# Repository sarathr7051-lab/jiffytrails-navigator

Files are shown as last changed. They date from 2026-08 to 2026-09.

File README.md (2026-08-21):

# JiffyTrails Navigator

A handlebar-mounted turn-by-turn navigation display for motorcycles. The phone
stays in your pocket and does the routing; an ESP32 device on the bars shows the
current maneuver, distance to it, and arrival time at a glance.

Built for a **Triumph Speed 400** in Bengaluru, where flyovers, service roads and
rapid successive junctions make "arrow pointing at the destination" navigation
useless.

**Status:** working prototype in progress. The navigation data pipeline is
proven; the display hardware is being brought up.

---

## Why

Nothing on the market does this for a non-Royal-Enfield bike. The RE Tripper
(~₹4,750) plugs into the RE wiring harness and pairs through the RE app, and
owner reports say it shows only direction and distance — no ETA. Beeline costs
several times more.

Target cost: under ₹4,000 including tools.

---

## How it works

```
   ANDROID PHONE  (pocket, screen off)
   Google Maps navigating normally
              │
              │  NotificationListenerService reads the ongoing
              │  navigation notification, parses it, and pushes
              │  typed packets at ~1 Hz
              ▼
          BLE GATT
              │
              ▼
        ESP32 (LOLIN32)
              │
              ▼
     2.8" ILI9341 TFT, 240×320
```

Running Maps with the screen off draws a fraction of what a mounted phone does —
on a four-hour ride that's the difference between arriving at 15% and 60%.

---

## ★ The interesting bit

Google Maps has no public API for live guidance. But on **Android 16** it uses
the **ProgressStyle / Live Updates** notification API, which exposes structured
typed extras — not the custom RemoteViews layout that older parsers had to
scrape.

This repo documents the full field mapping, a verified maneuver-icon hash table,
the distance quantisation bands, and the parser rules — all derived from real
rides, not guesswork.

See **[docs/NAV_DATA.md](docs/NAV_DATA.md)**. That's the part worth reading even
if you never build the hardware.

---

## Repo layout

| Path | Contents |
|---|---|
| `docs/NAV_DATA.md` | ★ Google Maps notification reverse-engineering — field mapping, icon hashes, parser rules |
| `docs/BLE_PROTOCOL.md` | Wire format between phone and ESP32 |
| `docs/HARDWARE.md` | Parts, pin mapping, wiring, costs |
| `docs/BUILD_PLAN.md` | Twelve-stage plan with gates and test criteria |
| `docs/PROJECT_STATE.md` | Full running state — decisions, findings, dead ends |
| `android/navdump/` | Diagnostic app that dumps and decodes nav notifications |
| `firmware/navigator/` | ESP32 firmware (in progress) |
| `hardware/mount-design.html` | Technical drawings — quarter-turn mount, sealed enclosure |
| `logs/` | Captured ride logs |

---

## Current status

**Done**
- Navigation data source proven across two real rides
- Six maneuver icon hashes confirmed with zero collisions
- Android diagnostic app working
- ESP32 toolchain verified — compiles, uploads, hash-verified

**In progress**
- Display bring-up (headers need soldering)

**Next gate**
- ★ Daylight readability test. A ~250 cd/m² TFT against 100,000 lux of Bangalore
  noon is the single biggest unknown in the project.

---

## Hardware

| Part | ~₹ |
|---|---|
| ESP32 LOLIN32 | 449 |
| SmartElex 2.8" ILI9341 TFT, non-touch | 815 |
| Breadboard + jumper wires | 204 |
| Soldering kit + multimeter | 1,000 |
| Enclosure, mount, fasteners, sealing | ~840 |
| **Total** | **~3,300** |

Deliberately excluded, with reasons in
[docs/PROJECT_STATE.md](docs/PROJECT_STATE.md): GPS module, magnetometer,
vibration motors, internal battery.

---

## Safety

This is a glanceable instrument, not something to read while riding. It is
designed so that losing the connection produces an obvious failure state rather
than a stale instruction — a navigator that confidently shows the wrong arrow is
worse than one showing nothing.

Voice guidance through a helmet headset remains the better primary channel. This
display is the confirmation layer: audio tells you *when*, the screen tells you
*what*.

---

## Licence

MIT. See [LICENSE](LICENSE).

Not affiliated with Google, Triumph, or BOBO. Notification parsing relies on
undocumented internals and may break with any Maps update.

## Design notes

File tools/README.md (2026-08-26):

# tools — testing the navigator without a phone

`navsim.py` pretends to be the Android app that does not exist yet. It connects
to the ESP32 over BLE from a Windows laptop and writes protocol packets exactly
as `docs/BLE_PROTOCOL.md` specifies, printing every packet as hex next to what
it means, so the laptop console and the ESP32 serial monitor can be read side by
side.

It never opens a COM port and never flashes anything. Keep the Arduino IDE's
serial monitor open at 115200 while it runs — that is half the test.

The acceptance tests it is built for are in `docs/STAGE5_TEST_PLAN.md`.

---

## Install

You need Python 3.9 or newer. **This machine does not have Python yet.**

1. Get it from [python.org/downloads](https://www.python.org/downloads/) —
   the "Windows installer (64-bit)".
2. During setup, tick **Add python.exe to PATH**. If you miss it, the `py`
   command below will not exist and you will have to re-run the installer.
3. Do *not* use the Microsoft Store stub. Typing `python` on a fresh Windows 11
   opens the Store instead of running anything; that is the stub, not Python.
4. Then, in PowerShell:

```powershell
py -m pip install bleak
```

`bleak` is the only dependency. It talks to the Windows BLE stack directly — no
dongle, no driver, no pairing.

Check it worked, with no hardware attached:

```powershell
py C:\dev\jiffytrails-navigator\tools\navsim.py --selftest
```

Every line should say `PASS`. This also prints the corrected version of the
worked example from `BUILD_PLAN.md` (see "The spec bug", below).

---

## Find the device first

```powershell
py navsim.py --scan
```

This lists everything advertising nearby. The ESP32 advertises as
**`JiffyTrails`** (`DEVICE_NAME` in `navigator.ino`), which is what every other
mode matches by default. If the firmware advertises something else, add
`--name <name>` or `--address <address>` to any command below.

**Do not pair the ESP32 in Windows Bluetooth settings.** This protocol needs no
pairing, and a stale Windows pairing is the most common reason a connect starts
failing after it previously worked. If it shows up under Settings → Bluetooth &
devices, remove it.

Only one central can be connected at a time. Close nRF Connect on the phone
before running the laptop tool, and vice versa.

---

## The modes

Run everything from this folder, or give the full path to the script.

### `--ride` — the one that matters

```powershell
py navsim.py --ride
```

Replays a scripted Bengaluru route at 1 Hz: eight legs, about 6 km, roughly ten
minutes. It uses the real Google Maps behaviours from `docs/NAV_DATA.md`, not a
tidy simulation:

- **Distances are quantised** — 100 m steps above 1 km, 50 m from 1 km down to
  300 m, 10 m below 300 m.
- **Values are rounded to the band, not stepped through it**, so at speed the
  digits *skip*: 290 → 270 → 250 → 230. This is deliberate. A smooth countdown
  would flatter the display and hide the flicker that actually matters.
- **The remaining distance drifts** by a few percent every packet, because
  `progressMax` does. It must be recomputed on every packet, never cached.
- **`next_maneuver` is always UNKNOWN/0**, because Google Maps does not expose
  a next maneuver. Anything the display does with that field must survive it
  being empty forever.
- A **rerouting** state fires on leg 4 and a **gps_weak** state on leg 6.
- The route ends with an explicit **`nav_active = 0`**. Silence is ambiguous;
  "not navigating" is not.

Useful flags:

| Flag | Effect |
|---|---|
| `--speed-mult 4` | Ride four times faster. Same 1 Hz packet rate, so the digits skip much harder — the worst case for the distance field |
| `--reconnect` | Rescan and reconnect if the link drops, and time the recovery. This is the laptop half of the walk-30-m-away test |
| `--seed 1234` | Change the jitter. The same seed always replays identically |
| `--dry-run` | Print the packets without touching Bluetooth |

**Correct behaviour:** every packet on the laptop console has a matching line on
the ESP32 serial. The distance on the panel matches the `dist=` field in the
decoded line. During the reroute the screen says REROUTING and **no arrow is
drawn**, even though the packet still carries `maneuver=ROUNDABOUT`. At the end
the panel drops to the idle screen and keeps no trace of the last maneuver.

### `--screen <name>` — hold one state for a photograph

```powershell
py navsim.py --screen now
```

Holds a single state at 1 Hz indefinitely, so the watchdog stays quiet and you
can photograph the panel at arm's length. Ctrl+C to stop.

| Name | State |
|---|---|
| `far` | 1.2 km — instruction, medium distance, ETA, remaining km |
| `approach` | 350 m — distance large, arrow large |
| `committed` | 80 m — full-screen arrow and distance, nothing else |
| `now` | 20 m — inverted colours |
| `idle` | `nav_active = 0` — clock and trip stats, never a maneuver |
| `rerouting` | REROUTING, arrow suppressed |
| `gps_weak` | Normal nav screen plus a small corner warning |
| `arrived` | Destination reached |
| `unknown` | Maneuver `0x00` — must render `?`, never a guessed arrow |
| `longtext` | The 59-character instruction observed in the wild |
| `roundabout` | Reserved code `0x23` (roundabout, exit 3) |
| `battery` | A STATUS packet — must not disturb the nav screen |
| `trip` | A TRIP packet |

**Correct behaviour:** anything you cannot read in half a second at arm's length
is too small. That is the actual test.

### `--stale` — prove the 10 s watchdog fires

```powershell
py navsim.py --stale
```

Sends normally for ten seconds, then stops dead **while staying connected**, and
counts the seconds out loud. After 25 s it starts sending again.

**Correct behaviour:** the panel dims and shows STALE about 10 s after the last
packet. It must **not** show PHONE DISCONNECTED — the link is still up, and
confusing a dead link with dead data is a failure. When packets resume, the nav
screen returns within one packet, with no reset and no button press.

This is the test that catches a change-based watchdog. `NAV_DATA.md` measured
64 seconds with no field changing at all while Maps kept posting at 1 Hz, so the
watchdog must count packet *arrivals*.

### `--flood` — tearing and heap growth

```powershell
py navsim.py --flood
```

Sends at 20 Hz for 30 seconds — roughly twenty times the real rate — with values
that change on every packet, then settles back to 1 Hz. Tune with
`--flood-rate` and `--flood-seconds`.

**Note the ESP32's free heap before and after.** A few hundred bytes of jitter is
normal; a steady downward slope is a leak in the packet handler.

**Correct behaviour:** no torn digits, no half-drawn arrow, no reset, no heap
trend. Dropping packets under flood is fine — the display cannot usefully redraw
at 20 Hz anyway — but it must never render a partial frame. Afterwards the panel
settles to a clean, steady screen.

### `--garbage` — malformed input

```powershell
py navsim.py --garbage
```

Sends every malformed packet in the tool's list, a second and a half apart:
empty writes, truncated payloads, a length byte that lies in both directions,
unknown packet types, a 200-byte instruction against a 64-byte buffer, invalid
UTF-8, an embedded NUL, an undefined maneuver code, and 256 bytes of noise. It
starts from a known-good screen and **ends with a valid packet**.

**Correct behaviour:** the ESP32 does not reboot, the BLE link stays up, free
heap is unchanged, and the final valid packet renders correctly. That last one
is the real test — a parser that rejects everything afterwards has failed just
as badly as one that crashes.

Each packet's `EXPECT:` line says whether it should be rejected or accepted, so
read those rather than assuming every case leaves the screen alone. Two of them
are *supposed* to be accepted: the current firmware treats the `len` byte as
advisory and bounds every read by the ATT write length instead, so a `len` that
undercounts is tolerated while a `len` that overcounts is dropped. The safety
property under test is that nothing is ever read past the end of the write.

The undefined maneuver code must render `?`. A confidently wrong arrow is worse
than no arrow.

### `--nrf` — hex strings for the phone

```powershell
py navsim.py --nrf
```

Prints the packets as hex, with decodes, ready to paste into nRF Connect's write
field. No Bluetooth is used, so this works on any machine. Same strings as
`docs/STAGE5_TEST_PLAN.md`.

### `--selftest` — check the tool, not the firmware

```powershell
py navsim.py --selftest
```

Encoding and decoding round trips, the quantisation bands, and every named
screen — all offline. Run this after changing the script, and before blaming the
firmware for anything.

---

## Reading the output

```
14:22:07.412 TX  26B  01 18 03 64 00 02 50 00 0C 00 20 00 01 4F 6C 64 20 4D 61 64 72 61 73 20 52 64
             NAV len=24 maneuver=TURN_RIGHT(0x03) dist=100 m next=UNKNOWN(0x00)/0 m eta=12 min remaining=3.2 km flags=0x01[nav_active] instr="Old Madras Rd"
             EXPECT: UI_NAV_COMMITTED - full-screen arrow + distance, nothing else
```

- `TX` is laptop → ESP32, `RX` is a notification coming back.
- The decode line is what the bytes *say*. Compare it with the ESP32 serial
  line for the same instant — they must agree field for field.
- The `EXPECT` line is what the panel should be showing, derived from
  `screenFor()` in `firmware/navigator/nav_types.h`. If the decode is right and
  the panel disagrees with EXPECT, the bug is in the display, not the parser.

---

## The spec bug

`docs/BUILD_PLAN.md` Stage 5 gives this worked example:

```
01 0F 03 64 00 02 50 00 0C 00 20 00 01 + "Old Madras Rd"
```

**The field order and every value in it are correct. The length byte is not.**

The NAV payload is 11 fixed bytes (`u8 + u16 + u8 + u16 + u16 + u16 + u8`) plus
the 13-byte instruction — 24 bytes, `0x18`. The example says `0x0F`, which is
15, and matches neither the 11 bytes printed after it nor the 24 the packet
actually carries. Corrected:

```
01 18 03 64 00 02 50 00 0C 00 20 00 01 4F 6C 64 20 4D 61 64 72 61 73 20 52 64
```

Everything in this folder and in `docs/STAGE5_TEST_PLAN.md` uses the corrected
form. Details in the test plan.

---

## When it does not work

| Symptom | Cause |
|---|---|
| `'py' is not recognized` | Python is not installed, or PATH was not ticked during install. Re-run the installer |
| `python` opens the Microsoft Store | That is the Store stub. Install real Python from python.org |
| `bleak is not installed` | `py -m pip install bleak` |
| `no BLE device matching 'JiffyTrails'` | Wrong name — run `--scan` and pass `--name`. Or the ESP32 is not advertising: check its serial output. Or something else is already connected to it |
| Scan finds nothing at all | Bluetooth is off. Toggle it off and on once; the Windows BLE stack gets stuck |
| Connects, then "navigator service was not found" | The ESP32 is running different firmware, or the UUIDs in `ble.cpp` do not match `docs/BLE_PROTOCOL.md` |
| Connect worked yesterday, fails today | Windows cached a pairing. Settings → Bluetooth & devices → find it → Remove device |
| Everything stalls after a few minutes | Something else grabbed the adapter. Close nRF Connect for Desktop |

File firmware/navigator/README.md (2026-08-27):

# ESP32 firmware

**Status: display bring-up COMPLETE (22 Aug 2026).** Panel renders graphics and
text correctly through all rotations. Firmware itself not yet written.

## Setup

`User_Setup.h` here is a reference copy. The live file the compiler actually
reads is `<sketchbook>/libraries/TFT_eSPI/User_Setup.h`, and on this machine
the sketchbook is **`C:\dev\Arduino`** — see the sketchbook section in
`docs/HARDWARE.md` before editing anything, including the OneDrive decoy that
wasted a session.

Working configuration:

| Setting | Value |
|---|---|
| Driver | **`ILI9341_2_DRIVER`** (not `ILI9341_DRIVER`) |
| SPI_FREQUENCY | **27000000** on breadboard |
| CS / DC / RST | 15 / 2 / 16 |
| MOSI / SCLK / MISO | 23 / 18 / 19 |

Verify with **Examples → TFT_eSPI → Test and diagnostics → Read_User_Setup**
before anything else. It prints back what the compiler actually used, which
catches a mistyped pin or a wrong-file edit in seconds. Then
**Examples → TFT_eSPI → 320 x 240 → TFT_graphicstest_one_lib**.

Note Read_User_Setup prints inside `loop()`, so the output repeats forever —
that is normal, not a boot loop. One cycle ends at `[/code]`.

## White screen checklist

In order of likelihood, learned the hard way:

1. **You edited a `User_Setup.h` that isn't the one being compiled.** Check
   `directories.user` in `~/.arduinoIDE/arduino-cli.yaml`, then confirm with
   Read_User_Setup that a value you changed actually changed. Everything below
   is a waste of time until this is ruled out.
2. Wrong init sequence — try **`ILI9341_2_DRIVER`**. Flat white or vertical
   stripes with correct pins is the signature. Note the printed driver ID stays
   `9341` either way, so verify via the SPI frequency line instead.
3. RESET wired to GPIO 4 instead of **16**
4. SPI too fast for breadboard — drop to **27 MHz**
5. A jumper not fully seated — swap the suspect wire before touching config
6. Unsoldered or cold headers. SPI will not tolerate a marginal contact even
   though DC power gets through fine

## Planned structure

```
navigator.ino     entry, setup, main loop
ble.cpp           NimBLE peripheral, packet parse, reconnect
display.cpp       screen states, distance bands, failure states
maneuvers.cpp     vector arrow drawing
watchdog.cpp      stale detection — counts arrivals, not changes
ota.cpp           WiFi OTA — must work before the case is sealed
```

Use TFT_eSPI **sprites for the distance field only**. A full-screen sprite
won't fit in plain ESP32 RAM.

Draw maneuver arrows as **vector paths**, not bitmaps — scalable, and a fraction
of the flash.

## Related sketches

`../sunlight_test/sunlight_test.ino` — Stage 4 Test B. Cycles the six real UI
states so daylight readability can be judged against the actual design rather
than the library graphics test, which draws thin coloured lines on black and is
close to a worst case.

`../ui_mock/ui_mock.ino` — the nav interface driven by a scripted ride, no BLE.
Distances count down at 1 Hz with the real Google Maps quantisation, maneuvers
change, and every failure state fires on a timer. Serial keys jump straight to
any state. This is where the interface gets finalised before BLE work starts;
its drawing code becomes `display.cpp`.

---

## Stage 5 — known limitations and landmines

Written down 26 Aug 2026 while the BLE link was built. None of this is blocking;
all of it will cost an evening if rediscovered.

**Packet parsing runs on a different task from rendering.** NimBLE delivers
writes on its host task; `displayRender()` reads `NavState` on the loop task.
There is no lock, so a render can in principle catch a half-updated
`instruction[]`. At 1 Hz the window is tiny and the next frame corrects it, so
the visible worst case is one frame of garbled road name. **If it ever matters,
the fix is to stage the raw frame bytes in `onWrite` and parse them in
`bleTick()`**, moving all mutation onto the loop task. Left as-is for now
because untested restructuring is a worse risk than a one-frame cosmetic fault.

**xtensa gcc 14 (esp32 core 3.3.11) ICEs on a specific construct.** A
namespace-scope function-pointer type that names a class from an *anonymous*
namespace crashes the compiler with a segfault — it appeared as a failure on
`struct PacketHandler` with no useful diagnostic. `PacketReader` is therefore at
file scope rather than in an anonymous namespace. Do not "tidy" it back.

**`NavState.linkUp` has exactly one writer: `watchdogTick()`.** It derives the
value from `bleConnected()` once per loop because it needs the
disconnected→connected *edge* to restart the freshness clock. `ble.cpp`
deliberately does not set it — an earlier version did, which consumed the edge
and silently made the reconnect branch dead code.

### Regressions against `ui_mock`, both from missing protocol rows

- **No traffic bar.** Needs `0x07 TRAFFIC` specified and a `NavState` field.
- **Idle screen shows "READY", not a clock and trip stats.** Needs a time source
  and `0x05 TRIP`. A fabricated clock on a handlebar is worse than none.

### Maneuver glyphs that are approximations

SHARP_LEFT/RIGHT draw as ordinary turns; KEEP, FORK and EXIT all draw as slight
turns — correct side, less specific meaning. FLYOVER, UNDERPASS and FERRY render
`?` on purpose: Maps emits no icon for them (NAV_DATA.md), so they can only
arrive from an unvalidated source, and a CONTINUE arrow would be a confident
claim that the road runs straight through. Roundabout exits `0x20`–`0x2F` draw
the ring plus the exit **number**, because exit angles are not evenly spaced and
a generic exit stub would point the wrong way.

## Two sketches

**`firmware/navigator/`** is the real thing: the phone drives it over BLE.

**`firmware/ui_mock/`** is the same display with no phone and no radio. It boots
straight into a scripted ride from Panampilly Nagar to Fort Kochi Beach and
loops it — distances count down at a real speed, the screen crosses every band,
every maneuver glyph appears, and the route ends on the arrival screen before
starting again. Useful for judging the interface at mount distance without
pairing anything, and it is half the flash because there is no BLE stack.

Both accept the same serial keys at 115200:

| key | |
|---|---|
| `r` | the scripted ride |
| `g` | glyph parade — every maneuver, named as it draws |
| `a` | alerts — call and message, riding and parked |
| `b` | replay the boot sequence |
| `x` | stop (in `navigator`, hands the display back to the phone) |

### Keeping them in sync

`firmware/ui_mock/src/` holds **generated copies** of the shared sources. Do not
edit them. After changing anything in `firmware/navigator/`:

```
perl tools/sync_ui_mock.pl
```

and `perl tools/sync_ui_mock.pl --check` fails if they have diverged.

Copies rather than includes because arduino-cli *and* the IDE both copy a sketch
into a build directory before compiling, so a relative `#include` pointing
outside the sketch resolves against the copy and finds nothing.

This matters more than it looks. The previous `ui_mock` was a hand-maintained
second implementation of every screen, and it drifted until it had nine
maneuvers, an enum where left was `MV_LEFT`, and a traffic bar the firmware had
removed — a mock showing a UI the device no longer had. The copies are
mechanical and the check makes drift an error instead of something you discover
on the panel.

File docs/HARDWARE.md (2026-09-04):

# Hardware

## Bill of materials

| Part | Detail | ₹ |
|---|---|---|
| ESP32 **LOLIN32** | USB-C, CH340 USB-serial | 449 |
| **SmartElex 2.8" TFT** | ILI9341, SPI, 240×320, **non-touch** | 815 |
| MB102 breadboard | 830 points | 65 |
| Jumper wires | M2M / M2F / F2F, 20 each | 139 |
| Soldering kit + multimeter | 60 W adjustable, pump, wick, flux, stand | 1,000 |

### Still to buy — ★ REWRITTEN 1 Sep 2026, THE OLD LIST BOUGHT THE WRONG PARTS

The line here used to read "polycarbonate window, clear RTV, M8 cable gland,
M3/M4 fasteners, anti-glare film, PETG filament". **Three of those parts are not
in the design and three that are were missing.** Against `hardware/case.scad`:

| Part | Detail | Why |
|---|---|---|
| **ASA filament, light coloured** | **not PETG, never PLA** | PETG's HDT is 65–80 °C against a sealed interior estimated at 53–70 °C in Bengaluru sun. See the Enclosure section. |
| **Closed-cell EPDM foam tape, 3 mm** | 4 mm wide, closes to 2 mm = 33% compression | The seal. `foam_w = 4.0`, `foam_d = 2.0`. ★ **Closed-cell, NOT open-cell polyurethane** — most cheap foam tape is open cell and wicks like a sponge. Test it: hold a piece under water and squeeze. Open cell streams bubbles and stays wet. |
| **M3 self-tapping screws** | **8 × M3 × 14** (cap → lid → body), **2 × M3 × 5** (hood) | ★ **REWRITTEN 3 Sep 2026 for the bayonet mount** — the line above used to say 8 × 12, 4 × 8 and 2 × 6, and all three were for the dovetail. The eight now run through **three** parts as one fastener set: 2.4 mm of mount cap under its counterbore, 5.0 mm of lid, then a 2.5 mm pilot 9.0 mm blind into the body. ×14 gives 6.6 mm of thread and never bottoms; ×12 gives 4.6 and ×16 is 0.4 mm from the floor. ★ **PAN head** (DIN 7981, 5.6 × 2.4), not socket cap: the cap's counterbore is 2.6 mm deep and a DIN 912 cap head is 3.0 mm tall, so it stands proud into the collar. ★ **The hood's two are ×5, NOT ×6** — `hood_pilot_len` is 4.0 mm blind over a 2.0 mm floor and a ×6 bottoms out before the hood is tight. ★ **There is no mount plate any more**; its 4 × M3 × 8 are deleted. Measured off the printed geometry, not the drawing: cap, lid and body carry the same eight positions, verified by solid intersection. |
| **M3 brass heat-set insert** | 1, for the mount adapter | The BM4's screw runs socket → plate into a brass insert, so our part carries the female thread. `MOUNT_INTERFACE.md` §3. ★ **Not for the case** — `case.scad` rejects inserts there: they need a 4.0 mm bore and 1.6 mm of wall either side, costing 2.4 mm of envelope in both directions, and eight iron-driven insertions into a part that cannot be reprinted. |
| **ePTFE membrane, Ø6 vent** | can be cut from an old rain jacket | Free |
| **Potting compound** | clear RTV or epoxy, for the cable entry | ★ **No cable gland.** See below. |
| **USB-C cable, ≤ Ø4.5 mm** | thin, right-angle at the bike end; the far plug is cut off and soldered inside | ★ `cable_bore_d = 4.5` and the case is printed. A braided cable is 5–6 mm and will not go through. Measure with a paper strip: circumference ÷ 3.1416. |
| **Power protection** | SMBJ6.0A TVS, 220 µF hybrid/polymer 16 V, 100 nF ceramics, ferrite bead, 1 A polyfuse | `FEATURES.md` "Decision: cable power, no battery". ★ 6.0A not 5.0A. ★ Polymer, not 85 °C electrolytic. |
| **USB power meter** | inline, cheap | Answers whether the Speed 400's socket is ignition-switched or always live, and its real current. Nobody has measured either. |
| Anti-glare film | cut from a phone screen protector | Sunlight section |

**Deleted, and do not buy:**

- **M8 cable gland** — ★ the entry is **potted**. An M8 gland's Ø14 locknut needs
  16 mm of clear flat wall on the inside, in a position this case does not have.
- **Polycarbonate window** — ★ **there is no separate window.** The front is
  closed and the panel is bonded behind it; `bezel()` does the precise work. A
  window with an air gap in front of the panel is also the wrong answer
  optically — see the Enclosure section.
- **M4 fasteners** — nothing in `case.scad` or `mount_v4.scad` uses M4. The only
  bolt in the whole mount is the BM4's own ISO 10642 M3 × 10 countersunk, which
  you already have. (`mount.scad`, which carried an M4 rule, is the abandoned
  dovetail design and is not what is printing.)

**Deliberately excluded:** GPS module, magnetometer, vibration motors, internal
battery. Reasons in PROJECT_STATE.md.

## Pin mapping

**Status: VERIFIED WORKING 22 Aug 2026.** `TFT_graphicstest_one_lib` renders
correctly through all rotations on this wiring.

| Display | LOLIN32 |
|---|---|
| VCC | 3V |
| GND | G |
| CS | GPIO 15 |
| RESET | **GPIO 16** |
| DC | GPIO 2 |
| SDI (MOSI) | GPIO 23 |
| SCK | GPIO 18 |
| SDO (MISO) | GPIO 19 |
| LED | **GPIO 17** |

### Gotchas

**★ LED goes to GPIO 17, NOT to 3V3.** This table said `3V` until 29 Aug 2026
and it was wrong - `backlight.cpp` has owned GPIO 17 through the LEDC PWM
peripheral since the day/night dimming went in. Wiring LED to 3V3 leaves the
backlight stuck at full brightness with no dimming. Wiring it to BOTH - which
is what someone following the old table *and* the firmware would do - shorts
3V3 to ground through GPIO 17 every time the firmware dims, and that damages
the pin. One wire, to GPIO 17.

**RESET is GPIO 16, not 4.** GPIO 4 is not broken out on the LOLIN32. Most
ILI9341 tutorials say 4, and following them gives you a white screen.

**No series resistors.** The vendor manual specifies 10 K on every signal line
and 5 V on VCC — that is for a 5 V Arduino. The ESP32 is natively 3.3 V; wire
straight through.

**3.3 V is sufficient** despite the module carrying an AMS1117 regulator.
Verified on the bench: **3.18 V measured at the `3V` pin with the backlight
lit** (22 Aug 2026, DT-830D on DCV 20). A 4 % droop off nominal — fine, but
that is the LDO working rather than coasting. Re-measure if anything else is
ever added to the 3.3 V rail.

### ★ Backlight control — GPIO 17, PWM, and NO EXTERNAL TRANSISTOR

★ This section used to open "`LED` is tied straight to `3V`, the backlight is
therefore always on at full brightness". **Both halves are stale.**
`backlight.cpp` has driven GPIO 17 through the LEDC PWM peripheral (20 kHz,
10-bit) since day/night dimming went in, and the pin table above is the wiring.

★ It also said `User_Setup.h` "reserves `TFT_BL 17` and `TFT_BACKLIGHT_ON HIGH`,
commented out, for when this changes". **Those two defines must STAY commented
out, and not by oversight.** Defining `TFT_BL` makes TFT_eSPI drive the same pin
during init, and two owners on one GPIO fight: the library's plain
`digitalWrite` tears down the LEDC channel `backlight.cpp` attached. The
backlight is not TFT_eSPI's job in this build.

**★ CORRECTED 29 Aug 2026 — no external switch is needed. The module already
has one.**

This section used to say the LED pin was the backlight supply, that it drew
60–100 mA, and that it therefore needed an added MOSFET or an NPN. The
[LCDWIKI MSP2807 schematic][msp2807sch] says otherwise, traced net by net:

```
3.3V ──> LEDA ─[4 white LEDs in parallel]─ LEDK ──[R5 10R]──┐
                                                  collector ┴
  header "LED" ──[R6 1k]── base ────────────────►  Q1  S8050 (NPN)
                                                    emitter ┬
                                                           GND
```

The LED pin is **a logic-level control input to an on-board low-side NPN**, not
a supply rail. That is why the wiki describes it as "high level lighting". The
current an ESP32 pin actually sources into it is base current:

```
(3.3 - 0.7) / 1000 = 2.6 mA
```

against a 40 mA absolute maximum. **Wire GPIO 17 straight to the LED pin and
PWM it.** No transistor, no gate resistor, no pulldown. `backlight.cpp` needs
no change — it was already only ever driving a pin.

The 60–100 mA figure was right about the *panel* (QD-TFT2803: Vf 3.2 V, If
60 mA nominal, 80 mA max) and wrong about this *module*, which runs those LEDs
off 3.3 V through a 10 Ω series resistor — so somewhere near 15–40 mA. Worth
knowing for the sunlight problem: **this backlight is already running well
under its rated current.**

★ **Confirm it in ten seconds before soldering, because this family of boards
is not consistent** — some genuinely do bring the LED supply straight out, and
Adafruit's own 2.8" breakout has a transistor while other sellers' do not. Put
a **1 kΩ resistor in series** between 3.3 V and the LED pin:

- backlight stays at **full brightness** → there is a transistor, drive it from
  the GPIO as above
- backlight goes **almost dark** → the pin is the LED supply after all, and the
  old advice applies: fit a 2N7000 low-side switch

[msp2807sch]: https://www.lcdwiki.com/res/MSP2807/MSP2807-2.8-SPI.pdf

**The `+` beside the white connector is the LiPo JST terminal**, not a 5 V
header pin. `VP` and `VN` are GPIO 36 and 39, analog inputs — not power.

**The USB chip is CH340, not CP2102**, despite what some listings say. Windows
has a built-in driver; no install needed.

If the module exposes touch pins, leave them unconnected except **T_CS → 3.3 V**
so the touch controller stays off the shared SPI bus.

**This panel needs `ILI9341_2_DRIVER`, not `ILI9341_DRIVER`.** Same chip ID,
different init sequence ([TFT_eSPI issue 1172][1172]). Under the stock
`ILI9341_DRIVER` this display gave flat white, then vertical stripes once the
pins were corrected — the controller was receiving SPI but never initialising.
The alternative sequence brought it up first try. A second panel from a
different batch may want the other one; try both before assuming a fault.

[1172]: https://github.com/Bodmer/TFT_eSPI/issues/1172

**Run the bus at 27 MHz on breadboard**, not the 40 MHz default. Dupont jumpers
and an MB102 do not hold 40 MHz cleanly. Worth raising again once the build is
soldered — but retest, do not assume.

Worth knowing why 27 is a sensible fallback rather than an arbitrary one:
**27 MHz is TFT_eSPI's documented ceiling for *reading back* from the display**,
not for writing. For write-only rendering the library's own guidance is that
"40MHz seems to be OK with ILI9341 displays", with 80 MHz the point where the
controller starts failing. So 40 MHz should be reachable once the wiring is
soldered — **48% more bandwidth**, which matters directly for moving graphics.

★ **CORRECTED — THE FIRMWARE DOES READ THE PANEL, AND READS HAVE THEIR OWN
CLOCK.** The reasoning above used to close with "since this project never calls
`readPixel`". That is no longer true. `display.cpp` runs a boot probe
(`panelReadable`) and re-reads `MADCTL` twice every two seconds; **that watchdog
is the one mechanism that can recover the mirrored-screen fault**, and it
disarms itself if the reads come back as garbage.

Reads and writes are separately clocked, which is what makes raising the write
clock safe:

```
User_Setup.h    SPI_FREQUENCY       27000000   writes  <- raise this to 40 MHz
                SPI_READ_FREQUENCY   6000000   reads   <- LEAVE THIS ALONE
```

**6 MHz, not 20.** MISO is wired, yet at 20 MHz the boot probe kept returning
garbage and disarming the watchdog — so the recovery mechanism was switched off
by a number, not by a missing wire. Reads happen twice every two seconds and
their speed is worth nothing.

**Check the boot line before and after any SPI change.** If it says "watchdog
armed", the watchdog is real and a corrupted MADCTL heals itself within six
seconds instead of persisting until a power cycle. If it says "DISABLED", the
read clock is too fast or MISO is not connected.

For reference, a 320×240 RGB565 frame is 153,600 bytes = 1,228,800 bits:

| SPI clock | Wire time per full frame | Theoretical max FPS |
|---|---|---|
| 27 MHz | 45.5 ms | 22.0 |
| 40 MHz | 30.7 ms | 32.6 |

Measured TFT_eSPI `fillScreen` on ESP32 + ILI9341 at 40 MHz comes in at 31.2 ms
— about 98% of theoretical, which confirms the SPI wire is the wall and the
ESP32 can saturate it.

## Toolchain

Arduino IDE 2.x **from arduino.cc** — not the Microsoft Store build, which is
1.6.11 from 2016 and sandboxed.

Boards Manager URL:
```
https://raw.githubusercontent.com/espressif/arduino-esp32/gh-pages/package_esp32_index.json
```

Board: **WEMOS LOLIN32**.

### Upload from the Arduino IDE, not the command line

Sketches flashed with `arduino-cli` reported a clean write and verified hash,
the sketch ran and printed to serial — and the panel stayed white. The same
sketch uploaded through the IDE worked immediately, with nothing physical
changed in between. The board options are identical between the two
(`CPUFreq=240`, `FlashFreq=80`, same partition scheme), so the cause is not
board configuration and has not been pinned down.

Probable culprit: opening the serial port from a script toggles DTR/RTS, which
on this board drives the auto-reset circuit (EN and GPIO 0). That can leave the
ESP32 held in reset or sitting in download mode — the sketch is in flash and
appears fine, but nothing drives the display.

**Practical rule: upload through the IDE, and don't open COM11 from a script
while debugging the display.** An hour was lost to this, chasing a wiring fault
that did not exist.

### Sketchbook location — read this before editing any config

**The sketchbook on this machine is `C:\dev\Arduino`.** The live TFT_eSPI
config is therefore:

```
C:\dev\Arduino\libraries\TFT_eSPI\User_Setup.h
```

That is authoritative, not a guess — it is `directories.user` in
`C:\Users\sarat\.arduinoIDE\arduino-cli.yaml`. **Check that file rather than
trusting an assumed Documents path.**

**The trap that cost a full session:** OneDrive's Documents folder here is
localized to Japanese and is literally named `ドキュメント`. A second, stale
TFT_eSPI lives at

```
C:\Users\sarat\OneDrive\ドキュメント\Arduino\libraries\TFT_eSPI\
```

`%USERPROFILE%\Documents` contains no Arduino folder at all, so anything
reasoning about "Documents\Arduino\libraries" lands on the OneDrive copy — which
is never compiled. Every edit went there and changed nothing, which made two
correct fixes look like failures. **That copy is dead. Do not edit it.** Delete
it if you want the trap gone for good.

`firmware/navigator/User_Setup.h` in this repo is a reference copy; keep it in
sync with the live file by hand.

**Always confirm an edit landed before drawing conclusions from it.** Run
Read_User_Setup and check a value you know you changed. Note that swapping
`ILI9341_DRIVER` for `ILI9341_2_DRIVER` does *not* change the printed driver ID
— both report `9341`. Verify against `Display SPI frequency` or a pin instead.

## ★★ Sunlight readability — do the arithmetic before the test

Researched 22 Aug 2026, ahead of running Stage 4 Test B. **The numbers say a
bare ILI9341 fails in direct Bengaluru noon sun.** Worth knowing before the
test rather than being surprised by it.

### The governing equation

Glare is not subtractive, it is *additive light* laid over the whole panel:

```
L_reflected = E × R / π          E = ambient lux, R = front-surface reflectance
ACR = (L_white + L_reflected) / (L_black + L_reflected)
```

Readable text needs **ACR ≥ 5:1**. Maps and detail want 10:1.

### This panel, this city

Bengaluru clear-sky noon is **~100,000 lux**. A generic ILI9341 module has a
glossy overlay with an air gap, so R ≈ 4.5%.

```
L_reflected = 100000 × 0.045 / π ≈ 1430 nits of grey haze
ACR = (250 + 1430) / 1430 ≈ 1.17 : 1
```

Against a requirement of 5:1. **That is not marginal, it is a grey rectangle.**
Practitioner reports of ILI9341 outdoors agree — washed out, unreadable.

Note what the equation says about mitigation: **cutting ambient light beats
raising backlight.** A 5× reduction in E from a hood does more than a 4×
brighter backlight, and costs a 3D print. Even a 1000-nit panel behind the same
cheap air-gapped front only reaches 1.7:1 — commercial units optically bond and
AR-coat down to ~1% reflectance to get anywhere.

Measured brightness for these modules, where published at all: Winstar
500 cd/m², POLCD ~300, TST28011T 275. Most listings publish nothing.

### Mitigations, cheapest first

1. **Free — rotate the panel 90° and test with the sunglasses you ride in.**
   See the polariser note below. Do this before the enclosure is designed.
2. **₹150–400 — a deep matte-black hood**, 25–35 mm, ribbed or flocked inside.
   Biggest single win available. Attacks E directly.
3. **₹150–300 — matte anti-glare film** cut from a phone screen protector,
   applied *directly to the panel*. AG diffuses rather than eliminating, and
   softens the image — irrelevant when the content is a giant arrow.
4. **Free — the single-glyph layout.** Everything converges to grey in glare, so
   contrast has to come from area and shape, not colour. Never encode anything
   load-bearing in colour alone. This is already the design.
5. **Mount angle** — a screen tilted face-up mirrors the sky. Tilt it toward the
   rider, away from the zenith.

### ★ Polarised sunglasses will black this out, and the fix is free

Every LCD emits **linearly polarised** light. Polarised sunglasses are a linear
polariser. Cross the two at 90° and the screen goes **completely black** — and
it is head-angle dependent, so it comes and goes while riding.

Consumer panels put the polariser axis vertical or horizontal, so **rotating the
module 90° in the enclosure rotates its axis 90°** and can flip it from
invisible to fully visible through polarised lenses.

**This is the highest-value free experiment in the project. Test both
orientations with your own riding sunglasses before the housing is finalised.**

Two things not to do:
- **Do not add a linear polariser sheet** as a DIY anti-glare measure. It either
  halves the brightness or creates the exact blackout it is meant to prevent.
- **A circular polariser (quarter-wave retarder) is the proper fix** but absorbs
  a large fraction of emitted light. At 250 nits that is unaffordable. Only
  viable on a bright panel.

### Plan B, budgeted from the start rather than treated as failure

If hood + film + layout still is not enough at 13:00 on a clear day, the answer
is a part swap, not more mitigation:

| Option | Cost | Trade |
|---|---|---|
| **Sharp Memory LCD 2.7" 400×240** (Adafruit 4694) | ~$45 | **Reflective — gets brighter as the sun does.** ~20% reflectivity in 100k lux ≈ 6400 nits equivalent white. Near-zero power, LCD-speed refresh, 13.5 KB framebuffer fits ESP32 easily. Monochrome, and needs a front light at night. **This is what Garmin Edge and Wahoo use, and why they never publish a nits figure.** |
| 1000-nit sunlight-readable 2.8" IPS 240×320 (Orient Display / Newhaven / Chenghao) | ₹1,500–4,000 + import | Drop-in for the SPI code and keeps colour. Heavy backlight current. Still needs the hood — 1000 nits alone does not solve it. |

A turn arrow and a distance number do not need colour. The Memory LCD is
arguably the technically correct part for this job and always was.

### Calibration point in our favour

**Beeline Moto II publishes no nits figure at all and is widely reported as
readable in bright sun.** Reviewers credit the tiny 1.45" screen, extremely high
contrast, anti-glare coating and auto-backlight — not raw brightness. The design
lever matters as much as the panel.

## Mount

Reuses a **BOBO BM4** phone mount: handlebar clamp → **Ø17 mm ball** (VERIFIED)
→ collet + collar → socket → phone plate.

★ **THE JAW BROKE. THE PLATE DID NOT.** This section used to say "the copper jaw
plate (the part that broke) is discarded". Only the **jaw** — the sprung grip
that holds a phone — failed, and the jaw is not used here. **The plate is
undamaged and is kept**: it is the measurement reference for the interface, and
the fallback if a printed part disappoints.

★ **THE MOUNT IS NOT METAL.** The socket and the plate are both polymer. **The
only metal in the whole mount is one ISO 10642 M3 × 10 countersunk screw.**

The printed adapter takes the plate's place in the stack, which means it has to
reproduce the plate's own interface to the socket:

- a **square cavity** — ★ CORRECTED 2 Sep 2026: the socket's square
  **protrudes** 2.0 mm and the plate's is the recess, not the other way round.
  Ours is 14.5 mm across flats, 2.42 mm corner radius, **2.20 mm deep** — deeper
  than the boss is tall, so our flat face seats on the socket's flat face and the
  square only keys rotation. It also puts the seating face flat on the print bed
  as the first layer, which is why it needs no support;
- an **M3 brass heat-set insert** on the centre line. The screw runs socket →
  plate, so **our part carries the female thread.** This withdraws the earlier
  project rule "no thread in printed plastic" — a brass insert is what BOBO
  themselves did, for the same reason;
- **no 90° countersink** — the screw head lands on the socket, not on us.

Full measurements and the reasoning: **`docs/MOUNT_INTERFACE.md`**, which
supersedes `COMPONENT_DIMENSIONS.md` §3 and the narrative in
`hardware/mount.scad`.

★ **The dovetail is gone too. The joint is a quarter-turn bayonet** —
`hardware/mount_v4.scad`, superseding `mount.scad`, `mount_v2.scad`,
`mount_v3.scad` and `dovetail.scad`, which remain only as history. Three lugs
on a central boss drop through three slots in the adapter's collar, a **55°**
twist takes them under a flat shoulder, a printed spring blade drops a tooth
into a notch, and hard stops arrest it 3° past the lock. One lug is 48° wide
against 44° slots so it goes on exactly one way. Release is a firm twist,
around 0.4 N·m — the retaining flanks are ramped at 60° because the release
tab sits under the cap where no finger can reach it. Verified in two geometry
kernels (CGAL and OCCT): 0.000 mm³ interference locked, 244 mm³ against a 3 mm
lift, and the spring at 1.26 % root strain over its real 18.5 mm free length.
The full record is in the git history of 3 Sep 2026 and the review pages it
links.

The rider's case pockets when parked and the adapter stays on the bike; the
same eight screws that seal the lid also fix the cap, so mount load never
passes through the foam seal.

## Enclosure

★ **REWRITTEN 1 Sep 2026. EVERYTHING THIS SECTION USED TO SAY DESCRIBED THE
ABANDONED FRONT-OPENING CASE** — "94 × 58 × 20 mm", an RTV gasket groove, a
Ø3 vent, a bonded polycarbonate window, 4 perimeters, a cable gland, and a print
orientation that is **the opposite of the one now required**. `hardware/case.scad`
is the authority.

**The case opens at the BACK.** The previous version was a tub facing the rider
with the lid carrying the window and the hood, and the sealing line ran right
around the display glass — the most crowded, least forgiving line on the part.
Turning it round dissolved five separate failures rather than solving them: the
screw bosses that stood inside the display's footprint, a gasket groove with no
inner wall, an unsealed window, a lid that could not clamp a gasket across an
82 mm span on four corner screws, and **the USB hole in a sealed wall**.

    THE FRONT IS CLOSED FOR GOOD, with the panel bonded behind it.
    THE BACK IS THE LID — a plain plate. No window, no hood, nothing to align.

**USB is reached by taking the back off.** There is no port opening.

### Size and print settings

**64.4 × 96.4 × 39.34 mm.** (`body_w` × `body_l` × overall.)

- **ASA, light coloured. Not PETG and never PLA.** PLA softens near 55 °C, and
  **PETG's HDT is only 65–80 °C, its Tg 75–85 °C** — inside the estimated sealed
  interior of 53–70 °C in Bengaluru sun. ASA gives ~105 °C service, better UV
  stability, and does not yellow. An 18 °C interior difference has been measured
  between otherwise identical dark-grey and light-grey enclosures.
- **0.2 mm layers, 5 perimeters** — four is the usual watertight threshold and a
  sealed case earns the fifth. ★ This said **4** and cited "the lugs carry all
  the load"; there are no lugs.
- **30–40% infill.**
- **ENCLOSURE OR DRAFT SHIELD MANDATORY.** ASA delaminating mid-print on a
  100 mm part in a draught is the likeliest way to lose the one print available.

### ★ ORIENTATION — THE OLD LINE HERE WAS BACKWARDS AND WOULD HAVE COST THE PRINT

The deleted instruction read **"body mount-face down; lid sealing-face down,
hood up"**. There is no mount face on the body any more and no hood on the lid.

| Part | Orientation |
|---|---|
| **body** | **FRONT FACE DOWN.** Puts the sealing rim on top, where it prints accurately with no elephant's foot, and the flange flares outward going up at 45° so it is self-supporting. **5 mm brim** — the first layer is a picture frame and adhesion is not optional. |
| **lid** | **OUTER FACE DOWN.** ★ The warning that stood here about a 4 mm picture frame and a 56 × 88 bridge described the mount plate's keying recess, deleted with the dovetail. Measured on the current part: 6085.8 mm² of solid first layer, no bridge, nothing over 45°. The easiest print of the set. |
| bezel | flat, trivial |
| hood | **MOUTH DOWN.** Two first-layer islands — the vent window cuts the skirt ring through its full height and they only join at z 15. Brim both. Its window ceiling is the only real bridge in the set, 27 mm. |
| mount adapter | **SEATING FACE DOWN.** The square cavity is the first layer, 1248 mm² flat on the bed, no support and no witness marks on the one datum that must be true. |
| mount cap | **OUTER FACE DOWN**, support in the pocket only. |

### Sealing, venting and cable entry

- **★ CLOSED-CELL EPDM FOAM TAPE, NOT AN RTV GROOVE AND NOT AN O-CORD.** 3 mm
  tape closing to 2 mm is 33% compression with a ±0.5 mm usable band. An O-cord
  at 25% squeeze has a ±0.15 mm band — and an ASA part this size **bows
  0.3–0.8 mm as it cools**, so the gasket would be defeated by warp alone before
  it ever met water. Foam also drops the closing force to ~5 N per screw, which
  is what makes self-tapping screws viable. **Buy closed-cell: most cheap foam
  tape is open-cell and wicks like a sponge.**
- **★ ePTFE pressure vent, Ø6 MINIMUM — not Ø3.** The part most DIY builds omit.
  A sealed box in the sun reaches 60 °C+; cold rain contracts the air and pulls
  water past the seal. Ø3 does not equalise fast enough on a 60-second quench.
  Membrane can be cut from an old rain jacket, bonded to a Ø12 recessed land.
- **★ POTTED CABLE ENTRY, NOT A GLAND.** An M8 gland's Ø14 locknut needs 16 mm
  of clear flat wall inside, in a position this case does not have — which is
  why the old design's gland never worked out. Drip loop below, as before.
- **Blind screw bosses**, bottoming in solid ASA, so no fastener ever breaches
  the sealed volume. That is what makes it safe to run the eight lid screws
  straight through the foam band.
- **★ NO SEPARATE WINDOW.** The front is closed and the panel is bonded behind
  it; `bezel()` cuts the aperture. This is also the optically correct answer: a
  window with an air gap in front of the panel adds two more air/plastic
  interfaces at ~4% reflection each, and air-gap stacks lose **8–20%** of light
  against **under 5%** for optically bonded ones. On a 250-nit panel already
  losing to glare, that gap was unaffordable.

### The display is the real thermal limit, not the case and not the battery

2.8" ILI9341 modules are rated **operating −20 to +70 °C**, and solar radiation
raises display surface temperature **40–50 °C above ambient**. A documented case
had a 50 °C-rated panel reach **90 °C in sun and black out completely**, with
repeated exposure leaving permanent "solar clearing" spots. **A quick-release
mount so the unit comes off when parked is a legitimate engineering answer** —
it is effectively what Beeline ships, and the quarter-turn bayonet provides it —
one twist and the case is in a pocket.

### Hood and mounting angle

- **Sunshade hood, 30 mm deep, matte black, 5 ribs inside.** Not cosmetic. Per
  the sunlight arithmetic above this is the largest single readability gain
  available, worth more than any backlight change. Bolt-on, two **M3 × 5** into
  blind pilots in pads on the body's sides — ★ ×5, not ×6: the pilot is 4.0 mm
  over a 2.0 mm floor and a ×6 bottoms out before the hood is tight.
- **MOUNTING ANGLE IS THE SECOND-LARGEST GAIN, AND IT IS FREE.** Rider test,
  29 Aug 2026, in real daylight: *"keep it straight up, I'm not able to see
  clearly, but if I adjust the angle I'm able to see it properly."*

  That is the reflection term of the ACR equation, not a preference. A screen
  lying face-up reflects a 100,000 lux sky straight back at the rider, which is
  exactly where the 1430 nits of grey haze above comes from. Tilt it toward the
  rider and it reflects the tank, the road and his own jacket instead — all of
  them orders of magnitude darker. The emitted 250 nits never changes; the
  denominator collapses.

  Two consequences for the build:
    - The ball joint is not a convenience. It is the adjustment that makes this
      panel usable in sun, and any mount that gives it up is the wrong mount.
      The bayonet sets only which way is up — never the angle.
    - **`hood_rake = 12` is provisional.** Once the rider settles on an angle it
      wants setting to match, or the hood shades the wrong part of the sky.

Drawings in `hardware/mount-design.html`.

### ★ Partition scheme: Minimal SPIFFS, not Default

Adding WiFi and ArduinoOTA took the sketch from 51% to **97%** of the default
partition. OTA needs **two** app partitions — the incoming image is written to
the inactive one while the current one runs — so 97% does not mean "nearly
full", it means OTA would succeed once and then have nowhere to go.

In the Arduino IDE: **Tools → Partition Scheme → "Minimal SPIFFS (Large APPS
with OTA)"**. On the command line, `--fqbn esp32:esp32:lolin32:PartitionScheme=min_spiffs`.

That moves it to **65% of 1.97 MB**, which leaves room to keep building.

**The setting must match when you flash over USB.** Upload with the default
scheme and the image lands in a layout the OTA partitions do not agree with;
the device runs, and the first OTA attempt fails in a way that looks like a
network fault. Set it once in the IDE and it sticks per board.

This is exactly the kind of thing BUILD_PLAN Stage 10 exists to find before the
case is sealed. Discovered on the bench, it is a menu item; discovered after
gluing, it is a cracked enclosure.

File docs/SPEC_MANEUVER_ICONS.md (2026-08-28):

# Maneuver icon system

Status: SPEC, 28 Aug 2026. Replaces the hand-estimated coordinates currently in
`firmware/navigator/glyph_data.h`.

## Why this exists

The glyphs on the panel were judged by eye at mount distance and written as
percentages one at a time. Two of them — `G_CONTINUE` and `G_TURN` — happen to
be right. The rest are not wrong so much as *unrelated to each other*: **nine**
different stroke widths appear across fourteen glyphs (6, 8, 9, 10, 11, 12, 14,
15, 16), arrowhead base widths range from **24 to 52** units, `G_SLIGHT`'s head
is very nearly equilateral where `G_CONTINUE`'s is a 75° wedge, and every
diagonal stroke in the set is **29% thinner than the number in the table says**
because of an interpreter detail nobody accounted for (see "The OP_LINE trap"
below).

That reads exactly as reported: drawn by hand, not drawn to a system.

This document derives one construction grid from three published maneuver icon
sets and the panel arithmetic already in `HARDWARE.md`, then emits every glyph
from it. The point is not that the numbers are prettier. The point is that they
are **shared**, so a rider who has learned one arrow has learned all of them,
and so the next maneuver added is a lookup rather than a judgement call.

## Sources

Everything below marked **verified** was read as source: SVG path data, Android
vector `pathData`, or the drawing code itself. Nothing is measured off a
screenshot.

| Source | What was read | State |
|---|---|---|
| **Google Material Symbols** (`maps` set) | `straight`, `turn_right`, `turn_slight_right`, `turn_sharp_right`, `u_turn_right`, `fork_right`, `merge`, `ramp_right`, `roundabout_right` — outlined, 24 px, `viewBox="0 -960 960 960"` | verified |
| **Google Material Icons** (legacy `maps`) | same nine, 24×24 grid | verified |
| **Mapbox Navigation SDK for Android** | `tripdata/.../mapbox_ic_turn_{right,sharp_right,slight_right,straight,uturn}.xml`, 32×32 viewport, PaintCode-generated | verified |
| **OsmAnd** | `TurnPathHelper.java` — the arrow is *constructed in code* on a 72×72 grid, so the constants are literal | verified |
| **OsmAnd** | `RouteResultPreparation.java` — the angle thresholds that classify a turn | verified |
| `HARDWARE.md` | ACR arithmetic, 1.17:1 in Bengaluru noon sun | this repo |
| `FEATURES.md` | 1 px ≈ 0.87 arc-min at 700 mm; ISO 15008 feature-size table | this repo |

URLs:

- <https://raw.githubusercontent.com/google/material-design-icons/master/symbols/web/turn_right/materialsymbolsoutlined/turn_right_24px.svg> (and siblings)
- <https://raw.githubusercontent.com/google/material-design-icons/master/src/maps/turn_right/materialicons/24px.svg> (and siblings)
- <https://raw.githubusercontent.com/mapbox/mapbox-navigation-android/main/tripdata/src/main/res/drawable/mapbox_ic_turn_right.xml> (and siblings)
- <https://raw.githubusercontent.com/osmandapp/OsmAnd/master/OsmAnd/src/net/osmand/plus/views/TurnPathHelper.java>
- <https://raw.githubusercontent.com/osmandapp/OsmAnd/master/OsmAnd-java/src/main/java/net/osmand/router/RouteResultPreparation.java>

Three things were looked for and **not found**, recorded so they are not
re-searched:

- **Mapbox `maki`** carries no maneuver arrows at all. It is a POI set.
- **Mapbox Navigation for iOS** keeps its arrows in
  `Sources/MapboxNavigationUIKit/PaintCode/ManeuversStyleKit.swift` — file
  confirmed present, contents not read. The Android drawables are PaintCode
  output from what is very likely the same source document, so this is
  **inferred**, not verified, and nothing in this spec rests on it.
- **A citable numeric arrowhead ratio in MUTCD / Standard Highway Signs.** The
  arrow details exist as dimensioned drawings, not as a published ratio, and
  they are lane-control arrows on signs read at 60 km/h — a different problem
  from a 22 mm glyph at 700 mm. Not used.

## What the three reference systems actually do

Measured from the source above, normalised to percent of the icon box.

| | shaft width | head width | head : shaft | head length ÷ head width | apex angle |
|---|---|---|---|---|---|
| Material Symbols | 8.3% | 33.3% | **4.00** | 0.50 | 90° (open chevron) |
| OsmAnd, large arrow | 11.1% | 45.8% | **4.13** | 0.51 | ~89° |
| Mapbox Navigation | 12.5% | 55.4% | **4.43** | 0.69 | **72°** |
| Mapbox, slight-turn head | 12.5% | 49.1% | 3.93 | 0.65 | **75.2°** |
| **this spec** | **16%** | **52%** | **3.25** | **0.65** | **74.8°** |
| existing `G_CONTINUE` (panel-validated) | 16% | 52% | 3.25 | 0.65 | 74.8° |

Working, so the numbers can be checked:

- **Material Symbols** `straight` is `M440-120v-567l-64 63-56-56 160-160 160
  160-56 56-64-63v567h-80`. Shaft x 440→520 = **80** of 960. Chevron tip
  (480,-840), arms to (320,-680) and (640,-680): width **320**, length **160**.
  The chevron's own stroke measures 80 — the same as the shaft — confirming one
  stroke weight throughout.
- **OsmAnd** `TurnPathHelper.TurnVariables`, verbatim: `radInnerCircle = 10`,
  `radOuterCircle = radInnerCircle + 8` → shaft **8** of 72. `widthArrow = 22`
  multiplied by `scaleTriangle` = 1.5 for the large arrow → **33** of 72.
  `radArrowTriangle1 = radOuterCircle + 7` = 25, `radEndOfArrow = 44` → head
  length **~17** measured from the widest point.
- **Mapbox** `mapbox_ic_turn_straight`: shaft x −2→+2 = **4** of 32. Head tip
  (0,−15.02), barbs (±8.86,−2.82): width **17.72**, length **12.2**.
  17.72 / 4 = 4.43; apex = 2·atan(8.86/12.2) = **72°**.
- **Mapbox** `mapbox_ic_turn_slight_right` head: apex (9.88,−12.76), base
  (−2.97,−12.04)→(7.31,−0.15). Base **15.7**, apex-to-base-midpoint **10.19**,
  apex angle = 2·atan(7.85/10.19) = **75.2°**.

Two conclusions worth stating plainly:

1. **Head width is ~4× shaft width in every system that publishes one.** The
   2:1–2.5:1 figure from drafting practice (ISO 129 dimension arrows) is a
   different animal: those are read at arm's length on paper, where a fine point
   is an asset. At glance distance a 2:1 head does not register as a head.
2. **Apex angle is 72–90°.** Material's 90° works because the head is an *open
   chevron* whose two arms are strokes; a filled 90° triangle reads as a blunt
   wedge. Mapbox, which fills its heads, uses 72–75°. This spec fills its heads,
   so it takes Mapbox's number.

## ★ The system — every number, in one table

All values are percent of the glyph box, 0–100, x right, y down. Every glyph
below obeys these; where one cannot, the glyph's own section says so and why.

| Symbol | Name | Value | At 84 px | At 96 px | At 104 px |
|---|---|---|---|---|---|
| `W` | **shaft width** — your path | **16** | 13.4 px | 15.4 px | 16.6 px |
| `Wt` | **thin width** — a road that is not your path | **10** | 8.4 px | 9.6 px | 10.4 px |
| `Hw` | **head width** (base of the triangle) | **52** | 43.7 px | 49.9 px | 54.1 px |
| `Hl` | **head length** (base to tip) | **34** | 28.6 px | 32.6 px | 35.4 px |
| `V` | **head/shaft overlap**, measured along the axis | **6** | 5.0 px | 5.8 px | 6.2 px |
| `M` | **margin** — no ink outside `[M, 100−M]` | **4** | 3.4 px | 3.8 px | 4.2 px |
| `D` | **OP_LINE width for a 45° stroke** = `W·√2` | **23** | — | — | — |
| `Dt` | **OP_LINE width for a 45° thin stroke** = `Wt·√2` | **14** | — | — | — |
| — | turn angles: slight / normal / sharp / U | **45 / 90 / 135 / 180** | | | |
| `Xe` | entry centreline, by turn angle 0/45/90/135/180 | **50 / 40 / 34 / 24 / 22** | | | |
| — | optical centre — **ink centroid**, not bounding box | **(50, 50) ± 8 in x, ± 6 in y** | | | |

Derived ratios, for the record: `Hw / W` = **3.25**, `Hl / Hw` = **0.654**,
apex angle **74.8°**, `W / Wt` = **1.6**.

`Xe` is graduated: the sharper the turn, the further left the entry leg starts,
because the exit needs the room. The progression is copied from Material
Symbols, whose stems sit at 50% (straight), 41.7% (slight), 33.3% (right),
29.2% (sharp) and 29.2% (U-turn) of its 960 grid. Ours runs further left at the
sharp end — 24 and 22 rather than 29 — because our reversal arcs are larger:
Material's glyph sits inside a 20-of-24 live area, ours fills the box, and the
entry leg of a hairpin is `arc centre − arc radius` by construction, not a free
choice.

## Stroke weight: why 16 and not 8

This is the one constant that cannot be copied from anywhere, because no
reference system is drawn for a 1.17:1 panel.

**The contrast.** `HARDWARE.md` computes ACR ≈ (250 + 1430) / 1430 = **1.17:1**
in 100 klx Bengaluru noon sun on a 4.5%-reflectance ILI9341. As Michelson
contrast that is (1680 − 1430) / (1680 + 1430) = **8.0%**.

**The angular scale.** `FEATURES.md` establishes 1 px ≈ **0.87 arc-min** at
700 mm on this panel (0.1778 mm pitch ÷ 700 mm). So 1 px = 0.0145°.

**The frequency argument.** A stroke of width *s* pixels against background of
its own width is a square-wave grating of period 2*s* px, i.e.

```
f = 1 / (2 · s · 0.0145)  cycles/degree  =  34.5 / s
```

Human contrast sensitivity peaks near 3–5 c/deg photopic and falls off steeply
on both sides; at 8% Michelson (sensitivity 12.5) the usable band collapses
toward the peak and toward *lower* frequencies, because veiling glare raises the
adaptation luminance and adds spatial noise. Taking 3 c/deg as the target:

| f (c/deg) | s (px) | as % of an 84 px box |
|---|---|---|
| 5 | 6.9 | 8.2% |
| **3** | **11.5** | **13.7%** |
| 2 | 17.3 | 20.5% |

**The ISO cross-check.** ISO 15008 gives a stroke-width-to-character-height
ratio of 1:6 to 1:12. Applied to the glyph's ink height (≈88% of the box = 74 px
at 84): 1:6 → 12.3 px = **14.7%**; 1:12 → 6.2 px = 7.3%. Contrast is short of
the 5:1 ISO 15008 wants by a factor of four, so take the **heavy end**: ~15%.

**The arc-minute cross-check.** `FEATURES.md` already tabulates ISO 15008's
feature sizes: 20 arc-min recommended, 16 acceptable, 12 minimum → 23 / 18 /
14 px. At `W` = 16 the shaft is 13.4 px = **11.7 arc-min at the 84 px box** —
sitting on the ISO minimum. At `W` = 12 it would be 10.1 px = 8.8 arc-min,
below it. At Material's 8.3% it would be 7.0 px = 6.1 arc-min, half the minimum.

**Conclusion: `W` = 16.** Three independent routes — the CSF band, the ISO
stroke ratio, the ISO feature size — land between 13.7% and 16%, and the box is
smallest and the light worst at 84 px, so the number is taken at the top of that
range. It is also, not coincidentally, exactly what `G_CONTINUE` already uses;
that glyph was judged on hardware and it was judged right.

**`Wt` = 10** is the only other weight in the system. At 8.4 px / 7.3 arc-min it
is deliberately below the ISO minimum, and is therefore used **only** where the
element is context the rider does not have to resolve — the branch not taken,
the highway being left, the lane joining, the water under the ferry. Nothing
that carries an instruction is ever drawn at `Wt`. The 1.6:1 ratio against `W`
is a 5 px difference at the 84 px box, comfortably above the ~1.2:1 needed for
reliable size discrimination, and it is always reinforced by a second cue —
the heavy stroke is the one with the arrowhead.

Two weights, not three. `FEATURES.md` already records why: *"solid fill vs thin
outline is the strongest channel; size is a good second; never dashed-vs-solid
or dithered grey."*

## Arrowhead geometry

Every head in this set is the same triangle: **base `Hw` = 52, height `Hl` = 34,
apex 74.8°**, tip first, and the shaft always ends `V` = 6 *inside* it.

Why 52 and 34 specifically:

- **52 sits in the reference range measured in absolute terms** — OsmAnd 45.8%,
  Mapbox 49.1–55.4%, Material 33.3%. Material is the outlier because a Material
  icon occupies a 20-of-24 live area; scaled to a full box its head is ~40%.
- **The ratio `Hw/W` = 3.25 is below every reference's ~4:1 solely because our
  shaft is heavier.** The head is not smaller; the shaft is fatter, for the
  measured contrast reason above. Holding 4:1 would demand a 64-wide head, which
  at the 90° turn would leave 36 of vertical box for the entire entry leg.
- **34 gives a 74.8° apex, which is Mapbox's 72–75.2° to within half a degree.**
  A filled triangle needs to be sharper than Material's 90° chevron to read as
  an arrow rather than a wedge, and blunter than a drafting arrowhead, whose
  ~19° point is the first thing glare erases.

The canonical head for each direction used in this set, as `OP_TRI` operands.
`(cx, ty)` is the tip.

| Direction | `OP_TRI` |
|---|---|
| up | `cx, ty, cx−26, ty+34, cx+26, ty+34` |
| right | `tx, cy, tx−34, cy−26, tx−34, cy+26` |
| down | `cx, ty, cx−26, ty−34, cx+26, ty−34` |
| up-right 45° | `tx, ty, tx−42, ty+6, tx−6, ty+42` |
| down-right 45° | `tx, ty, tx−42, ty−6, tx−6, ty−42` |

The 45° forms come out of `B = T − 34·û`, `B ± 26·n̂` with û = (1,∓1)/√2 and
n̂ = (1,±1)/√2, then rounded: 34/√2 = 24.04 → 24 and 26/√2 = 18.38 → 18, giving
offsets 24+18 = 42 and 24−18 = 6. Every 45° head therefore has a 42×42 bounding
box, which is what makes the diagonal glyphs place cleanly on integers.

**The two panel-validated heads already in the firmware are this triangle.**
`G_CONTINUE`'s head is `24,40 76,40 50,6` — base 52, length 34, exactly. `G_TURN`'s
is `96,53 62,28 62,79` — base 51, length 34, off by one unit. That is the
strongest evidence available that these constants are right: they were arrived
at here from three published systems, and they reproduce what was independently
judged correct on the panel.

## Turn angles

**Verified from OsmAnd's `TurnPathHelper.calcTurnPath`**, which passes the
drawing angle to `TurnVariables` literally:

| Maneuver | Line | Angle drawn |
|---|---|---|
| `TR` / `TL` | `new TurnVariables(..., b == 1 ? 90 : -90, ...)` | **90°** |
| `TSLR` / `TSLL` | `float angle = shortArrow ? 65 : 45;` | **45°** |
| `TSHR` / `TSHL` | `new TurnVariables(..., b == 1 ? 135 : -135, ...)` | **135°** |
| `TU` / `TRU` | `new TurnVariables(..., 180, ...)` | **180°** |

So 45 / 90 / 135 / 180 is not a convention someone assumes — it is a literal in
the source of a shipping navigation app. Mapbox agrees geometrically:
`mapbox_ic_turn_slight_right`'s diagonal runs (−8.34,3) → (0.99,−5.09), i.e.
atan(8.09/9.33) = **40.9°**, and its slight head axis is 40.8° — 45° with a
rounded transition eating a few degrees. Material Symbols'
`turn_slight_right` diagonal is (440,−496) → (640,−296): Δx = Δy = 200, exactly
**45°**.

For completeness, the *classification* thresholds OsmAnd uses to pick which
glyph to draw (`RouteResultPreparation.getTurnByAngle`) are 5° / `TURN_DEGREE_MIN`
/ 120° / 150°. Those are the phone's problem, not this display's — the firmware
is told which maneuver it is — but they confirm that "sharp" means ≥120° of
actual deviation, which is why it must be drawn as a genuine reversal.

**Material Symbols' `turn_sharp_right` is wrong and must not be copied.** Its
path is stem-up, jog-right, head-up: `M240-120v-240q0-33 23.5-56.5T320-440h320
v-248l-64 64-56-56 160-160 160 160-56 56-64-64v248q0 33-23.5 56.5T640-360H320
v240h-80`. The arrow ends pointing north — the same heading it started with.
That is a lane shift, not a 135° turn. Mapbox and OsmAnd both draw the reversal.
This spec follows Mapbox and OsmAnd.

## Optical centre

**Rule: the ink centroid — not the bounding box — lands at (50, 50), within ±8
in x and ±6 in y.**

Centroid rather than bbox because that is what "optically centred" means for a
shape with a heavy end: a right-pointing triangle centred by its bounding box
looks like it has slid left, which is the whole reason the play-button glyph is
nudged right in every UI kit ever shipped. OsmAnd does the same thing
mechanically — its `TurnVariables` constructor starts at `cx = wa/2; cy = ha/2`
and then translates by the minimum amount that keeps `radEndOfArrow` inside the
box.

The x tolerance is looser than y on purpose. A right-turn glyph *should* feel
right-of-centre; the direction is the message. Material's own `turn_right`
bounding box spans 29.2%–87.5% (centre 58.3%) and its `turn_slight_right` spans
37.5%–75% (centre 56.25%) of a 960 grid. Every glyph's computed centroid is
given in its section below.

Two anchors are fixed for the whole family, and they matter more than the
centroid:

- **The entry leg's foot is at y = 96**, the bottom margin, in every glyph that
  has one. That stub is "you, now". It is in the same place, at the same width,
  in every arrow, which is what lets a rider read the difference between two
  glyphs rather than each glyph from scratch.
- **The head's tip touches the margin in the direction of travel.**

## ★ The OP_LINE trap — and the reason the diagonals look thin

`OP_LINE` is documented as "stroke width e", and it is not. From
`maneuvers.cpp`:

```cpp
const int w = b.p(o->e);
for (int i = -w / 2; i <= w / 2; i++) tft.drawLine(x0 + i, y0, x1 + i, y1, fg);
```

The copies are offset **along x**. For a stroke at angle θ to the horizontal the
*perpendicular* width is therefore

```
w_perp = e · |sin θ|
```

At 45° that is `e / √2` = **0.707 e**. Every diagonal in the current glyph set
is written with `e = 15` to match the 15-wide rectangles beside it, and every
one of them actually draws **10.6** — a 30% thin stroke sitting next to a full
one. `G_SLIGHT`, `G_FORK`, `G_EXIT`, `G_SHARP` and `G_MERGE` all have it. It is
the single largest contributor to "inconsistent stroke weights", and it is
invisible in review because the number in the table says 15.

`tools/ascii_glyphs.pl` reproduces the same arithmetic (`line($x0+$_, ...) for
(-int($w/2) .. int($w/2))`), so the renderer will not catch it either — it is
faithful, not wrong.

**The fix in this spec:** every 45° stroke is written with `e = D = 23`, because
23 / √2 = 16.26, which is `W`. Thin 45° strokes use `e = Dt = 14` → 9.9 ≈ `Wt`.
**Every diagonal in this document is at exactly 45°**, so the compensation is
exact rather than approximate. Any future glyph at a different angle must
compute `e = W / sin θ` or use the new op below.

## One new op — proposed, and deliberately not required

`OP_STROKE  a,b -> c,d, width e` — a true perpendicular-width stroke.

```
û  = ((c−a), (d−b)) / L          L = hypot(c−a, d−b)
n̂  = (−û.y, û.x)
P0 = (a,b) + (e/2)·n̂    P1 = (a,b) − (e/2)·n̂
P2 = (c,d) + (e/2)·n̂    P3 = (c,d) − (e/2)·n̂
fillTriangle(P0,P1,P2);  fillTriangle(P1,P2,P3);
```

Five operands, so it fits `GlyphOp` unchanged, and it costs two `fillTriangle`
calls instead of a `drawLine` loop — cheaper at every box size in this project.

**It is not needed to ship this spec.** Every diagonal here is 45°, where
`e = W·√2` is exact. The op is specified so that the day someone wants a 30°
merge taper or a five-way roundabout stub, the answer is one op rather than a
trigonometry comment in a table. Adding it also lets the `√2` disappear from the
tables, which is the kind of thing that stays correct.

## The glyphs

Every table below has been rendered through `tools/ascii_glyphs.pl` at the 96 px
box. All fourteen report **"all glyphs stay inside the box"**; no glyph spills a
single pixel. Left variants are the same tables with `mirror = true` and were
rendered mirrored as well — `G_TURN`, `G_SLIGHT`, `G_SHARP`, `G_UTURN`, `G_FORK`
and `G_EXIT` all reflect exactly, because every rectangle's `x + w` and every
triangle's vertices are integers and the interpreter's `rectX` correction
handles the `fillRect` direction.

Centroids quoted per glyph are ink area centroids computed by hand, including
subtraction of the overlaps.

### CONTINUE — `MV_CONTINUE`

Shaft on the box axis, `W` wide, from the bottom margin to `V` inside the head.
Head tip on the top margin. There is no turn, so `Xe` = 50 and the glyph is
symmetric about x = 50.

```c
static const GlyphOp G_CONTINUE[] = {
  { OP_RECT, 42, 32, 16, 64,  0,  0 },   // shaft, foot on the bottom margin
  { OP_TRI,  50,  4, 24, 38, 76, 38 },   // head, tip on the top margin
  { OP_END,   0,  0,  0,  0,  0,  0 },
};
```

Shaft x 42–58 (`W` = 16, centred). Shaft top y = 32 = head base 38 − `V` 6.
Head 52 × 34. Centroid **(50.0, 47.3)**.

This is the existing glyph with the shaft two units taller and the tip two units
higher; the head is byte-identical. It was already right, and the system was
derived partly to explain *why* it was right rather than to replace it.

### TURN — `MV_TURN_RIGHT`, `MV_TURN_LEFT` (mirrored)

Pivot at (`Xe`, `Xe`) = (34, 34), which makes the entry leg and the exit arm the
same length, 96 − 34 = 62. Square corner: at 90° a rectangle pair is exact, and
Material Symbols' own corner radius here is one stroke width, which at 84 px is
13 px of rounding the panel's own pixel grid supplies for free.

```c
static const GlyphOp G_TURN[] = {
  { OP_RECT, 26, 34, 16, 62,  0,  0 },   // entry leg, foot on the bottom margin
  { OP_RECT, 26, 26, 42, 16,  0,  0 },   // exit arm, pivot to inside the head
  { OP_TRI,  96, 34, 62,  8, 62, 60 },   // head, tip on the right margin
  { OP_END,   0,  0,  0,  0,  0,  0 },
};
```

Entry leg x 26–42, y 34–96. Exit arm x 26–68, y 26–42; it ends at 68, `V` = 6
past the head base at 62. Head 52 × 34 centred on y = 34.
Ink bbox x 26–96, y 8–96. Centroid **(50.5, 46.5)**.

Bounding-box centre is x = 61, against Material's `turn_right` at 58.3% — the
glyph leans right, which is the instruction.

### SLIGHT — `MV_SLIGHT_RIGHT`, `MV_SLIGHT_LEFT` (mirrored)

45°, verified as OsmAnd's literal (`float angle = shortArrow ? 65 : 45`),
Material's exact Δx = Δy, and Mapbox's 40.9° with a rounded transition.

```c
static const GlyphOp G_SLIGHT[] = {
  { OP_RECT, 32, 55, 16, 41,  0,  0 },   // entry leg
  { OP_LINE, 43, 55, 70, 28, 23,  0 },   // 45 deg diagonal - e=23, NOT 16
  { OP_TRI,  88, 10, 46, 16, 82, 52 },   // head, 45 deg
  { OP_END,   0,  0,  0,  0,  0,  0 },
};
```

`Xe` = 40, leg x 32–48. Exit axis is x + y = 98; the head tip (88,10) and the
diagonal's two endpoints all satisfy it, which is the arithmetic check on this
glyph. Head base midpoint (64,34); the diagonal ends at (70,28), `V` = 6 further
along the axis, i.e. inside the head.

**The `OP_LINE` butt is at x = 43, not 40.** A 45° stroke of perpendicular width
16 has an x-extent of 22.6, so butting it on the leg's centreline would hang
3.3 units past the leg on both sides. Starting it at `Xe` + 3 puts the stroke's
left edge at 31.5 against the leg's 32 — flush to within half a unit, which is
0.4 px at the 84 px box. Every diagonal in this set uses the same `Xe` + 3
offset (`Xe` + 1 for a thin branch, where the half-extent is 7).

Centroid **(57.2, 46.5)**. Bbox centre x = 60 against Material's
`turn_slight_right` at 56.25%; a slight right that does not lean right is not
telling the rider anything.

### SHARP — `MV_SHARP_RIGHT`, `MV_SHARP_LEFT` (mirrored)

135°, drawn as a genuine reversal: up, round a hairpin, back down at 45°.

```c
static const GlyphOp G_SHARP[] = {
  { OP_RECT, 16, 40, 16, 56,  0,  0 },   // entry leg
  { OP_ARC,  42, 40, 18,  8,  0, 135 },  // the reversal - 135 deg of arc
  { OP_LINE, 55, 28, 72, 45, 23,  0 },   // exit, down-right at 45
  { OP_TRI,  92, 65, 50, 59, 86, 23 },   // head, down-right at 45
  { OP_END,   0,  0,  0,  0,  0,  0 },
};
```

**Why an arc and not two rectangles.** `OP_ARC` plots
(cx − r·cos t, cy − r·sin t); the tangent at t = 0 is straight up and at t = 135°
is down-right at 45°, so a single `0 → 135` sweep *is* the turn. The first draft
of this glyph used a square knee and it rendered as a solid triangular wedge
20 units tall — the inner corner filled in completely and the hairpin stopped
reading as a hairpin. With r = 18 and a dot radius of 8, the inner radius is
10, i.e. 8.4 px of open background at the 84 px box, and the reversal reads.
OsmAnd draws the same reversal with a much smaller radius (`widthStepIn / 2`
= 5.6% of its box) because its arrow does not fill the box; Mapbox uses a large
rounded hook. 18 is between them and is set by the "inner corner must stay
open" constraint above.

Arc start dot centre (24,40), radius 8 → x 16–32, exactly the entry leg. Arc end
(54.7, 27.3); the exit `OP_LINE` butts at (55,28), inside it. Exit axis is
x − y = 27: (55,28), (72,45) and the tip (92,65) all satisfy it.

Head base midpoint (68,41), diagonal ends at (72,45) — `V` = 6 inside.
Ink bbox x 16–96, y 14–96. Centroid **(48.5, 49.4)**.

**Material Symbols' `turn_sharp_right` was rejected**, for the reason given
under "Turn angles": it ends pointing north. Mapbox's is the model — its head
tip sits at (91%, 73%) of its box and points down-right at 47°; ours is at
(92%, 65%) pointing down-right at 45°.

### U-TURN — `MV_UTURN_RIGHT`, `MV_UTURN_LEFT` (mirrored)

180°. A semicircular arc joins two parallel legs; the exit leg carries a
down-pointing head.

```c
static const GlyphOp G_UTURN[] = {
  { OP_RECT, 14, 36, 16, 60,  0,  0 },   // entry leg, foot on the bottom margin
  { OP_ARC,  46, 36, 24,  8,  0, 180 },  // the turn itself
  { OP_RECT, 62, 36, 16, 28,  0,  0 },   // exit leg, stops inside the head
  { OP_TRI,  70, 92, 44, 58, 96, 58 },   // head, pointing down
  { OP_END,   0,  0,  0,  0,  0,  0 },
};
```

Arc centre (46,36), r = 24, dot radius 8 → stroke width 16 = `W`. The arc's
endpoints at t = 0 and t = 180 are (22,36) and (70,36), which are the two leg
centrelines, so the joints are exact by construction rather than by matching two
sets of hand-derived numbers.

**Leg separation is 2r = 48.** Mapbox's `mapbox_ic_uturn` puts its legs 13 apart
on a 32 grid = **40.6%**, arc radius 6.5 = **20.3%**. An earlier draft here used
r = 20 to match that exactly and it failed a different constraint: the head is
52 wide and centred on the exit leg, so its left corner lands at
`2r + Xe − 26`, and at r = 20 that left only **6 units** of background between
the head and the entry leg — 5 px at the 84 px box, which closes up under blur.
At r = 24 the clearance is 14 units / 12 px. The head is wider relative to the
box here than Mapbox's is relative to theirs, so the U has to open wider.

Head tip (70,92), base y = 58, x 44–96. Exit leg y 36–64, ending 6 past the base.
Ink bbox x 14–96, y 4–96. Centroid **(48.1, 49.6)**.

### FORK / KEEP — `MV_FORK_*`, `MV_KEEP_*` (left variants mirrored)

Both branches drawn, so the glyph says "the road divides" rather than "bear
right". The branch not taken is `Wt` and headless. The existing rationale in
`glyph_data.h` stands and is unchanged: weight and the presence of a head carry
the meaning, because at 1.17:1 a grey stroke is not distinguishable from a black
one.

```c
static const GlyphOp G_FORK[] = {
  { OP_RECT, 34, 62, 16, 34,  0,  0 },   // shared stem
  { OP_LINE, 43, 62, 14, 33, 14,  0 },   // branch not taken - thin, headless
  { OP_LINE, 45, 62, 72, 35, 23,  0 },   // branch taken
  { OP_TRI,  92, 15, 50, 21, 86, 57 },   // head, 45 deg - same head as SLIGHT
  { OP_END,   0,  0,  0,  0,  0,  0 },
};
```

Stem centreline 42, x 34–50, y 62–96. Both branches leave the split at 45°, in
opposite directions, so the fork is symmetric in angle and asymmetric only in
weight — which is exactly the information.

Butt offsets again: the taken branch starts at 45 (= 42 + 3) so its left edge
lands on the stem's left edge; the thin branch starts at 43 (= 42 + 1, since
`Dt` = 14 gives a 7-unit half-extent) so its right edge lands on the stem's
right edge at 50.

Taken axis x + y = 107; head tip (92,15) and diagonal end (72,35) satisfy it.
Head base midpoint (68,39), diagonal ends 6 past it.
Not-taken axis y − x = 19, from (43,62) to (14,33).
Ink bbox x 7–92, y 15–96. Centroid **(55.6, 49.3)**.

`FORK` and `KEEP` still share this artwork deliberately. That decision is
unchanged and the reasoning in `glyph_data.h` is still the right reasoning.

### EXIT / RAMP — `MV_EXIT_RIGHT`, `MV_EXIT_LEFT` (mirrored)

The road being left runs the full height at `Wt` and carries no head — it is
scenery. The ramp peels off it at 45° and carries the head.

```c
static const GlyphOp G_EXIT[] = {
  { OP_RECT, 30,  4, 10, 92,  0,  0 },   // the road you are leaving - thin
  { OP_LINE, 41, 73, 70, 44, 23,  0 },   // the ramp - full weight
  { OP_TRI,  90, 24, 48, 30, 84, 66 },   // head, 45 deg
  { OP_END,   0,  0,  0,  0,  0,  0 },
};
```

Road x 30–40, y 4–96, margin to margin. Ramp butt at x = 41 = 30 + 11.3 rounded,
so the ramp's left edge lands on the road's left edge and the ramp appears to
grow out of the road rather than to cross it.

Ramp axis is x + y = 114, and butt (41,73), end (70,44) and tip (90,24) all sum
to it. Head base midpoint (66,48); the ramp ends at (70,44), `V` = 6 past it.

The split is at y = 73, so 23 units of road continue below it. That is the whole
message of the glyph — the road goes on without you — and it is why the ramp
does not start at the top.

Ink bbox x 30–90, y 4–96. Centroid **(55.3, 47.5)**.

### MERGE — `MV_MERGE`

Your road runs straight through with the standard head; a lane joins it from the
lower left at 45°, drawn at `Wt` because you do not ride it.

```c
static const GlyphOp G_MERGE[] = {
  { OP_RECT, 50, 32, 16, 64,  0,  0 },   // your road
  { OP_TRI,  58,  4, 32, 38, 84, 38 },   // head
  { OP_LINE, 12, 96, 56, 52, 14,  0 },   // the lane joining from the left
  { OP_END,   0,  0,  0,  0,  0,  0 },
};
```

Your road is at centreline 58, not 50. That is deliberate: the joining lane is
~620 units of ink entirely on the left, and centring the shaft would put the
glyph's centroid at x = 36. Offsetting the shaft by 8 brings it to **51.7**.

Lane axis x + y = 108, from the bottom margin (12,96) to (56,52), which is
6 units inside your road's left edge at 50. The two diverge below y ≈ 64, which
is the junction; that is a real divergence and not a rasterisation crack — the
lane is genuinely a separate road below the merge point.

Ink bbox x 5–84, y 4–96. Centroid **(51.7, 54.1)**.

Material Symbols draws `merge` symmetrically, as a Y with two equal legs. That
is correct for a road atlas and wrong here: this display is telling one rider
what to do, and "the road you are on continues, something joins it" is a
different instruction from "two roads become one". The asymmetry is the message.

### ROUNDABOUT — `MV_ROUNDABOUT`, and the exit-numbered variants

Two tables, identical but for the exit stub, so that the ring does not jump
between frames when an exit number appears or disappears.

```c
// Ring plus entry. Drawn when an exit NUMBER is known; the digit replaces the
// exit stub, because "take the 3rd exit" with an arrow pointing right is a lie.
static const GlyphOp G_ROUNDABOUT[] = {
  { OP_RING, 32, 40, 26, 12,  0,  0 },
  { OP_RECT, 24, 56, 16, 40,  0,  0 },   // entry, from the bottom margin
  { OP_END,   0,  0,  0,  0,  0,  0 },
};

// Ring plus entry plus the generic exit stub. Used when no number is known.
static const GlyphOp G_ROUNDABOUT_EXIT[] = {
  { OP_RING, 32, 40, 26, 12,  0,  0 },
  { OP_RECT, 24, 56, 16, 40,  0,  0 },
  { OP_RECT, 52, 32, 16, 16,  0,  0 },   // exit stub, ring edge into the head
  { OP_TRI,  96, 40, 62, 14, 62, 66 },
  { OP_END,   0,  0,  0,  0,  0,  0 },
};
```

**Ring thickness is 12, not `W` = 16, and the reason is the hole.** `OP_RING`
draws radii `[r − t, r]`, so at r = 26 a 16-thick ring leaves an inner radius of
10 — a 20% white disc, 17 px at the 84 px box, and shrinking further as the
stroke bleeds. At t = 12 the inner radius is 14, a 28% disc = 23.5 px. The
enclosed white is what makes a ring read as a roundabout rather than as a blob;
it is the one place in this set where the shape, not the stroke, is the feature,
and it gets the thickness that keeps the shape.

**Ring diameter is 52 — the same as `Hw`.** An earlier draft used r = 24 with the
centre at (36,40), giving a 48-diameter ring beside a 52-wide head, and the
arrow visibly dominated the roundabout. Material's `roundabout_right` keeps its
ring larger than its head. Matching ring diameter to head width is the smallest
correction that stops the arrow winning.

Ring centre (32,40), outer 26 → x 6–58, y 14–66. Entry leg x 24–40, y 56–96,
overlapping the ring's lower edge by 10. Exit stub x 52–68 spans from inside the
ring to `V` = 6 inside the head base at 62.

Centroids: `G_ROUNDABOUT_EXIT` **(45.0, 46.8)**. `G_ROUNDABOUT` on its own is
**(32.0, 50.0)** — 18 left, and deliberately so: the digit is drawn where the
exit stub would have been and restores the balance.

**One change is needed in `maneuvers.cpp`.** The digit is currently placed at
`b.px(82), b.py(44)`, which was on the old ring's exit axis. It should be

```cpp
tft.drawString(n, b.px(78), b.py(40), (s >= 88) ? 4 : 2);
```

x = 78 puts the digit on the new exit axis; y = 40 is the new ring centre. At the
84 px box that is pixel 65.5, and a font-4 digit is ~18 px wide, so it spans
57–74 of 84 — clear of the ring's right edge at 48.7 px and clear of the box.

### FLYOVER and UNDERPASS — `MV_FLYOVER`, `MV_UNDERPASS`

The same drawing with the gap moved. Whichever road is broken is the one passing
underneath.

```c
static const GlyphOp G_FLYOVER[] = {
  { OP_RECT,     4, 48, 92, 16,  0,  0 },  // the crossing road
  { OP_RECT_BG, 34, 46, 32, 20,  0,  0 },  // ...broken where we pass over it
  { OP_RECT,    42, 32, 16, 64,  0,  0 },  // our road, continuous
  { OP_TRI,     50,  4, 24, 38, 76, 38 },
  { OP_END,      0,  0,  0,  0,  0,  0 },
};

static const GlyphOp G_UNDERPASS[] = {
  // Both segments run right up to the crossing bar rather than stopping short:
  // the road must vanish AT the bar, not a few percent before it, or the gap
  // reads as two unrelated stubs instead of one road passing beneath.
  { OP_RECT, 42, 32, 16, 16,  0,  0 },   // our road, above the crossing
  { OP_RECT, 42, 64, 16, 32,  0,  0 },   // ...and below it. Broken between
  { OP_TRI,  50,  4, 24, 38, 76, 38 },
  { OP_RECT,  4, 48, 92, 16,  0,  0 },   // the crossing road, continuous
  { OP_END,   0,  0,  0,  0,  0,  0 },
};
```

Our road is `G_CONTINUE` unchanged, which is the point: a flyover is a
continue-straight with depth information attached, and the rider should read the
arrow first and the depth second.

**The crossing bar is `W` = 16, not `Wt`.** This is the one exception to
"a road that is not your path is thin", and it is a legibility calculation, not
a taste one. In `G_UNDERPASS` the break in *our* road is exactly the bar's
thickness — that break is the entire message. At 16 the gap is 13.4 px at the
84 px box = 11.7 arc-min, on ISO 15008's 12 arc-min minimum. At `Wt` = 10 it
would be 8.4 px = 7.3 arc-min, below it, and the underpass would silently become
a continue-straight in sunlight. The crossing road here is a landmark, not an
alternative route, so the thin-stroke rule does not apply to it.

`OP_RECT_BG` in `G_FLYOVER` punches x 34–66, y 46–66 — 8 units of clear
background on each side of our 16-wide road, 6.7 px at 84 px, and 2 units of
vertical overshoot past the bar at each end so the punch cannot leave a hairline
of bar behind at any box size.

Centroids: `G_FLYOVER` **(50.0, 49.3)**. `G_UNDERPASS` **(50.0, 50.8)**.

`NAV_DATA.md`'s note still holds: Maps emits no flyover-specific icon, so these
codes can only arrive from a source with clearer semantics. They are drawn
because the protocol defines them.

### FERRY — `MV_FERRY`

Not an arrow, and that is the point. "Drive straight ahead" is not what a ferry
leg asks of the rider.

```c
static const GlyphOp G_FERRY[] = {
  { OP_TRI,  10, 44, 90, 44, 76, 66 },   // hull, upper half
  { OP_TRI,  10, 44, 76, 66, 24, 66 },   // hull, lower half
  { OP_RECT, 45, 10, 10, 34,  0,  0 },   // mast
  { OP_TRI,  55, 12, 84, 29, 55, 44 },   // sail
  { OP_RECT,  8, 76, 84, 10,  0,  0 },   // water
  { OP_END,   0,  0,  0,  0,  0,  0 },
};
```

The hull is one convex quadrilateral (10,44) (90,44) (76,66) (24,66) split on the
diagonal (10,44)–(76,66); splitting a convex quad on a diagonal tiles it exactly,
with no seam and no double-fill.

Deck 80 wide, keel 52, depth 22. Mast and water are both `Wt` — neither is a
path, and the hull's solid mass is what carries the glyph. Water sits 10 units
below the keel: the earlier draft had a 20-unit gap and the boat looked airborne.

A sailboat rather than a ro-ro silhouette on purpose. A modern ferry outline is a
box with a superstructure, and at 84 px through a visor a box with a
superstructure is a truck. The mast-and-sail triangle is the most
distinguishable "boat" primitive available at this size, and this glyph is never
confusable with anything else in the set because nothing else in the set is a
triangle over a trapezoid.

Ink bbox x 8–90, y 10–86. Centroid **(52.2, 54.6)**. Bottom-heavy, and exempt
from the ±6 rule for the obvious reason: a boat on water is bottom-heavy.

### DESTINATION — `MV_DESTINATION`

```c
static const GlyphOp G_DESTINATION[] = {
  { OP_RECT, 30, 12, 10, 84,  0,  0 },   // pole
  { OP_TRI,  88, 38, 40, 16, 40, 60 },   // pennant
  { OP_END,   0,  0,  0,  0,  0,  0 },
};
```

Pole at `Wt`; it is a flagpole, not a road. Pennant base 44 on the pole's right
edge, length 48 — deliberately *not* the standard head. A pennant is longer than
it is deep (ratio 1.09 here) whereas the maneuver head is deeper than it is long
(0.65); making them the same shape would have the destination flag read as a
right-turn arrow at a glance, which is the single worst confusion available in
this set.

Pole x 30–40, y 12–96. Pennant tip (88,38), base x = 40 from y 16 to 60.
Ink bbox x 30–88, y 12–96. Centroid **(46.7, 45.1)**.

## Compliance table

Every stroke in the set, and whether it is a system constant or a documented
exception. There are exactly two exceptions and both have arithmetic behind them.

| Glyph | strokes used | head | centroid | notes |
|---|---|---|---|---|
| `G_CONTINUE` | 16 | 52 × 34 up | (50.0, 47.3) | |
| `G_TURN` | 16, 16 | 52 × 34 right | (50.5, 46.5) | |
| `G_SLIGHT` | 16, 23→16 | 52 × 34 at 45° | (57.2, 46.5) | |
| `G_SHARP` | 16, arc 2×8=16, 23→16 | 52 × 34 at 45° | (48.5, 49.4) | |
| `G_UTURN` | 16, arc 2×8=16, 16 | 52 × 34 down | (48.1, 49.6) | |
| `G_FORK` | 16, 23→16, 14→10 | 52 × 34 at 45° | (55.6, 49.3) | |
| `G_EXIT` | 10, 23→16 | 52 × 34 at 45° | (55.3, 47.5) | |
| `G_MERGE` | 16, 14→10 | 52 × 34 up | (51.7, 54.1) | shaft offset +8 to balance the lane |
| `G_ROUNDABOUT_EXIT` | ring 12, 16, 16 | 52 × 34 right | (45.0, 46.8) | **ring 12** — see below |
| `G_ROUNDABOUT` | ring 12, 16 | — | (32.0, 50.0) | digit supplies the right-hand mass |
| `G_FLYOVER` | 16, 16 | 52 × 34 up | (50.0, 49.3) | **bar 16** — see below |
| `G_UNDERPASS` | 16, 16 | 52 × 34 up | (50.0, 50.8) | **bar 16** — see below |
| `G_FERRY` | 10, 10 | — | (52.2, 54.6) | pictogram, exempt from the y tolerance |
| `G_DESTINATION` | 10 | pennant 44 × 48 | (46.7, 45.1) | pennant is deliberately not the head |

`23→16` and `14→10` mean an `OP_LINE` operand of 23 or 14, which draws a
perpendicular width of 16 or 10 at 45°. See "The OP_LINE trap".

**Exception 1 — the roundabout ring is 12, not 16.** At r = 26 a 16-thick ring
leaves a 20% white disc; the enclosed white is the feature, so the stroke yields.

**Exception 2 — the flyover/underpass crossing bar is 16, not 10.** The break in
our road equals the bar's thickness, and that break is the instruction. At 10 it
would be 7.3 arc-min at the 84 px box, below the ISO 15008 minimum.

## Verification performed

```
$ perl tools/ascii_glyphs.pl
... 20 glyph renders, including all six mirrored variants ...
all glyphs stay inside the box
```

What was checked, and how:

1. **Nothing leaves the box.** `ascii_glyphs.pl` counts ink outside 0–100 and
   exits non-zero if any exists. It reports zero for all fourteen tables and all
   six mirrored variants. Minimum ink coordinate across the set is 4
   (`G_UTURN` arc top, `G_EXIT` road top, `G_FLYOVER` bar); maximum is 96.
2. **Every arrowhead is attached to its shaft.** Each diagonal glyph has an
   axis equation (x + y = k or x − y = k) that the butt, the shaft end, the head
   base midpoint and the tip all satisfy; those are listed per glyph above.
   The orthogonal glyphs were checked by the shaft end exceeding the head base
   by exactly `V` = 6.
3. **Mirrors are exact.** Rendered mirrored and compared. Every rectangle here
   has integer `x` and `x + w`, so `rectX`'s `100 − x − w` is exact; every
   triangle vertex and arc centre reflects about 50 exactly. No mirrored glyph
   shifts by its own width, which is the failure mode `rectX` exists to prevent.
4. **The two panel-validated heads survive.** `G_CONTINUE`'s head is unchanged
   from the version judged correct on hardware; `G_TURN`'s moves by one unit in
   one vertex.

What was **not** checked, and must be before this is called done:

- **It has not been looked at on the panel.** Everything above is arithmetic and
  a 96 px ASCII raster. `maneuvers.cpp`'s own header says every layout bug this
  project has shipped was arithmetic found by squinting at hardware. Render the
  SVG contact sheet with `tools/render_glyphs.pl`, then put it on the display at
  84, 96 and 104 and look at it from 700 mm.
- **It has not been looked at in sunlight**, which is the whole reason `W` = 16
  rather than 8. The sunlight gate is unresolved for the project generally; this
  spec is drawn to survive it, not to prove it.

## What changes in the firmware

1. Replace the fourteen `GlyphOp` tables in `firmware/navigator/glyph_data.h`
   with the tables above. `GLYPHS[]` is unchanged — same codes, same `mirror`
   flags, same sharing of `G_FORK` between `FORK` and `KEEP`.
2. One line in `maneuvers.cpp`: the roundabout digit moves from
   `b.px(82), b.py(44)` to `b.px(78), b.py(40)`.
3. Nothing else. No new op is required, no interpreter change, no display
   change. `OP_STROKE` above is offered for later and is not part of this spec.

The header comment in `glyph_data.h` should gain one paragraph recording the
`OP_LINE` perpendicular-width rule, because it is the single trap most likely to
be re-introduced by the next person who adds a diagonal:

```
  DIAGONALS. OP_LINE offsets its copies along x, so a stroke at angle t to the
  horizontal has a PERPENDICULAR width of e*|sin t|, not e. Every diagonal in
  this file is at exactly 45 degrees and is therefore written with e = 23 for a
  16-wide stroke and e = 14 for a 10-wide one. Writing e = 16 draws an 11-wide
  stroke, which is what the previous set did, on every diagonal, silently.
```

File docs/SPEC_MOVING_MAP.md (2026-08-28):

# SPEC: the moving map

**Status:** implementation specification, first draft 28 Aug 2026.
**Scope:** how to put a rider arrow and the roads around it on the 320x240
handlebar panel, from open-source map data, updating as he rides.

**Prerequisites, not repeated here.** `ARCH_OWN_NAV_APP.md` §7 settled *whether*
(yes) and *how it should feel* (step, don't animate). `ARCH_ANDROID_AUTO.md`
§2.2 settled *where the geometry comes from* (offline vector tiles on the phone,
clipped to a window, sent as line segments in the rider frame).
`firmware/navigator/geom.h` / `geom.cpp` already implement the device-side
renderer. This document is the byte-level, pixel-level, millisecond-level
build sheet that sits under all three.

**Convention.** Every claim is marked **[verified]** (read the source or the
code), **[computed]** (arithmetic from a verified figure), **[inferred]**
(reasoned, not measured) or **[unknown]** (must be settled before that line of
code is written).

---

## 0. The decisions, in one table

| # | Question | Decision | Where |
|---|---|---|---|
| 1 | Where does the map live on screen? | **Stay in the glyph box.** 96x96 at (6,80) on the approach screen. No full-screen map. | §1 |
| 2 | Tile format on the phone | **MBTiles.** There is no maintained Java/Kotlin PMTiles reader in 2026 — the one that existed is archived — and PMTiles' only real advantage is build-time. | §2.1 |
| 3 | Extract | `planetiler` over the Geofabrik `southern-zone` PBF, `--bounds` to the Bengaluru metro box, z12–z14, **roads-only custom profile**. | §2.2 |
| 4 | MVT decoder | `no.ecc.vectortile:vector-tile-java` + JTS. | §2.3 |
| 5 | Simplification | RDP at **3 m**, after clipping, in the rider-local metric frame. | §2.4 |
| 6 | Classes kept | motorway, trunk, primary, secondary, tertiary and their `_link`s; plus whatever way the rider is snapped to. | §2.5 |
| 7 | Position | `FusedLocationProviderClient`, `PRIORITY_HIGH_ACCURACY`, 1000 ms. | §3.1 |
| 8 | Heading | `Location.getBearing()` — course over ground. Frozen below 2.8 m/s. **Never** the compass. | §3.2 |
| 9 | Wire | `0x09 GEOM` fragmented into ≤182-byte notifications behind a 4-byte fragment header; `0x0A POSE` at 4 Hz; `0x0B TILE`; `0x0C TILEACK` device→phone. | §4 |
| 10 | Motion | **Both, layered.** Windows step at 0.33–1 Hz; the ESP32 dead-reckons between them but repaints only when accumulated motion exceeds **4 px** or heading exceeds **3°**. | §5 |
| 11 | Device cache | 3x3 grid of 256 m cells, **5,868 B**, evicted **geometrically** by distance from the anchor, reconciled by a `u32 tileKey` the device reports in full every time it changes. 3x3 is provably sufficient with 22.8 m to spare. | §6 |
| 12 | Strokes | The hatching is **already fixed on disk** (filled quads + octagon joins). Add `drawWideLine` AA for the ink pass only, into a 16 bpp sprite. | §7 |
| 13 | Stale rule | 6 s hard blank (`GEOM_MAX_AGE_MS`, already shipped); 2.5 s soft — stop dead-reckoning and mark it. | §8 |

---

## 1. The picture

### 1.1 What is already on the panel

All figures **[verified]** from `firmware/navigator/display.cpp`.

```
ROTATION 1 (landscape)   W = 320   H = 240
distance sprite   SPR_X 112, SPR_W 208, SPR_H 80   (opaque, flush to x=320)
ARROW_ZONE        108                              (nothing may cross this)
glyph box  far    (  8,  68)  84x84     screen > 500 m
glyph box  appr   (  6,  80)  96x96     500-100 m
glyph box  big    (  4,  76) 104x104    < 100 m
alert band        y 190, h 50
instruction text  y 4-6, font 4, up to two lines on the far screen
```

Screen selection is `screenFor()` in `nav_types.h`: `> 500 m` far,
`500–100 m` approach, `< 100 m` committed, `< 30 m` now (inverted). **[verified]**

The map already draws into the glyph box: `drawNavGlyph()` calls
`geomDraw(tft, gx, gy, gs, …)` when `geomValid()`, else the maneuver arrow.
**[verified]**

### 1.2 Variant A — map in the glyph box (96x96). **Recommended.**

Scale, with `GEOM_DEPTH_M = 120` filling the box height **[computed from
`geom.cpp`]**:

```
96 px  /  120 m  =  0.80 px/m   ->  1.25 m/px
rider at (cx, cy) = (gx + 48, gy + 96 - 12) = (54, 164)
forward visible   = 84 px / 0.80 = 105 m ahead
behind visible    = 12 px / 0.80 =  15 m
lateral visible   = ±48 px       = ±60 m
```

So the box is a **120 m x 120 m patch of city**, which at Bengaluru arterial
spacing holds one junction and the approach to it, and nothing else. That is
the correct amount: it is the decision the rider is about to make.

At 50 km/h (13.9 m/s) the world moves **11.1 px/s** through this box
**[computed]**. A 3 s window cadence therefore steps it 33 px; a 1 s cadence
steps it 11 px. §5 spends the dead-reckoner on closing that gap.

### 1.3 Variant B — map takes most of the screen

The honest version of B is not "full screen". The distance sprite is opaque and
flush to the right edge, and distance is the single most-read number on the
panel, so B means **the left two-thirds**: a box of roughly 200x180 at (4, 40),
with distance shrunk from font 8 to font 6 and moved into the top-right corner.

```
200 px / 240 m depth = 0.83 px/m   (same scale, 2x the depth)
push cost 200x180 = 36,000 px @ 1,700 px/ms = 21.2 ms   [computed]
```

**Rejected.** Four reasons, in descending order of force.

1. **It doubles the depth, and depth is what makes a junction unreadable.**
   `geom.h` states the reasoning already: *"more depth shrinks the junction to a
   smudge"*. A 240 m box at 50 km/h covers 17 s of riding, which is two
   junctions and the gap between them. The rider does not have a question about
   the second junction.
2. **It costs a foveation, and the whole design is built to avoid that.**
   `FEATURES.md`: *"Full-block luminance inversion … detected peripherally
   **without costing a glance**. Small text is the opposite: it needs foveation,
   which is the resource the whole design is trying to protect."* **[verified]**
   A 96 px map that answers "which of these three exits" is a shape. A 200 px
   map with four junctions in it is a document.
3. **It demotes distance.** Dropping font 8 (75 px tall) to font 6 to make room
   trades the number that is *always* useful for a picture that is useful for
   about eight seconds per junction. Wrong trade.
4. **It costs nothing to defer.** `geomDraw` already takes `(x, y, s)`.
   Variant B is one call-site change and a layout constant. If a season of
   riding says the small box is too small, B is an afternoon — so there is no
   reason to buy it now on speculation.

**One concession to B, and only one.** On the **far** screen (> 500 m), where
there is no junction to draw and the box is showing the surrounding street grid
as orientation rather than as a decision, widen it to the full arrow zone:
`(4, 56) 100x100`, `GEOM_DEPTH_M` raised to 200 for that screen only. That is
where a wider view is actually informative and where nothing is being decided.
**[inferred — worth trying, not load-bearing]**

### 1.4 What stays around the map

Unchanged from the current nav screen. The map replaces the arrow glyph and
**nothing else**:

| Element | Position | Fate |
|---|---|---|
| Instruction / road name | y 4–6, font 4, ≤2 lines | **stays** — the map cannot say "onto Old Airport Road" |
| Distance to maneuver | sprite (112, 88) 208x80, font 8 | **stays, untouched** |
| ETA / remaining | alert band, y 190 | **stays** (footer, far screen only) |
| GPS-weak marker | top-right, 44 px reserved | **stays** |
| Maneuver arrow | glyph box | **replaced by the map when `geomValid()`, else drawn** |

**Below 100 m the map is not drawn at all.** `drawNavGlyph` is not called on the
committed or now screens, and that stays true: *"a drawing has to be read, an
arrow is recognised, and there is time to read a junction at 300 m and none at
60"* **[verified, `display.cpp`]**. The moving map is an *approach* instrument.

### 1.5 The rider marker

`geomDraw` puts it at `(x + s/2, y + s - s/8)` — for the 96 box, 12 px up from
the bottom edge, centred **[verified]**. It is a filled disc of r=7 with a 3 px
background ring, and it does not move or rotate.

**Change one thing: make it a chevron, not a disc.** A disc is rotationally
symmetric and therefore says "you are here" but not "you point this way". On a
heading-up map with a fixed marker the direction is implied by the frame, so
the disc is not *wrong* — but a chevron costs three `fillTriangle` calls and
removes the one moment of interpretation left in the picture. Geometry, for the
96 box:

```
apex        (cx,      cy - 9)
left wing   (cx - 8,  cy + 7)
notch       (cx,      cy + 2)
right wing  (cx + 8,  cy + 7)
```

drawn as two triangles in `fg` over a 2 px `bg` outline drawn the same way at
+2 px scale — the same halo trick the disc already uses, so it separates from
whatever road it stands on. **[inferred]**

---
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

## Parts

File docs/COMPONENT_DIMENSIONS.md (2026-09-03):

# Component dimensions

Research compiled 29 Aug 2026 so the enclosure can be designed without callipers.

**Status key** — every number below carries one:

- **VERIFIED** — read from a datasheet, a dimensioned drawing, or a manufacturer spec page. URL given.
- **INFERRED** — computed or derived from something verified (e.g. active area from the diagonal), or read off a photograph against a known reference. Stated as such.
- **UNKNOWN** — not found. A calliper-free method to obtain it is given instead.

> Silence is not agreement. If a dimension is not listed here, it was not found.
> Do not assume an omitted number is fine — a case is the one part of this
> project that cannot be fixed in software.

---

## ★★ STOP — THE BOARD IN HAND IS PROBABLY NOT THE MSP2806

★ **RESOLVED 29 Aug 2026 — the board was measured, and the doubt below was
justified.** The section immediately after this one carries the rider's own
figures. **They win over every drawing figure in section 1.** This block is kept
because it is what made the measuring happen, not because it is still open.

Almost every display dimension in this document was read off the LCDWIKI
MSP2806 drawing. That was the right source to find, and the numbers in it are
sound. But the vendor's own photograph of the SmartElex board actually
purchased (PCB marking `4484516A_Y7475_241108`) shows **a different PCB**:

| | LCDWIKI MSP2806 | The board in the photograph |
|---|---|---|
| Panel FPC | bonded at the header end | **ZIF connector mid-board, tail folded through a slot cut in the PCB** |
| Card socket | mid-board, straddling 32–61 mm | **far end, near a corner** |
| SD header | centred on the far edge | **at a corner** |

The consequence that mattered was §1.4. The active area's 4.90 mm offset toward
the far end is not a styling choice — on the MSP2806 it is forced, because the
FPC is bonded along the header edge and the glass physically cannot sit there.
Put the FPC on a ZIF connector fed through a slot instead and that constraint
disappears: the panel is free to sit anywhere along the long axis.

★ **And it did sit somewhere else. The lit-screen measurement returned 3.5 mm,
and the board is 82 mm long, not 86.** Both figures are in the next section. The
prediction this block made — that a number carried over from the wrong board
would be wrong — is confirmed on two dimensions at once.

The listing also mixes at least two revisions across its three photos — one with
bare header holes, one with a 14-pin header fitted. It cannot be trusted for
population either. **Trust the board on the desk, not the drawing.**

---

## ★ MEASURED ON THE ACTUAL HARDWARE — 29 Aug 2026

Rider measurements with a steel rule. These **supersede every drawing figure
they contradict**, and the case is now built from them.

| What | Measured | Drawing said | Status |
|---|---|---|---|
| Display PCB length | **82.0 mm** | 86.00 | ★ **4 mm shorter.** Cross-checked independently: the white panel frame is 70 mm, centred, with 6 mm of board at each end — 70 + 6 + 6 = 82 |
| Display PCB width | **50.0 mm** | 50.00 | agrees |
| White panel frame | **70 × 50 mm, centred** | glass 69.20, *not* centred | ★ On this board the frame **is** centred along the length. On the MSP2806 it is not. |
| Frame proud of the PCB edge | **0.35 mm** per side | not documented | Module is 50.7 mm at its widest. Nothing in any datasheet mentions this lip, and a 50.6 mm locating pocket would have jammed on it. |
| Module thickness, glass face → PCB back | **5.0 mm** | 4.40 | Taking the measured, larger value |
| Header pin projection past the PCB back | **10.0 mm** | 8.38 | |
| SD socket above the PCB back face | **3.0 mm** | ≤2.20 (micro-SD board) | Full-size socket, so taller |
| **Folded ribbon loop above the PCB back** | **4.0 mm** | feature does not exist on the MSP2806 | ★ **The tallest thing on the back.** This is the obstruction the audit could not characterise. |
| ESP32 length | **50.0 mm** | 58 (vendor listing) | see below |
| ESP32 width | **25.0 mm** | 25 | agrees |
| JST connector height | **6.0 mm** | ~6 inferred | confirmed |

### The active-area offset — measured at last

Screen lit white, two independent readings:

```
D (header end) = 14 mm, C (far end) = 7 mm  ->  span 61.0, offset 3.5
D (header end) = 15 mm, C (far end) = 8 mm  ->  span 59.0, offset 3.5
```

Both spans exceed the 57.6 mm the panel can physically produce (320 px ×
0.18 mm), by 1.70 and 0.70 mm respectively — and **the excess is equal at both
ends in each case.** That is backlight glow spilling past the pixel edge, which
inflates the span and leaves the difference untouched. So the offset is taken
from the difference, which the glow cannot corrupt:

> **`disp_active_off = 3.5 mm` toward the far end.** Not 0, not the inherited
> 4.90. Two readings of different edges agreeing on 3.5 is the confirmation.

### The handlebar ball — 17 mm, VERIFIED from the manufacturer

**VERIFIED** 29 Aug 2026 from BOBO's own product listings, by two independent
routes:

1. BOBO's **[Metal Buckle Handlebar Attachment][bobobuckle]** (SKU BB-BM-502) is
   sold in a **17 mm** ball version whose stated compatibility list names the
   **BM4** explicitly, alongside the BM1/2/3/5/6/10/11/12/14/20/21/24 series.
2. BOBO's stem mounts split the same way — **SM1 carries a 25 mm ball, SM2
   a 17 mm ball**, and the BM4 pairs with the SM2.

So the ball on the bike is **Ø17.0 mm**, and this is now a sourced figure
rather than the "near-universal motorcycle standard" it was being taken on.

★ **One caveat that keeps it worth a glance.** BOBO sells the same buckle in
**15, 17 and 25 mm**. The 17 is what ships with a BM4, but if the handlebar
attachment was ever bought separately or swapped, it could be another size.
Thirty seconds of confirmation, no callipers:

```
paper strip round the ball's widest point, mark the overlap, flatten, measure:
    47.1 mm  ->  15 mm ball
    53.4 mm  ->  17 mm ball   <- expected
    78.5 mm  ->  25 mm ball
```

Circumference multiplies the error by pi, which is exactly why this beats
trying to measure a sphere's diameter with a rule. A 15 and a 17 are 6.3 mm
apart on the strip — unmissable.

[bobobuckle]: https://www.bobogears.com/product/bobo-metal-buckle-handlebar-attachment/

### ★ The ESP32 is probably a LOLIN32 **Lite**, not a LOLIN32

50 × 25 mm matches the published **LOLIN32 Lite** outline (~50.4 × 25.5) rather
than the full LOLIN32 (~58 × 26) the vendor listing describes. Both carry a JST
battery connector, so that is not a discriminator.

This does not affect the enclosure — the display is the larger part and
`mcu_l` is referenced by no geometry — but **it matters for the perfboard
layout and for the pin map**, because the Lite breaks out fewer pins in a
different order. The working pin map in `User_Setup.h` is bench-proven and
remains the authority; do not "correct" it against a LOLIN32 pinout diagram.

---

## 1. SmartElex 2.8" TFT (ILI9341, SPI, 240×320, non-touch)

### 1.1 Source and SKU

| Item | Value | Status |
|---|---|---|
| Robocraze SKU | **TIFDP0094** | VERIFIED — [robocraze.com product page][rc1] |
| Product name | SmartElex 2.8 Inch TFT LCD Display 240×320 | VERIFIED — [rc1] |
| Vendor manual | `2.8_inch_manual.pdf` | VERIFIED — [linked from rc1][rcpdf] |
| Touch | **NO** — the vendor manual states "Touch Support: NO" | VERIFIED — [rcpdf] |
| Underlying generic module | **LCDWIKI MSP2806** (the no-touch member of the MSP2806/MSP2807 pair) | INFERRED — see below |

**The SmartElex manual publishes no dimensions at all.** It is nine pages of
Adafruit_ILI9341 demo code plus a six-line feature list. Robocraze, the
authoritative source for their own house brand, does not state a single
millimetre anywhere on the product page or in the datasheet they link. That is
the central finding for this part: **the vendor cannot answer the question.**

So the dimensions below come from the generic module the SmartElex is a rebadge
of. The identification rests on three independent matches:

1. **The pin list is identical.** The SmartElex manual lists exactly nine module
   pins — VCC, GND, RESET, DC, CS, SDI(MOSI), SDO(MISO), SCK, LED. The LCDWIKI
   MSP2806/2807 manual lists the same nine as pins 1–9, with the five touch pins
   (T_CLK, T_CS, T_DIN, T_DO, T_IRQ) as pins 10–14 that "you can not connect"
   if the module has no touch function. ([MSP2807 manual][msp2807])
2. **The bad advice matches.** The SmartElex manual's wiring table specifies a
   10 K resistor on every signal line and VCC to 5 V — the exact LCDWIKI-family
   instruction that `HARDWARE.md` already identifies as 5 V-Arduino guidance and
   correctly discards for a 3.3 V ESP32.
3. **The touch/no-touch split matches the SKU pair.** LCDWIKI ships one PCB in
   two populations: MSP2807 with touch, **MSP2806 without**. A non-touch 2.8"
   ILI9341 SPI board with this pin list is the MSP2806 population.

Confidence: high that it is this module family. Not certain that Robocraze's
batch is dimensionally identical to LCDWIKI's — **see §1.4 and §6 for the check
to run before printing.**

[rc1]: https://robocraze.com/products/smartelex-2-8-inch-tft-lcd-display-240x320-color-lcd-screen-for-diy-electronics
[rcpdf]: https://cdn.shopify.com/s/files/1/0559/1970/6265/files/2.8_inch_manual.pdf
[msp2807]: https://www.dragonwake.com/download/LCD/2.8inch_spi/2.8inch_SPI_Module_MSP2807_User_Manual_EN.pdf
[lcdwiki2807]: https://www.lcdwiki.com/2.8inch_SPI_Module_ILI9341_SKU:MSP2807

### 1.2 PCB outline and thickness

| Dimension | Value | Status |
|---|---|---|
| PCB length (long edge) | **82.0 mm** | ★ **MEASURED** — see the MEASURED section above. The drawing's "Module PCB Size 50.0x86.0 (mm)" ([MSP2807 manual p.2][msp2807], [LCD wiki][lcdwiki2807]) describes a **different board**. |
| PCB width (short edge) | **50.0 mm** | VERIFIED twice — drawing, and the rider's rule on this board. The two agree. |
| PCB thickness | **1.6 mm** | INFERRED — not published. 1.6 mm is the default FR-4 thickness for this class of module. Treat as ±0.2 mm. |
| Module thickness, glass to PCB back | **5.0 mm** | MEASURED. The drawing says 4.40; the larger measured figure is the one used. |
| Frame proud of the PCB edge | **0.35 mm** per side | MEASURED. Module is 50.7 mm at its widest. |
| Module weight | ~25 g | VERIFIED — [MSP2807 manual p.3][msp2807] |

★ **THE 86.0 FIGURE IS DEAD. `case.scad` has `disp_pcb_l = 82.0`** (with the
cross-check written out at the parameter: 70 mm white frame, centred, 6 mm of
board each end). It is the number the body and the lid — the expensive prints —
are built from, so every downstream sum in this document uses 82.0. Anything
still quoting 86 is 4 mm out.

Enclosure sizing consequence: the finished case is **64.4 × 96.4 × 39.34 mm**
(`case.scad`, `body_w` / `body_l` / rendered height). `HARDWARE.md`'s old
"roughly 94 × 58 × 20 mm" described the abandoned front-opening case and is
gone.

### 1.3 Active display area

| Dimension | Value | Status |
|---|---|---|
| Active area, short axis (240 px) | **43.2 mm** | VERIFIED — "Active Area 43.2x57.6 (mm)", [MSP2807 manual p.2][msp2807] |
| Active area, long axis (320 px) | **57.6 mm** | VERIFIED — same source |

**This is also derivable, and the derivation agrees, which is worth doing
because it is the check that catches a mislabelled panel.**

Pixel pitch on this panel is 0.18 mm exactly:

```
240 px × 0.18 mm = 43.2 mm
320 px × 0.18 mm = 57.6 mm
diagonal = sqrt(43.2² + 57.6²) = sqrt(1866.24 + 3317.76) = sqrt(5184) = 72.0 mm
72.0 mm / 25.4 = 2.835 inches
```

So the true diagonal is **2.835"**, not 2.800". "2.8 inch" is the marketing
round-down, and the panel is very slightly larger than the name implies.

If you had instead taken the name at face value and computed from a literal
2.800" diagonal at 3:4:

```
2.8 in = 71.12 mm ;  3-4-5 triangle → 0.6 × 71.12 = 42.67 mm, 0.8 × 71.12 = 56.90 mm
```

That gives **42.7 × 56.9 mm** — about **0.5 mm and 0.7 mm too small on the two
axes**. Cutting a bezel aperture to those numbers would crop the live edge of
the picture on all four sides. **Use 43.2 × 57.6, the datasheet pair, not the
figure derived from the nominal 2.8 inches.** This is exactly the trap the
"compute it from the diagonal" instinct walks into.

`case.scad` already has `disp_active_w = 43.2`, `disp_active_l = 57.6`.
**Both correct, now datasheet-backed rather than assumed.**

---

### 1.4 Active area position relative to the PCB — ★ SUPERSEDED BY MEASUREMENT

> ★ **The answer is `disp_active_off = 3.5 mm`, measured on the lit panel, and
> that is what `case.scad` has.** Everything below is the MSP2806 drawing's
> chain, which produced 4.90. It is kept for one reason only: it explains *why*
> a 12-o'clock panel has an off-centre aperture at all, which is what stops
> someone "correcting" 3.5 back to zero. **Do not take a number out of it.**

**LCDWIKI publishes a dimensioned mechanical drawing for the exact non-touch
SKU.** It is not linked from any product listing, only from the downloads block
of the MSP2807 wiki page, filed under the *other* SKU's name:

> **[MSP2806_Size.pdf][size2806]** — "LCM OUTLINE, SKU MSP2806, V1.0, 2024-04-11"

[size2806]: https://www.lcdwiki.com/res/MSP2807/MSP2806_Size.pdf

Every number below is read from that drawing. **Status: VERIFIED.**

#### Across the 50 mm axis (short edge) — centred

```
3.40  +  43.20 (LCD AA)  +  3.40  =  50.00 (PCB)   ← exact
```

The glass ("50.00 ±0.2 LCD BL") is the **full width of the PCB**, flush with
both long edges, and the active area is **centred, 3.40 mm in from each side**.
Corroborated independently by the panel supplier's own datasheet
([QD-TFT2803 spec v1.1, Fig. 1][qd]), which carries the same 3.40 / 43.20 / 3.40
chain.

#### Along the 86 mm axis (long edge) — ★ NOT centred, off by 4.90 mm

The drawing nests four spans from one datum edge and carries two offset callouts
on the same dimension lines:

| Feature | Span | Offset from the datum edge |
|---|---|---|
| PCB | 86.00 | 0 (datum) |
| Mounting hole centres | 76.08 | 4.96 (inferred, symmetric — not labelled) |
| LCD glass / backlight | 69.20 ±0.2 | **6.40** |
| **Active area** | 57.60 | **9.30** |

The datum is the PCB edge **furthest from the pin header**. Measuring from it:

```
PCB edge (far end)  ──0.00
                       6.40   glass starts
                       9.30   ACTIVE AREA starts   ┐
                                                   │ 57.60
                      66.90   active area ends     ┘
                      75.60   glass ends
                      86.00   PCB edge (header end)
```

Which makes the four bezel offsets, PCB edge to active area:

| From which PCB edge | To the active area |
|---|---|
| Far end (away from header) | **9.30 mm** |
| Header end | **19.10 mm** |
| Each long side | **3.40 mm** |

**So the active area centre sits 4.90 mm off the PCB centre, displaced toward
the far end:**

```
active area centre from far edge = 9.30 + 57.60/2 = 38.10 mm
PCB centre                       = 86.00 / 2      = 43.00 mm
offset                           = 43.00 − 38.10  =  4.90 mm
```

> ### ★ That 4.90 belongs to the MSP2806, not to the board on the desk.
>
> `case.scad` has **`disp_active_off = 3.5`**, measured. The chain above is
> internally consistent and still wrong for this build, which is the whole
> lesson: a verified number from the wrong drawing reads exactly like a
> verified number from the right one.
>
> The stake is unchanged — the aperture is cut to the active area, so an error
> crops live picture at one end and shows bare PCB at the other. What changed
> is that the aperture now lives in `bezel()`, a 5 g part that reprints in
> eight minutes, so this number can no longer scrap the case.

#### Why the offset exists, and why it points that way

The panel is specified **12 o'clock viewing direction**, driver **ILI9341V**
([MSP2806 drawing, notes 2 and 3][size2806]). On a 12 o'clock TN panel the COG
driver and the FPC tail run along the **bottom** edge — the edge facing the pin
header, because the tail has to reach the board. The driver strip is what eats
the border:

```
glass border, far end     = 9.30 − 6.40   = 2.90 mm   (plain bezel)
glass border, header end  = 75.60 − 66.90 = 8.70 mm   (driver + FPC)
                                            ────────
                            total          = 11.60 mm = 69.20 − 57.60 ✓
```

That 2.90-against-8.70 asymmetry is the whole reason the aperture cannot be
centred. It also independently confirms which edge is the datum: **the wide
border must be at the header end**, because that is where the driver is.

#### The residual doubt, and the check that closes it

The chain above is verified for the **LCDWIKI MSP2806**. That the Robocraze
SmartElex is dimensionally identical was **inferred** (§1.1) and has since been
**disproved** — different length, different offset, different FPC route. The
check that settled it is §5.1, and it has been run.

★ The pointer that used to sit here read "run the calliper-free check in §6.1".
**There is no §6.1.** It was §5.1 all along.

[qd]: https://www.lcdwiki.com/res/MSP2807/QD-TFT2803%20specification_v1.1.pdf

### 1.5 Assembled height (worst case)

From the Side view of the [MSP2806 drawing][size2806]. **VERIFIED:**

| Layer | Value |
|---|---|
| LCD glass, without back tape | 2.30 ±0.1 mm |
| LCD back tape | 0.50 mm |
| PCB | 1.60 mm |
| **Bare module, glass face to back copper** | **4.40 ±0.2 mm** ("Total Thickness excluding Header") |
| SMD components on the back | 2.20 mm max |
| Pin header, projection behind the PCB | 8.38 mm |
| Pin header, own height | 11.17 mm |
| **Module + soldered straight header, glass to pin tips** | **12.78 mm** ("Total height (include Header)") |

The arithmetic closes, which is a good sign the drawing is self-consistent:
`1.60 + 0.50 + 2.30 = 4.40` ✓ and `4.40 + 8.38 = 12.78` ✓.

> ### ★ DECIDED 29 Aug 2026 — 14-WAY FEMALE SOCKET. DO NOT SOLDER WIRES TO THE PADS.
>
> This block used to recommend "solder the nine wires straight to the module's
> pads, no header", on a depth argument. **That recommendation is withdrawn and
> must not be followed** — it is irreversible, and it was answering the wrong
> question.
>
> The depth argument was real but it belonged to a case with a ~20 mm budget
> that no longer exists. The case is back-opening and 39.34 mm deep
> (`case.scad`), and it buys something the flat build cannot:
>
> - **The lid is at the back.** Solder wires to the display and the display and
>   the perfboard become one object whose front end is bonded into the case.
>   Every future repair is then nine wires desoldered blind, inside a box,
>   against a bonded panel.
> - **With a socket:** undo eight screws, unplug once, and the whole electronics
>   module lifts out of the back. The display stays put.
> - **It is the only reversible order.** Socket now and the pins can still be
>   clipped later if the depth is ever wanted back. Clip now and they are too
>   short to socket ever again.
>
> The cost is 4.5 mm and it is already in the model: **`hdr_gap = 11.04`** =
> 8.5 mm socket body + 2.54 mm header strip, exact, not rounded. `case.scad`
> asserts that gap clears the display's folded ribbon and the perfboard's
> solder side, with 7.0 mm of air over the ribbon.
>
> ★ Two numbers here are the wrong board's and are not to be re-derived from:
> the header's projection behind the PCB is **10.0 mm measured**, not the
> drawing's 8.38, and the module is **5.0 mm** thick, not 4.40. Engagement into
> the socket is deeper than the drawing predicted, which is a bonus, not a
> problem.

### 1.6 Mounting holes

**VERIFIED** from the [MSP2806 drawing][size2806]:

| Property | Value |
|---|---|
| Count | 4, one near each corner |
| Hole diameter | **Ø3.20 mm** ("4-3.20") — clearance for M3 |
| Keep-out / pad diameter | **Ø4.70 mm** ("4-4.70") |
| Hole centre grid | **44.00 × 76.08 mm** |
| Inset from each long (50 mm) edge | **3.00 mm** — verified, `44.00 + 3.00 + 3.00 = 50.00` ✓ |
| Inset from the **far** (non-header) edge | **3.00 mm** — VERIFIED |
| Inset from the **header** edge | **6.92 mm** — VERIFIED; `3.00 + 76.08 + 6.92 = 86.00` ✓ |

★ **CORRECTED 29 Aug 2026.** This row previously read "4.96 mm from each short
edge — INFERRED as `(86.00 − 76.08) / 2`, assuming symmetry". The drawing does
label it, and **the holes are not symmetric**: they sit 1.96 mm toward the far
end. Confirmed twice over — the explicit `3.00` callout sits in the same nested
dimension chain as the `6.40` glass and `9.30` active-area offsets, and the
extracted hole-circle centres land in the same place.

Standoffs laid out on the old symmetric 4.96/4.96 pattern would miss by 1.96 mm
at **both** ends. Ø3.20 holes on M3 screws give about 0.1 mm of slop, so that
is not a tight fit — it is a scrapped print.

This is the same error, from the same cause, as the original `disp_active_off =
0.0`: assuming symmetry on a board that is asymmetric by design. The glass is
off-centre, the mounting holes are off-centre, and the reason is the same — the
driver chip eats one end.

### ★ DO NOT MOUNT THE DISPLAY ON THESE HOLES. `case.scad` rejects them by name.

This section used to end "the case does not currently use them; it probably
should." **It should not, and the case deliberately does not.** Two reasons,
both from `case.scad`:

- **The grid above is the MSP2806's, and this is not an MSP2806.** A reviewer
  measuring the vendor's own photograph of the board in hand found its mounting
  holes **evenly spaced**, where the drawing's are lopsided. The 76.08 span also
  belongs to an 86 mm board; this one is 82 mm.
- **A rib cannot miss an edge; a post can miss a hole by 2 mm and scrap the
  print.** So the display is located by ribs bearing on the **PCB outline**
  — 50.0 × 82.0, verified twice — and held forward by a foam pad on the lid.
  Screw posts standing in the cavity on unverified hole centres are exactly the
  failure the back-opening redesign was done to remove.

The Ø3.20 / Ø4.70 figures stay recorded because they are what the drawing says.
Nothing in the case may be built from them.

### 1.7 Connectors

**VERIFIED** from the [MSP2806 drawing][size2806] and the [MSP2807 manual][msp2807]:

| Property | Value |
|---|---|
| Header | single row, **14 positions**, 2.54 mm pitch |
| Header pin span | **33.02 mm** (`13 × 2.54`) |
| Position across the width | **centred** — `8.49 + 33.02 + 8.49 = 50.00` ✓ |
| Which edge | the short edge at the **header end** — the same end as the 8.70 mm wide glass border |
| Offset from that PCB edge | **2.00 mm** |
| Projection behind the PCB | **8.38 mm** (pins); header body 11.17 mm |
| SD card slot | on the **back** face, near the header end |
| Back-side component height | 2.20 mm max |

Of the 14 positions, **this project uses 9**: VCC, GND, CS, RESET, DC/RS,
SDI(MOSI), SCK, SDO(MISO), LED. Positions 10–14 are the touch signals (T_CLK,
T_CS, T_DIN, T_DO, T_IRQ), unpopulated on a non-touch board.

Two things to confirm on the actual board, neither needing a calliper:

- **Count the header positions.** If yours has 9 rather than 14 it is a
  different population, and the 8.49 mm centring figure will not hold — the span
  would be `8 × 2.54 = 20.32 mm`. The PCB outline and glass position are
  unaffected either way.
- **`HARDWARE.md` says to tie T_CS to 3.3 V if touch pins are exposed.** On a
  true MSP2806 there is no touch controller to keep off the SPI bus, so the step
  is moot — but only if the pins really are absent. Look before wiring.

**Orientation, stated plainly because it is easy to get backwards: the pin
header and the wide 8.70 mm glass border are at the SAME end of the board.** The
narrow 2.90 mm border is at the far end. The aperture shifts toward the far end.

---

## 2. WEMOS LOLIN32 (ESP32, CH340, LiPo JST)

### 2.1 Identification — ★ this is not actually a WEMOS product

The board was bought from Robocraze at ₹449 as **SKU TIFCC0110**, listed as
"ESP32 CP2102 Wireless Development Board D1 LOLIN32" ([product page][rclolin];
the ₹449 sale price on the page matches the order exactly).

[rclolin]: https://robocraze.com/products/esp32-development-board-lolin

**Three independent signs say this is a third-party board that copies the
LOLIN32 name and Arduino board profile, not the WEMOS original:**

| | Genuine WEMOS LOLIN32 V1.0.0 | The board in hand |
|---|---|---|
| USB connector | Micro-USB ([espboards][espb]) | **USB-C** (`HARDWARE.md` BOM) |
| USB-serial chip | CP2104 ([espboards][espb]) | **CH340**, bench-verified — and the Robocraze listing title says CP2102, a *third* answer |
| GPIO 4 | broken out ([espboards pinout][espb]) | **not broken out** — bench-verified |
| GPIO 16 | not in the published pinout ([espboards][espb]) | **broken out and working as TFT RESET**, verified 22 Aug 2026 |

`HARDWARE.md` already records two of these as hard-won bench findings: "The USB
chip is CH340, not CP2102, despite what some listings say", and "RESET is GPIO
16, not 4. GPIO 4 is not broken out on the LOLIN32." **Those observations are
the authority for this board.** Every published WEMOS LOLIN32 datasheet is,
strictly, describing a different object.

What follows from that for enclosure design: **there is no manufacturer
datasheet for this board, and there cannot be one.** The outline below is from
the vendor's own listing, which is the best available source, and the rest is
inferred from parts whose dimensions *are* published. Treat §2 as materially
less certain than §1, where an exact SKU drawing exists.

[espb]: https://www.espboards.dev/esp32/lolin32/

### 2.2 PCB outline and thickness

| Dimension | Value | Status |
|---|---|---|
| PCB length | **58 mm** | VERIFIED against the vendor of the actual part — Robocraze spec table, "PCB Size 58×25mm" ([TIFCC0110][rclolin]) |
| PCB width | **25 mm**, likely 25.4 | VERIFIED as 25 by Robocraze; [espboards][espb] gives **25.4 mm** for the WEMOS board. The two disagree by 0.4 mm — see below |
| PCB thickness | **1.6 mm** | INFERRED — not published anywhere. Standard FR-4. |
| Weight | 8 g | VERIFIED — [Robocraze spec table][rclolin] |
| Digital I/O | 26 pins | VERIFIED — [Robocraze][rclolin] |

**On the 25 vs 25.4 disagreement:** take **25.4 mm**. 25.4 mm is exactly 1.000
inch and exactly 10 × 2.54 mm header pitch, which is how these boards are laid
out; "25" is a rounded retail figure. `case.scad` already has `mcu_w = 26.0`,
which is generous enough to swallow the difference either way.

**A third source disagrees more seriously and should be discarded.** A widely
mirrored "Wemos ESP32 Lolin32 Board BOOK" PDF gives "Dimensions 50x25mm" and "2
mounting holes, 3 mm diameter" ([megma.ma mirror][book]). That document is
describing the **LOLIN32 Lite**, not the LOLIN32 — its own text says the board
"does not use the WROOM32 module … has the ESP32 chip, the 4MByte flash memory,
and the antenna built directly on the board", and puts the LED on GPIO22. Both
are Lite characteristics. **Do not use its 50 mm figure or its mounting holes.**

[book]: https://megma.ma/wp-content/uploads/2021/08/Wemos-ESP32-Lolin32-Board-BOOK-ENGLISH.pdf

`case.scad` has `mcu_l = 58.0`, `mcu_w = 26.0`. **Both fine** — length now
vendor-confirmed, width carries about 0.6 mm of deliberate slack.

### 2.3 Assembled height (worst case)

Nothing publishes a stack height for this board, so it is built up from parts
that are individually documented.

| Layer | Value | Status |
|---|---|---|
| PCB | 1.6 mm | INFERRED (standard FR-4) |
| ESP32-WROOM-32 module, above the PCB | **3.10 ±0.15 mm** | **VERIFIED** — Espressif datasheet, module is 18.00 ±0.15 × 25.50 × 3.10 ±0.15 mm ([Espressif][wroom]) |
| USB-C receptacle, above the PCB | ~3.2 mm | INFERRED — typical 16-pin SMD USB-C receptacle |
| **JST LiPo connector, above the PCB** | **~6 mm** | INFERRED — typical JST-PH 2.0 vertical header. **Probably the tallest thing on the top face.** |
| Male header pins soldered through, below the PCB | ~2.54 mm of plastic, plus pin | INFERRED |
| Female Dupont socket on top of a header | ~8.5 mm body | INFERRED |

A useful sanity check that the outline is right: the WROOM-32 module is
**25.50 mm** on its long side and **18.00 mm** on its short side. It can only sit
on a 25.4 mm-wide board with its 18.00 mm dimension across the width. That fits,
with about 3.7 mm of board either side — consistent with 25.4 mm and *not*
consistent with a much narrower board.

**Recommended build — LOLIN32 soldered to perfboard on its own header pins, no socket:**
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

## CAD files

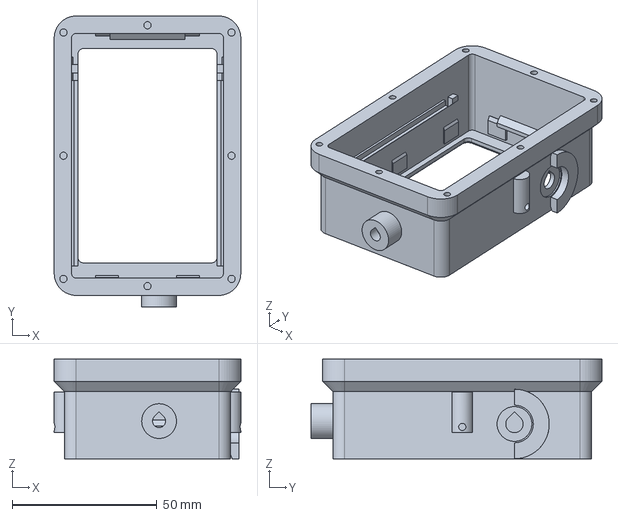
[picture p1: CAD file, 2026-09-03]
hardware/step/body.step
64.4 x 100.4 x 34.3 mm

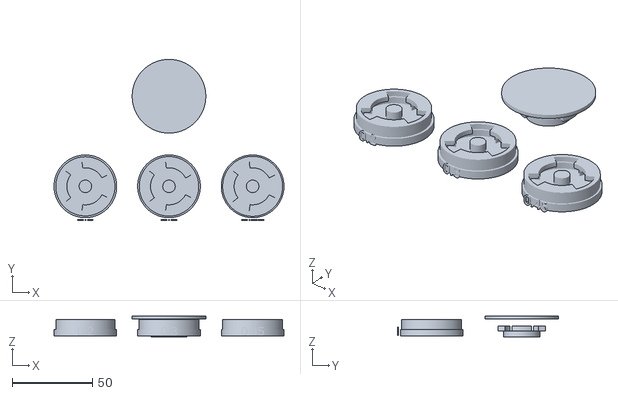
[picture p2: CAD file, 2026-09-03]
hardware/stl/fit_coupon.stl
143.0 x 100.2 x 13.0

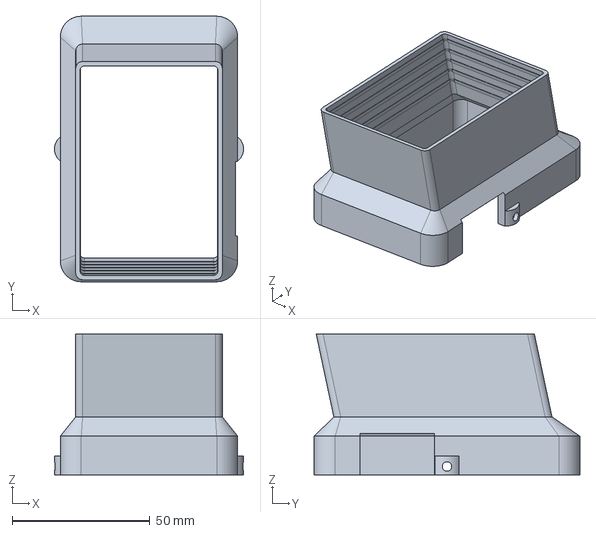
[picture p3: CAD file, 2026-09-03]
hardware/step/hood.step
68.6 x 96.4 x 51.0 mm

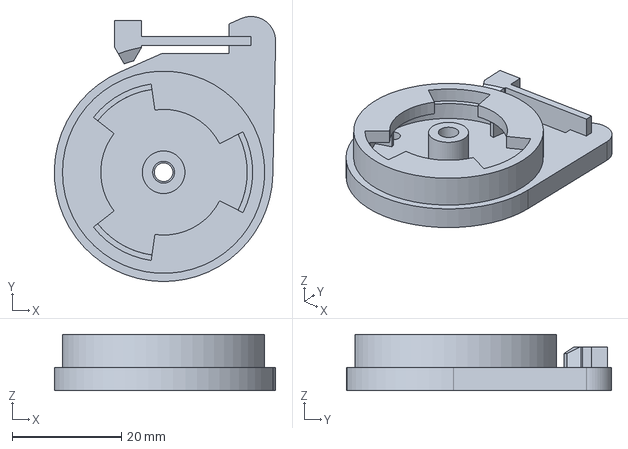
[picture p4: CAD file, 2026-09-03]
hardware/step/mount_adapter.step
40.5 x 48.5 x 10.2 mm

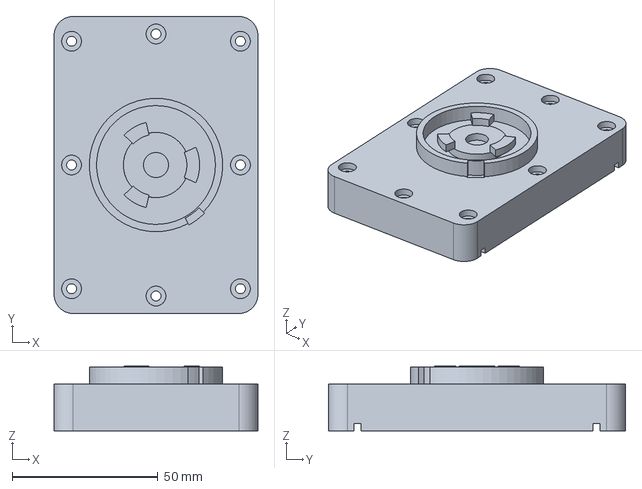
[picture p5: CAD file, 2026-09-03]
hardware/step/mount_cap.step
70.0 x 102.0 x 22.2 mm

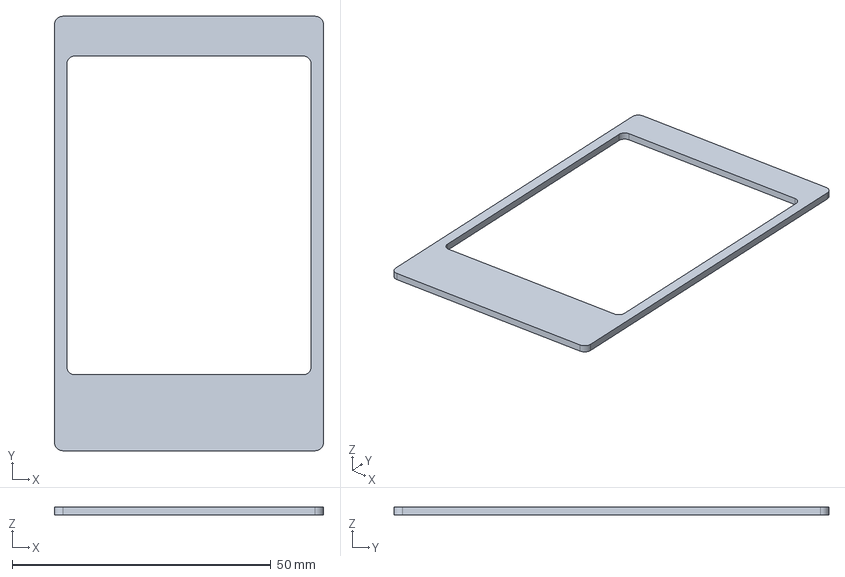
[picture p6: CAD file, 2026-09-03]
hardware/step/bezel.step
52.0 x 84.0 x 1.50 mm

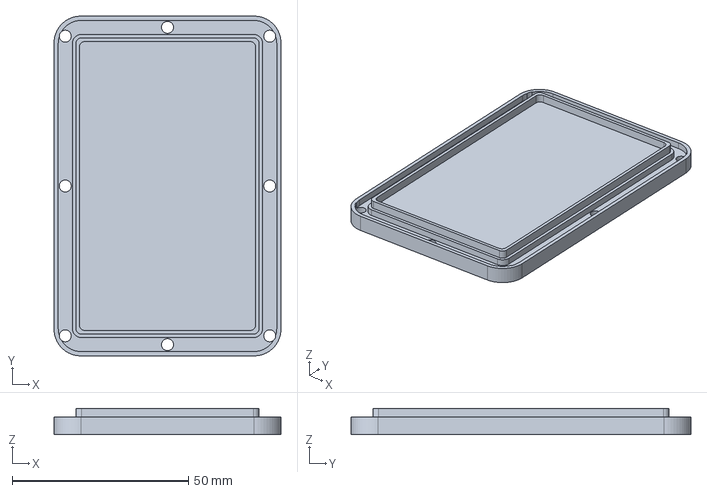
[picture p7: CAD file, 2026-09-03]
hardware/step/lid.step
64.4 x 96.4 x 7.50 mm

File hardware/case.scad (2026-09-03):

/*
  JiffyTrails enclosure - BACK-OPENING. Parametric, printable.

  Open in OpenSCAD (free, openscad.org), press F6, File > Export > STL.

  ---------------------------------------------------------------------------
  ★ WHY THIS OPENS AT THE BACK

  The previous version opened at the front: a tub facing the rider, with the
  lid carrying the window and the hood. Six independent reviews took it apart
  and the failures clustered in one place - the sealing line ran right around
  the display glass, which is the most crowded and least forgiving line on the
  whole case.

    - All four screw bosses stood inside the display's footprint. The module
      could not be lowered into the box at all.
    - The gasket groove had no inner wall: it spanned radius 25.4-27.4 against
      a cavity wall at 26.2, so it opened into the box. A 2.0 mm groove does
      not fit a 2.4 mm rim, and poured sealant would have run onto the boards.
    - Nothing sealed the window. A 1.0 mm gap sat between the glass and the
      lid, and the aperture was an open hole into the electronics.
    - The lid could not clamp a gasket over an 82 mm span with four corner
      screws - computed deflection was larger than the entire squeeze budget.
    - It needed a hole in a sealed wall for USB, or the firmware could never be
      updated by cable again.

  Turning it round dissolves all five rather than solving them:

    THE FRONT IS CLOSED FOR GOOD, with the panel bonded behind it.
    THE BACK IS THE LID - a plain plate, no window, no hood, nothing to align.

  The sealing line moves onto a flat rim with nothing near it. The screws move
  clear of the display. USB is reached by taking the back off. And - the part
  that matters most on a one-shot print - every dimension we are not sure of
  moves into bezel(), a 5 g part that reprints in eight minutes.

  ---------------------------------------------------------------------------
  ★ THE ONE RULE THAT KEEPS THIS SAFE TO PRINT

  bezel() is the ONLY module allowed to read disp_active_w, disp_active_l or
  disp_active_off. Nothing else may reference them.

  Those three are the numbers sourced from a drawing for a DIFFERENT board -
  an LCDWIKI MSP2806, where the panel's ribbon is bonded along the header edge.
  The board actually purchased is a SmartElex with the ribbon on a mid-board
  ZIF connector fed through a slot, and a reviewer measuring the vendor's own
  photograph found its mounting holes evenly spaced where the MSP2806's are
  lopsided. That was the whole reason to believe the glass sits off-centre.

  So the body and the lid - the expensive prints - are built entirely from
  dimensions that cannot move: the 50.0 x 82.0 PCB outline, verified twice.

  ---------------------------------------------------------------------------
  PRINT SETTINGS

  ASA, light coloured. Not PETG and never PLA - docs/HARDWARE.md has the
  arithmetic: PETG's HDT is 65-80 C against an estimated sealed interior of
  53-70 C in Bengaluru sun. ASA gives ~105 C service and does not yellow.

  0.2 mm layers, 5 perimeters (four is the usual watertight threshold; a sealed
  case earns the fifth), 30-40% infill, ENCLOSURE OR DRAFT SHIELD MANDATORY -
  ASA delaminating mid-print on a 100 mm part in a draught is the likeliest way
  to lose the one print available.

  ORIENTATION
    body   FRONT FACE DOWN. Puts the sealing rim on top where it prints
           accurately with no elephant's foot, and the flange flares outward
           going up at 45 degrees so it is self-supporting. 5 mm brim - the
           first layer is a picture frame and adhesion is not optional.
    lid    OUTER FACE DOWN. The warning that used to stand here - a 4 mm
           picture frame and a 56 x 88 unsupported bridge - described the mount
           plate's keying recess, and that recess was deleted with the rest of
           the dovetail mount. Measured on the current part: 6085.8 mm2, ONE
           solid shell, no bridge anywhere and no overhang steeper than 45
           degrees. It is now the easiest print of the set.
    bezel  flat, trivial. 0 mm2 of overhang.
    hood   MOUTH DOWN. 856.8 mm2 in TWO islands - the vent window cuts the
           skirt ring through its full height, so the two halves are not joined
           until the print closes over the window at z 15. Brim both.
           That window ceiling is also the only real bridge in the set: 27 mm.
    mount  see mount_v4.scad. The adapter goes SEATING FACE DOWN - since the
           square became a cavity that face is the first layer, 1248 mm2 flat
           on the bed with no support and no witness marks on the one datum
           that has to be true.
*/

/*
  ★ AT THE TOP, AND `include` NOT `use`.

  This sat at line 631 - below most of the file - until 29 Aug 2026, when a new
  assert referencing dt_base and dt_top was added above it and silently
  evaluated them as undef. `include` pastes at its own location, so everything
  before it cannot see these constants, and OpenSCAD reports that as a warning
  and carries on. Same family as the original bug that created this file:
  `use` imports modules but NOT variables, so dt_h read as undef and nothing
  said so.

  Constants come from ONE file and it is read FIRST.
*/
// ============================================================ PARAMETERS

/* [Display - the two the body depends on are VERIFIED] */
disp_pcb_w      = 50.0;    // VERIFIED twice: drawing, and photo of this board
/*
  ★ 82.0, NOT 86.0. Rider-measured 29 Aug 2026, and cross-checked by his own
  independent route: the white panel frame is 70 mm and sits centred with 6 mm
  of board at each end. 70 + 6 + 6 = 82. Two readings agreeing by different
  means is stronger than either alone.

  The MSP2806 drawing says 86. This is the clearest confirmation yet that the
  board in hand is a different product - and it makes the case 4 mm shorter.
*/
disp_pcb_l      = 82.0;
/*
  Rider-measured 5.0 mm (0.5 cm) glass face to PCB back, against the MSP2806
  drawing 4.40. Taking the measured, larger figure: too deep costs a fraction
  of a millimetre of cavity, too shallow presses the lid onto the panel.
*/
disp_t          = 5.0;
/*
  ★ THE PANEL FRAME STANDS PROUD OF THE PCB. Rider-measured, 29 Aug 2026:
  the white plastic carrier around the glass projects about 0.6 mm BEYOND the
  board edge on both long sides, evenly.

  So the widest part of the module is 51.2 mm, not 50.0 - and the display
  locating ribs were built to a 50.6 mm pocket, which would have stopped the
  module 0.6 mm out and been blamed on print tolerance. Nothing in any
  datasheet mentions this; it took someone holding the part.
*/
disp_frame_proud = 0.35;   // measured; was assumed 0.6
disp_widest      = disp_pcb_w + 2 * disp_frame_proud;

/* [Display - ★ UNVERIFIED. Used ONLY by bezel(), which is 5 g to reprint] */
disp_active_w   = 43.2;    // fixed by 240 px x 0.18 mm - safe
disp_active_l   = 57.6;    // fixed by 320 px x 0.18 mm - safe
/*
  ★★ THE ONE NUMBER TO MEASURE BEFORE PRINTING THE BEZEL.

  How far the lit area sits from centre, toward the far (non-header) end.
  4.90 comes from the MSP2806 drawing and its justification does not survive
  on this board - see the header. Light the screen all white and measure from
  each END edge to where the light starts:

      the two ends roughly equal      ->  0
      header end bigger by about 6    ->  2.90
      header end bigger by about 10   ->  4.90   (what this file assumes)
*/
/*
  ★ 3.5 mm, MEASURED - replacing the 4.90 inherited from the wrong drawing.

  Screen lit white: 14.0 mm of board at the header end, 7.0 at the far end, on
  an 82 mm board. That gives a lit span of 61.0 where the panel can only be
  57.6 (320 px x 0.18), so BOTH readings are 1.70 mm wide.

  A bias that is equal at both ends is what backlight glow does - it spills
  past the pixels by the same amount all round. It inflates the span and leaves
  the difference alone, so the offset is safe to take from the difference:

      (14.0 - 7.0) / 2 = 3.5 mm toward the far end

  Not 0, not 4.90. And it is only used by bezel() - 5 g if this is still wrong.
*/
disp_active_off = 3.5;

/* [The stack, front to back - this is what sets the depth] */
bezel_t         = 1.5;
/*
  ★ Display PCB back face -> perfboard top face. THE decision that sets how
  thick this thing is.

  ★ The header projects 10.0 mm behind the PCB - RIDER-MEASURED. The 8.38 that
  used to be quoted here (2.54 strip + 5.84 pin) is the MSP2806 drawing again.
  It does not change the gap, which is set by the socket and the strip and not
  by the pin - but it means 7.46 mm of free pin goes into an 8.5 mm socket
  rather than 5.84. Engagement is DEEPER than the drawing predicted. Do not
  re-derive anything from 8.38.

    11.0  a 2.54 mm female socket on the perfboard, display plugged in.
          ★ CHOSEN by the rider, 29 Aug 2026 - and NOT for the reason the
          old note here argued.
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

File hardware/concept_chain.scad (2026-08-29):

/*
  concept_chain.scad - NOT A PRINTABLE PART.

  Answers one question: how does the case actually get onto the bike?

  Five things in a row, bottom to top. Two of them you already own and are not
  printing. The clamp's detailed shape is being redesigned, so it is drawn here
  as a simple block - what this file is trying to get right is the ORDER and
  WHAT GRIPS WHAT, not the fillets.

  Render:
    -D 'X=1'   exploded, so you can see the joints
    -D 'X=0'   assembled, as it sits on the bike
*/

$fn = 48;
X   = 1;      // explode factor

BAR   = 22;   // handlebar diameter
BALL  = 17;   // ★ the ball on your bike - BOBO 17 mm
CW    = 44;   // clamp block
CD    = 32;

CASE_W = 64.4;
CASE_L = 96.4;
CASE_H = 34.8;

module rr(w, l, h, r = 4) {
    hull() for (x = [-1, 1], y = [-1, 1])
        translate([x * (w/2 - r), y * (l/2 - r)]) cylinder(h = h, r = r);
}

// ---------- 1. YOURS. The handlebar. ----------
module handlebar() {
    color("#3A4245")
        translate([-90, 0, 0]) rotate([0, 90, 0]) cylinder(h = 180, d = BAR);
}

// ---------- 2. YOURS. The BOBO bar clamp, with the ball on top. ----------
module bar_clamp() {
    color("#1C2124") {
        difference() {
            translate([0, 0, -2]) rr(34, 30, 22, 6);
            translate([-30, 0, 0]) rotate([0, 90, 0]) cylinder(h = 60, d = BAR);
            translate([-1.4, -20, -14]) cube([2.8, 40, 12]);   // pinch split
        }
        translate([0, 0, 20]) cylinder(h = 8, d = 9);          // stem
        translate([0, 0, 28 + BALL/2 - 1]) sphere(d = BALL);   // ★ THE BALL
    }
}

// ---------- 3. OURS, PRINTED. Two halves that close around the ball. ----------
/*
  Drawn as plain blocks on purpose. The real shapes are being redesigned - what
  matters here is that they are SEPARATE, they meet at the ball's equator, and
  two bolts pull them together. Nothing snaps over anything.
*/
module clamp_lower() {
    color("#A2552A") difference() {
        translate([0, 0, -13]) rr(CW, CD, 13, 4);
        translate([0, 0, 0]) sphere(d = BALL - 0.3);
        translate([0, 0, -20]) cylinder(h = 12, d1 = 22, d2 = 11);  // stem relief
        for (x = [-1, 1]) translate([x * 16, 0, -14]) cylinder(h = 16, d = 4.4);
    }
}
module clamp_upper() {
    color("#C4703A") difference() {
        union() {
            rr(CW, CD, 13, 4);
            translate([0, 0, 13]) dovetail_male_block();
        }
        sphere(d = BALL - 0.3);
        for (x = [-1, 1]) translate([x * 16, 0, -1]) cylinder(h = 20, d = 4.4);
    }
}
module dovetail_male_block() {
    translate([0, CD/2, 0]) rotate([90, 0, 0])
        linear_extrude(CD)
            polygon([[-13, 0], [13, 0], [17, 6], [-17, 6]]);
}

// ---------- 4. OURS, PRINTED. Plate bonded to the back of the case. ----------
module mount_plate() {
    color("#B9C2C0") difference() {
        rr(CASE_W, CASE_L, 7, 7.6);
        // the slot the dovetail slides into - open at the TOP so the case
        // drops down on and gravity seats it
        translate([0, 18, -0.5]) rotate([90, 0, 0])
            linear_extrude(80)
                polygon([[-13.3, -0.5], [13.3, -0.5], [17.3, 6.3], [-17.3, 6.3]]);
    }
}

// ---------- 5. OURS, PRINTED. The case itself. ----------
module case_block() {
    color("#8E9A97") rr(CASE_W, CASE_L, CASE_H, 7.6);
    color("#23282B") translate([0, 6, CASE_H]) difference() {
        rr(52, 78, 26, 3);
        translate([0, 0, -1]) rr(47, 73, 28, 2);
    }
}

// ============================================================ STACK

handlebar();
bar_clamp();

zball = 28 + BALL/2 - 1;                   // ball centre height

translate([0, 0, zball - 14 * X])          clamp_lower();
translate([0, 0, zball + 14 * X])          clamp_upper();
translate([0, 0, zball + 19 + 30 * X])     rotate([0, 180, 0]) mount_plate();
translate([0, 0, zball + 26 + 52 * X])     case_block();

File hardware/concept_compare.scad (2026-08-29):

/*
  concept_compare.scad - NOT A PRINTABLE PART.

  A picture, built to answer one question: should the case open at the FRONT
  (where the screen is) or at the BACK (where the mount is)?

  Everything here is deliberately simplified. Real geometry lives in case.scad.
  The only thing this file is trying to get right is WHERE THE RED RING IS,
  because the red ring is the sealing line and its position is the whole
  decision.

  Render:
    openscad -o a.png --imgsize=1400,1100 --camera=... -D 'opt="A"' concept_compare.scad
    opt = "A"  front-opening  (what case.scad does today)
    opt = "B"  back-opening   (what the seal review recommends)
*/

$fn = 32;
opt = "A";
X   = 1;    // explode multiplier; 0 assembles it

// ---- shared sizes, near enough to the real thing ----
W   = 57;   L  = 93;   // case outline, option A
Wb  = 64;   Lb = 100;  // case outline, option B (wider flange for a real seal)
DW  = 50;   DL = 86;   // display module
AW  = 43;   AL = 58;   // active glass

module rr(w, l, h, r = 4) {
    hull() for (x = [-1, 1], y = [-1, 1])
        translate([x * (w/2 - r), y * (l/2 - r)]) cylinder(h = h, r = r);
}

// The display module: green PCB, black glass, a header stub on one edge.
module display() {
    color("#2E5548") rr(DW, DL, 1.6, 2);
    color("#12181A") translate([0, 5, 1.6]) rr(AW, AL, 1.2, 1);
    color("#C08A46") translate([0, -DL/2 + 3, -2.6]) cube([34, 2.6, 2.6], center = true);
}

// The sealing line. This is the point of the whole drawing.
module seal_ring(w, l, r = 4) {
    color("#C4342A")
    difference() {
        rr(w, l, 1.2, r);
        translate([0, 0, -0.5]) rr(w - 8, l - 8, 2.2, max(0.5, r - 4));
    }
}

module hood(w, l, d) {
    color("#23282B")
    difference() {
        rr(w + 6, l + 6, d, 3);
        translate([0, 0, -1]) rr(w, l, d + 2, 2);
    }
}

// ============================================================ OPTION A

/*
  Front-opening. The tub faces the rider; the lid carries the window and the
  hood; the seal ring therefore runs right around the display glass - the
  hardest place on the whole case to seal, and the place where any error shows
  as cropped picture.
*/
module option_A() {
    // hood + lid, lifted off
    translate([0, 0, 34 * X]) {
        color("#B9C2C0") difference() {
            rr(W, L, 2.4);
            translate([0, 5, -1]) rr(AW, AL, 5, 1.5);    // the aperture
        }
        translate([0, 5, 2.4]) hood(AW, AL, 18);
    }
    // THE SEAL - up at the top of the tub, encircling the window
    translate([0, 0, 22 + 20 * X]) seal_ring(W, L);
    // display, dropped in from the front
    translate([0, 0, 16 + 10 * X]) display();
    // the tub
    color("#9AA6AB") difference() {
        rr(W, L, 22);
        translate([0, 0, 2.4]) rr(W - 5, L - 5, 22, 2);
    }
    // mount pad, moulded into the closed back
    color("#6E7B80") translate([0, 0, -6]) rr(W, L, 6);
}

// ============================================================ OPTION B

/*
  Back-opening. The front is a permanently closed bezel with the panel bonded
  behind it; the lid is a plain plate on the mount side. The seal ring moves to
  a flat rim with nothing near it, the screw bosses move out of the display's
  way, and the aperture moves into a separate 5 g frame that can be reprinted
  if the measurement turns out wrong.
*/
module option_B() {
    /*
      Drawn SCREEN-UP, exactly like option A, so the two pictures compare
      directly. The difference you are looking for is which way the parts come
      apart: in A they lift off the front, in B they come off the back.
    */
    // body: closed front wall on TOP, cavity opening downward
    color("#9AA6AB") difference() {
        translate([0, 0, -24]) rr(Wb, Lb, 24);
        translate([0, 0, -24]) rr(Wb - 12, Lb - 12, 21, 2);  // cavity opens down
        translate([0, 5, -4]) rr(48, 74, 6, 2);              // window opening
    }
    // hood on the front, outside the sealed volume, bolted on
    translate([0, 5, 20 * X]) hood(AW, AL, 18);

    // the reprintable bezel frame - every unverified number lives in this part
    translate([0, 0, -5 + 9 * X]) {
        color("#23282B") difference() {
            rr(52, 88, 1.5, 2);
            translate([0, 5, -1]) rr(47, 62, 4, 1.5);
        }
    }
    // display, bonded up behind the frame
    translate([0, 0, -8 - 3 * X]) display();

    // THE SEAL - on a plain flat rim at the BACK, nothing near it
    translate([0, 0, -26 - 14 * X]) seal_ring(Wb, Lb, 7);
    // plain lid, no window, no hood, nothing to line up
    translate([0, 0, -32 - 22 * X]) color("#B9C2C0") rr(Wb, Lb, 5, 7);
    // mount plate, bolted to the outside of the lid
    translate([0, 0, -40 - 30 * X]) color("#6E7B80") rr(Wb, Lb, 6, 7);
}

// ============================================================ LAYOUT

if (opt == "A") option_A();
else            option_B();

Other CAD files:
hardware/concept_options.scad
hardware/case_frontopen_OLD.scad
hardware/dovetail.scad
hardware/mount.scad
hardware/mount_quarterturn_OLD.scad
hardware/mount_v2.scad
hardware/mount_v3.scad
hardware/mount_v4.scad
hardware/stl/bezel.stl
hardware/stl/body.stl
hardware/stl/hood.stl
hardware/stl/lid.stl
hardware/stl/mount_adapter.stl
hardware/stl/mount_cap.stl
hardware/view_assembled.scad

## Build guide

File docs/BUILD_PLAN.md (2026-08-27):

# Motorcycle Navigator — Staged Build Plan

Triumph Speed 400 · Bengaluru · phone stays in pocket

**Principle: every stage has a gate.** Don't buy or build for stage N+1 until
stage N's test passes. Two gates in this plan can change the whole architecture
(Stage 2 and Stage 5). Reaching them cheaply and early is the entire strategy.

---

## Status

| | |
|---|---|
| Spent | ₹1,468 (Robocraze order 356739) + soldering kit and multimeter |
| Done | Stages 1–3, Stage 4 Test A, Stage 5, and Stage 6 built |
| **Next** | **Ride it.** The chain works on the bench; every remaining unknown needs a road |

---

# STAGE 1 — Toolchain and NavDump

**Goal:** working Android build environment, NavDump installed and logging.

**Needs:** nothing new. Windows laptop, phone, data cable.

### Tasks
1. Install Android Studio. Project at `C:\dev\NavDump` — **not** Documents or
   Desktop, those are OneDrive-redirected and Gradle produces baffling
   file-lock errors inside syncing folders.
2. Defender exclusions: `C:\dev`, `~\.gradle`, `~\AppData\Local\Android\Sdk`.
3. Add `...\Android\Sdk\platform-tools` to PATH so `adb` works anywhere.
4. New Project → Empty Views Activity → package `com.jiffytrails.navdump`,
   Kotlin, minSdk 26, Kotlin DSL.
5. Drop in the four files. Run.
6. Grant notification access. Set Battery → **Unrestricted**. On Xiaomi /
   OnePlus / Samsung also add to the OEM autostart list — separate setting.

### Test
Start Maps navigation to anywhere. Switch to NavDump. Entries appear within
1–2 seconds.

**If empty:** toggle notification access off and on (Android is flaky about
rebinding after a reinstall — do this every rebuild). Reboot if that fails.
Confirm Maps is in turn-by-turn, not route preview.

### Gate
Log entries appearing while stationary. → Stage 2

---

# STAGE 2 — The data gate ★

**Goal:** find out whether Google Maps gives us what this project needs.
This is the single most important stage. Everything downstream depends on it.

**Needs:** nothing. A 20+ minute ride.

### Tasks
1. Navigate somewhere 20+ min away with varied turns — include a flyover, a
   service road, and a junction if you can.
2. Lock the phone, pocket it, ride.
3. Deliberately miss one turn to capture rerouting.
4. Pull the log:
   `adb pull /sdcard/Android/data/com.jiffytrails.navdump/files/navdump.log`

### Five questions to answer from the log

| # | Question | Why it matters |
|---|---|---|
| 1 | Does distance update ~1/sec continuously? | If it only ticks every 500 m, "20 m — TAKE RIGHT" is impossible |
| 2 | Is text in `ex android.title/text`, or only in `contentView`? | Determines parser fragility |
| 3 | Does `largeIcon hash` stay stable per maneuver type? | Stable → lookup table. Drifting → coarse classifier |
| 4 | Is a next-maneuver present anywhere? | The "LEFT then RIGHT in 80 m" screen depends on it |
| 5 | What appears during reroute / tunnel / arrival? | These are states the display must handle honestly |

### Gate
- **Q1 yes + Q2 answered + Q3 stable** → continue with Google Maps
- **Q1 no, or Q3 unusable** → pivot to OsmAnd's AIDL API. Same hardware, same
  protocol, different data source. Install OsmAnd, repeat this stage.
- Q4 no → drop the next-maneuver panel from the UI. Not fatal.

---

# STAGE 3 — ESP32 alive

**Goal:** toolchain to board.

**Needs:** ESP32, micro-USB data cable (charge-only cables are the classic
day-one failure).

### Tasks
1. Arduino IDE 2.x from arduino.cc. Board: **WEMOS LOLIN32** (not "ESP32 Dev
   Module" — this board has its own entry).
2. No driver install needed. The USB chip is **CH340**, not CP2102, despite the
   listing; Windows has a built-in driver. Port was COM10, later COM11.
3. Blink. Then a sketch printing chip revision, free heap, MAC address.

### Test
Serial monitor at 115200 shows the chip info. LED blinks. Reflashing works
repeatedly without holding BOOT.

### Gate
Reliable flash + serial. → Stage 4

---

# STAGE 4 — Display, and the sunlight gate ★

**Goal:** TFT rendering, and an answer on daylight readability.

**Needs:** display, breadboard, jumpers. No resistors — the vendor manual
specifies 10K series resistors because it assumes a 5V Arduino. Your ESP32 is
natively 3.3V. Wire straight through.

### Wiring

| Display | ESP32 |
|---|---|
| VCC | 3V3 |
| GND | GND |
| CS | GPIO 15 |
| RESET | GPIO **16** |
| DC | GPIO 2 |
| SDI (MOSI) | GPIO 23 |
| SCK | GPIO 18 |
| SDO (MISO) | GPIO 19 |
| LED | 3V3 |

### Tasks
1. TFT_eSPI library. Edit `User_Setup.h` — **the live one**; see the sketchbook
   section of `HARDWARE.md` first, this is where three sessions were lost.
   Use `ILI9341_2_DRIVER`, the pins above, and `SPI_FREQUENCY 27000000`.
2. Run the library's graphics test.
3. Build a mock nav screen — landscape, black on white, biggest possible
   distance digits, arrow, instruction text.
4. Try both orientations and both polarities (black-on-white vs white-on-black).

### Test A — function ✅ PASSED 22 Aug 2026
`TFT_graphicstest_one_lib` renders graphics and text correctly through all
rotations. No flicker, colours correct. Took `ILI9341_2_DRIVER` at 27 MHz —
full story in `HARDWARE.md`.

### Test B — SUNLIGHT ★ ← YOU ARE HERE
Flash `firmware/sunlight_test/sunlight_test.ino`. It cycles the six real
display states, including the two maximum-legibility cases, and prints the
current screen over serial so photographs can be matched up afterwards.

Take it outside between 12:00 and 14:00. Arm's length — mount height, not
reading distance. Sunglasses on if you ride with them. Try direct sun falling
on the screen, and shaded by your body. Power it from a USB power bank.

**Caveat that affects the result:** LED is wired to `3V`, so the backlight is
running below its rated brightness. If the answer is marginal, drive LED from a
5V source before concluding anything — see HARDWARE.md.

### Gate
- **Readable** → carry on, cost ₹0
- **Marginal** → first retry with LED on 5V. Still marginal → matte anti-glare
  film ₹100 + printed sunshade hood. Note in the project log that the answer was
  marginal; it raises the value of voice guidance later
- **Unreadable in all orientations** → stop. This is the branch that breaks the
  budget. Options: transflective Sharp Memory LCD (₹3,000+, monochrome), or
  accept the device is a shade-and-dusk instrument with voice carrying daylight

---

# STAGE 5 — BLE link and protocol

**Goal:** phone ↔ ESP32, with a protocol designed for everything, not just nav.

**Needs:** nothing new.

### Protocol

ESP32 is the GATT **peripheral**. Phone connects as central and writes packets
at ~1 Hz. Request MTU 185 at connect so strings fit.

```
Service        6e400001-b5a3-f393-e0a9-e50e24dcca9e
Char (write)   6e400002-b5a3-f393-e0a9-e50e24dcca9e   phone → ESP32
Char (notify)  6e400003-b5a3-f393-e0a9-e50e24dcca9e   ESP32 → phone
```

**Every packet:** `[type:u8][len:u8][payload…]`, little-endian.

| Type | Name | Payload |
|---|---|---|
| 0x01 | NAV | `u8 maneuver, u16 dist_m, u8 next_maneuver, u16 next_dist_m, u16 eta_min, u16 remaining_100m, u8 flags, utf8 instruction` |
| 0x02 | STATUS | `u8 flags, u8 phone_battery_pct` |
| 0x03 | CALL | `u8 state (0 idle/1 ringing/2 active), utf8 name` |
| 0x04 | MEDIA | `u8 state (0 stop/1 play/2 pause), utf8 title \0 artist` |
| 0x05 | TRIP | `u32 distance_m, u16 duration_min, u16 speed_kmh_x10, u16 max_speed_kmh_x10` |
| 0x06 | CONFIG | `u8 brightness (0=auto, 1-100 manual), u8 units` |
| 0x07 | TRAFFIC | segment list derived from `progressSegments` |

NAV flags: bit0 nav_active, bit1 rerouting, bit2 gps_weak, bit3 arrived.

`len` is the **payload** length, excluding the two header bytes. This matters:
the NAV instruction has no length prefix and no terminator, so its extent is
`len` minus the 11-byte fixed block.

### Maneuver codes

```
0x00 UNKNOWN          0x0C MERGE
0x01 CONTINUE         0x0D FORK_LEFT
0x02 TURN_LEFT        0x0E FORK_RIGHT
0x03 TURN_RIGHT       0x0F EXIT_LEFT
0x04 SLIGHT_LEFT      0x10 EXIT_RIGHT
0x05 SLIGHT_RIGHT     0x11 ROUNDABOUT
0x06 SHARP_LEFT       0x12 FLYOVER
0x07 SHARP_RIGHT      0x13 UNDERPASS
0x08 KEEP_LEFT        0x14 DESTINATION
0x09 KEEP_RIGHT       0x15 FERRY
0x0A UTURN_LEFT
0x0B UTURN_RIGHT
```

Reserve 0x20–0x2F for roundabout-exit-N if the logs show Maps distinguishes
them.

**Why typed messages now:** a fixed nav-only struct would have to be rewritten
on both sides when caller ID arrives in Stage 9. Two extra bytes and ten lines
buys that away.

### Tasks
1. ESP32: NimBLE-Arduino peripheral, advertise, accept writes, parse by type,
   print to serial.
2. Test client: nRF Connect on the phone. Write hex by hand.
3. Auto-reconnect on both sides. Test by walking out of range and back.

### Test
Send `01 18 03 64 00 02 50 00 0C 00 20 00 01` + "Old Madras Rd" from nRF
Connect. ESP32 serial prints: TURN_RIGHT, 100 m, next TURN_LEFT 80 m, ETA 12,
3.2 km, active, "Old Madras Rd".

As a single paste-ready string:

```
01 18 03 64 00 02 50 00 0C 00 20 00 01 4F 6C 64 20 4D 61 64 72 61 73 20 52 64
```

**Corrected 26 Aug 2026** — this example previously read `01 0F …`, and `0x0F`
is 15, which matches nothing: not the payload (24), the frame (26), the fixed
block (11) or the instruction (13). The payload is 11 fixed bytes plus 13 for
"Old Madras Rd" = 24 = **`0x18`**. Every other field in the example was correct.

The firmware tolerates the old string because it bounds `len` by the actual
write length, but the Android app must send `0x18`.

Walk 30 m away, come back. Reconnects unaided within 10 s.

### Gate
Round-trip works, reconnect is automatic. → Stage 6

---

# STAGE 6 — Android app: parse and transmit

**Goal:** the real companion app.

**Needs:** nothing new. Reuses NavDump's listener.

### Tasks
1. New project, or extend NavDump. Foreground service with a persistent
   notification (Android kills background BLE otherwise).
2. `NavSource` interface with a `GMapsNotificationSource` implementation —
   parse exactly what Stage 2's log showed, not what you hoped for.
3. Maneuver classifier: icon hash → code. Build the table from the log's ASCII
   art. Unknown hash → 0x00, never a wrong guess.
4. BLE central: scan, connect, request MTU, write NAV at 1 Hz.
5. Send NAV with `nav_active=0` when navigation stops. Silence is ambiguous;
   an explicit "not navigating" is not.

### Test
1. Phone in pocket, ESP32 on serial. Navigate a route. Serial shows correct
   maneuvers and a smoothly counting-down distance.
2. Kill Maps mid-route → ESP32 receives nav_active=0 within 2 s.
3. Turn phone Bluetooth off and on → reconnects without touching either device.
4. Screen off for 15 minutes → packets still arriving.

### Gate
20-minute route, correct data throughout, no manual intervention. → Stage 7

### Status — BUILT 27 Aug 2026, gate not yet run

`android/navlink` is a complete Gradle project, installed and working end to
end: Maps → NotificationListenerService → BLE → panel. Verified on a live route
with the road name, arrival time and distance remaining all correct on screen.

The bench proved: MTU 185 negotiated, 80+ packets with zero failures, the clock
arriving, the maneuver arrow correct, night mode inverting, and the far /
approach / committed bands switching.

**Four bugs were found by looking at hardware. Review caught none of them.**

- A parse failure rendering as `0 m` — and rule 2 fires during *ordinary*
  navigation, so it flickered mid-route.
- A zero distance treated as an imminent turn, hiding the one screen with
  something to say.
- A blank band painting white on the inverted screen.
- The main row misaligned by 30 px.

Three of those were layout arithmetic. That is now held by `static_assert`
rather than by attention.

**Still open, and only a road will settle them:**

1. **The gate itself** — 20 minutes, no intervention.
2. **An incoming call produced nothing on the display.** The listener matches on
   `CATEGORY_CALL`; Samsung's dialer may not set it. Needs a call while
   connected, then a `dumpsys notification` capture to see what it really sends.
3. **Screen off for 15 minutes** — untested. The vendor autostart list is the
   likeliest failure, and it has no API to check.
4. **Reconnect** — walk 30 m away and back, no button press at either end.
5. **The Now Bar fields alternate** roughly every second between two layouts, so
   the road name may flicker between sources. Watch while moving; the fix is to
   latch the last non-null value.

---

# STAGE 7 — UI and honesty

**Goal:** a display you can read in one glance that never lies.

**Needs:** nothing new.

### Distance-band states

| Range | Display |
|---|---|
| > 500 m | Instruction, medium distance, ETA, remaining km, next-maneuver strip |
| 500–100 m | Distance large, arrow large, ETA drops off |
| < 100 m | Full-screen arrow + distance. Nothing else |
| < 30 m | Inverted colours |
| Post-maneuver | Immediately switch to next |

### Failure states — these matter more than the happy path

| Condition | Display |
|---|---|
| No packet 10 s | Dim screen, "STALE" |
| BLE disconnected | "PHONE DISCONNECTED" |
| nav_active=0 | Clock + trip stats. **Never a stale maneuver** |
| rerouting | "REROUTING", suppress the arrow |
| gps_weak | Small warning corner |

### Tasks
1. TFT_eSPI sprites for the distance field only — full-screen sprites won't fit
   in plain ESP32 RAM. Partial sprite prevents the flicker of redrawing a large
   number every second.
2. Draw maneuver arrows as vector paths, not bitmaps. Scalable, tiny.
3. Watchdog: `millis() - lastPacket > 10000` → stale. Ten seconds, not five —
   NAV_DATA.md measured 64 s with no field changing while Maps kept posting at
   ~1 Hz, so the threshold has to clear a long quiet stretch. Counts arrivals,
   never value changes.

### Test
- Unplug the phone's Bluetooth mid-navigation. Screen must change within 10 s.
- Photograph the screen at each distance band at arm's length. Anything you
  can't read in under half a second is too small.
- Force every failure state manually and confirm none of them ever leave a
  stale instruction on screen.

### Gate
All five failure states render correctly. Every band readable at a glance.

---

# STAGE 8 — Bangalore road testing

**Goal:** find out what the real world does to it. Still on breadboard, taped
to the bar or held by a passenger — do **not** build the enclosure yet.

### Test matrix

| Scenario | Watching for |
|---|---|
| Simple left/right | Baseline correctness |
| Flyover entry and exit | Does Maps distinguish it, or is it just "keep left"? |
| Service road vs main | The Bangalore-specific failure case |
| U-turn | Icon classified correctly |
| Rapid left-right < 100 m apart | Does next-maneuver arrive in time to help? |
| Complicated junction | Is one arrow enough information? |
| Deliberate missed turn | Reroute state, and how fast it recovers |
| Underpass / GPS loss | Stale detection fires |
| Phone out of range | Disconnect state |
| 45+ minute ride | Thermal, memory leaks, BLE stability |

Keep a note per ride: what confused you, what you'd want bigger, what you
didn't need on screen.

### Gate
Ten scenarios pass. You've ridden a real route and not missed a turn.
→ commit to hardware

---

# STAGE 9 — Extra features

**Goal:** everything the protocol already anticipated.

**Needs:** LDR + 10k resistor (~₹15) **or** BH1750 (~₹120). The LDR is
genuinely sufficient — you need bright/dim/dark, not calibrated lux.

### Tasks
1. **Caller ID + now-playing.** `MediaSessionManager` on Android needs
   notification-listener permission and nothing else — already granted. Send
   CALL and MEDIA packets. Display as a bottom strip, suppressed below 100 m to
   a maneuver.
2. **Trip stats.** Phone computes from its own GPS, sends TRIP. Display on the
   idle screen when not navigating.
3. **Auto-dim.** LDR on GPIO 34 (3.3V → LDR → GPIO34 → 10k → GND), or BH1750 on
   I2C (SDA 21, SCL 22). PWM the display's LED pin. Smooth over ~2 s or it
   flickers under streetlights.

### Test
- Ring the phone mid-navigation → caller name appears, and does *not* obscure a
  maneuver under 100 m.
- Ride from daylight into a tunnel → backlight ramps smoothly, no flicker.
- Ride at night past streetlights → no strobing.

---

# STAGE 10 — OTA, before anything is sealed ★

**Goal:** never need a cable again.

**Needs:** nothing.

### Tasks
1. ArduinoOTA. Device joins home WiFi when in range, otherwise carries on.
2. Version string on the boot screen so you can confirm an update landed.
3. Update **twice** over the air, including one where the new firmware changes
   something visible.

### Test
Flash a firmware over WiFi that changes the boot version string. Reboot.
Confirm. Then do it again from the changed firmware — this proves the OTA
partition rotation works, which a single update does not.

### Gate
Two successive OTA updates, no cable. **Do not proceed until this passes.**
Discovering OTA is broken after the case is glued is a bad afternoon.

---

# STAGE 11 — Hardware build

**Goal:** a mounted device.

### Buy list

| Item | ~₹ |
|---|---|
| Soldering iron, solder, flux, wick | 400–1,200 |
| Perfboard, berg strips, heat-shrink | 240 |
| Wire stripper, flush cutters | 350 |
| Multimeter | 600 |
| Right-angle USB-C cable 30 cm | 200 |
| SMBJ5.0A TVS, 470 µF low-ESR, 1 A inline fuse | 140 |
| 3D printed case — **PETG or ASA, never PLA** | 300–600 |
| 2 mm polycarbonate window + anti-glare film | 200 |
| Silicone gasket cord, M3 screws, heat-set inserts | 300 |
| Rubber grommets for vibration isolation | 100 |
| Printed adapter onto your existing BOBO clamp | 100 |

Borrowing the iron and multimeter and using a friend's printer takes this from
~₹2,900 to ~₹1,200.

**PLA softens near 55 °C.** A dark case parked in Bangalore sun exceeds that.
Your case will sag. PETG or ASA.

### Tasks
1. Solder to perfboard. Test after **every** connection, not at the end.
2. Power conditioning: TVS across 5V, 470 µF bulk, fuse in line. The bike's
   harness produces transients when the ignition cuts.
3. Case: display footprint 50 × 86 mm, landscape → roughly 94 × 58 × 20 mm.
   Light colour to reduce heat soak. Integrated sunshade hood.
4. Mount on the BOBO clamp with rubber isolation.

### Test
- Continuity on every joint before powering up.
- 30-minute vibration test: device on the running bike, stationary, watching
  for resets or flicker.
- Water test: shower head on the sealed case for 5 minutes, unpowered, then
  open and check for ingress. Do this before you trust it in rain.
- Thermal: parked in direct sun for 1 hour, then check the case hasn't
  deformed and it still boots.

---

# STAGE 12 — Validation

Progressive: 15 min → 30 min → 1 hr → 2 hr → first rain → first long trip.

After each, check: any resets, any BLE drops, any stale-data events, case
temperature, whether anything has worked loose.

---

# Gate summary

| Gate | Kills or reshapes the project if failed |
|---|---|
| **Stage 2** — Maps data usable? | Forces pivot to OsmAnd |
| **Stage 4** — readable at noon? | Forces display class change; breaks budget |
| **Stage 10** — OTA works? | Forces the case to stay openable |

Stages 2 and 4 both cost effectively nothing and can be reached within a week
of the parts arriving. Reach them before spending anything further.

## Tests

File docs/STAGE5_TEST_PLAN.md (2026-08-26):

# Stage 5 acceptance tests — BLE link and protocol

The Stage 5 gate in `BUILD_PLAN.md` is one sentence: *"Round-trip works,
reconnect is automatic."* This document is that sentence made concrete enough to
fail.

There are two paths through it. They test the same firmware and either is
sufficient for the gate:

- **nRF Connect** on the phone. No laptop, no Python. Paste hex by hand. Good
  for the single-packet tests, hopeless for anything timed.
- **`tools/navsim.py`** on the Windows laptop. Needs Python and `bleak`. This is
  the only way to run the ride, the watchdog, the flood and the garbage tests,
  because they all depend on packet *timing*.

Keep the Arduino IDE serial monitor open at 115200 throughout. Half of every
test below is reading the ESP32's own account of what it received.

---

## ★ The worked example in BUILD_PLAN.md is wrong

`BUILD_PLAN.md` Stage 5 says to send:

```
01 0F 03 64 00 02 50 00 0C 00 20 00 01     + "Old Madras Rd"
```

**Verified by hand against the spec. The field order and every value are
correct. The length byte is not.**

Decoding it field by field against
`u8 maneuver, u16 dist_m, u8 next_maneuver, u16 next_dist_m, u16 eta_min, u16 remaining_100m, u8 flags, utf8 instruction`:

| Bytes | Field | Value | Matches the expected output? |
|---|---|---|---|
| `01` | type | PKT_NAV | yes |
| `0F` | len | 15 | **no — see below** |
| `03` | maneuver | TURN_RIGHT | yes |
| `64 00` | dist_m | 100 | yes |
| `02` | next_maneuver | TURN_LEFT | yes |
| `50 00` | next_dist_m | 80 | yes |
| `0C 00` | eta_min | 12 | yes |
| `20 00` | remaining_100m | 32 → 3.2 km | yes |
| `01` | flags | nav_active | yes |
| `4F 6C 64 …` | instruction | "Old Madras Rd" | yes |

The payload is 11 fixed bytes (1+2+1+2+2+2+1) plus a 13-byte instruction —
**24 bytes, `0x18`**. `0x0F` is 15, and 15 is not the payload length (24), not
the frame length (26), not the fixed-field length (11), not the instruction
length (13), and not the 11 bytes actually printed after it in the plan. It
matches nothing under any reading.

**Corrected string — use this one everywhere:**

```
01 18 03 64 00 02 50 00 0C 00 20 00 01 4F 6C 64 20 4D 61 64 72 61 73 20 52 64
```

26 bytes total. `tools/navsim.py --selftest` re-derives this from the spec and
prints both versions, so the correction can be re-checked rather than trusted.

### Two related things the spec should say and does not

**1. `len` counts the payload, not the frame.** `[type:u8][len:u8][payload…]`
implies it, but it is never stated, and it matters: the NAV instruction has no
length prefix and no terminator, so `len` is the only thing that describes it.

How `ble.cpp` resolves this is worth knowing before you interpret any result
below. It treats **`len` as advisory** and bounds every read by the **ATT write
length**, which is the only length the radio actually guarantees:

- `len > arrived` → the write was truncated or corrupt. **Frame dropped.**
- `len < arrived` → **tolerated**, and the full write is parsed.

That second rule is why BUILD_PLAN's buggy `01 0F …` string *works* on this
firmware: 15 is less than the 24 bytes that arrive, so it is accepted and the
road name appears. The firmware is being deliberately generous to a phone that
miscounts.

That does not make the example correct, and it does not let the Android app off:
**it must send `0x18`**, because a stricter peripheral — including any future
rewrite of this one — is entitled to drop a frame whose length byte disagrees
with its contents. Test A5 covers the direction that must always be rejected.

Whatever policy is chosen, the safety property is the same: **never read past
the end of the write**, and reject any NAV frame with fewer than 11 payload
bytes.

**2. `STALE_MS` is contradicted inside the plan.** `BLE_PROTOCOL.md` says
*"No packet for 10 s"*, and `nav_types.h` sets `STALE_MS = 10000`. But
`BUILD_PLAN.md` Stage 7 says *"No packet 5 s"* and *"Watchdog:
`millis() - lastPacket > 5000`"*. **10 s is correct** — it is the value in the
shared header, and `NAV_DATA.md` derives it. Stage 7 of BUILD_PLAN.md should be
corrected. Test 4 below assumes 10 s.

Minor: `BUILD_PLAN.md`'s Stage 5 packet table omits `0x07 TRAFFIC`, which
`BLE_PROTOCOL.md` has. And `NAV_DATA.md` calls
`"Slight right at Horamavu Agara Circle onto Horamavu Agara Rd"` a 59-character
string; it is 60. Still inside `INSTRUCTION_MAX` (64), but only just — the
buffer holds 63 characters plus a NUL, so it has three characters of headroom,
not four.

---

## Path A — nRF Connect, no laptop

1. Power the ESP32. Serial should show it advertising.
2. nRF Connect → SCAN → find **`JiffyTrails`** (`DEVICE_NAME` in
   `navigator.ino`) → CONNECT.
3. Expand service `6E400001-B5A3-F393-E0A9-E50E24DCCA9E`.
4. On characteristic `6E400002-…` tap the **up arrow** (write). Set the format
   to **BYTE ARRAY**, paste a string below, SEND.
5. On characteristic `6E400003-…` tap **Subscribe** first, so anything the ESP32
   notifies back is visible.

Paste the hex without spaces if nRF Connect rejects them. Each string is given
here spaced for reading.

### A1 · Normal NAV packet

```
01 18 03 64 00 02 50 00 0C 00 20 00 01 4F 6C 64 20 4D 61 64 72 61 73 20 52 64
```

TURN_RIGHT, 100 m, next TURN_LEFT 80 m, ETA 12 min, 3.2 km remaining, active,
"Old Madras Rd".

**Serial must print:** `TURN_RIGHT, 100 m, next TURN_LEFT 80 m, ETA 12, 3.2 km,
active, "Old Madras Rd"`.
**Screen must show:** UI_NAV_COMMITTED — full-screen arrow and distance, nothing
else. 100 m is the boundary; per `screenFor()`, `dist_m < 100` is COMMITTED, so
exactly 100 falls in APPROACH. Confirm which one you get and that it matches
`screenFor()` rather than looking plausible.

### A2 · Under 30 m — the inverted screen

```
01 1B 03 14 00 00 00 00 08 00 15 00 01 54 43 20 50 61 6C 79 61 20 4D 61 69 6E 20 52 64
```

TURN_RIGHT, 20 m, no next maneuver, ETA 8, 2.1 km, active, "TC Palya Main Rd".

**Screen must show:** UI_NAV_NOW — inverted colours, full-screen arrow, 20 m.
Nothing else on screen.

### A3 · Rerouting — the arrow must disappear

```
01 14 03 78 00 00 00 00 0C 00 1E 00 03 52 65 72 6F 75 74 69 6E 67
```

TURN_RIGHT, 120 m, flags `0x03` = nav_active + rerouting, "Rerouting".

**Screen must show:** "REROUTING", **arrow suppressed** — even though the packet
still carries `maneuver = TURN_RIGHT` and a distance. This is the whole point:
the old turn is no longer true, and a firmware that keeps drawing the arrow
because the field is still populated has failed.

Send A1 immediately after. The arrow must come straight back. `NAV_DATA.md`
measured reroute recovery at 300–600 ms, so there is no excuse for a slow
return.

### A4 · nav_active = 0 — navigation ended

```
01 0B 00 00 00 00 00 00 00 00 00 00 00
```

All-zero NAV payload, 11 bytes, flags `0x00`.

**Screen must show:** the idle screen — clock and trip stats. **No arrow, no
distance, no leftover road name.** Send A1 first so there is a maneuver on
screen to fail to clear.

This is the test that catches a display which only ever overwrites fields
instead of switching state.

### A5 · Malformed — the length byte lies

```
01 18 03 64 00 02 50 00 0C 00 20 00 01
```

Identical to A1 but with the instruction cut off: `len` claims 24 payload bytes,
only 11 arrive.

**Must be rejected.** Serial should say so. The screen must not change at all —
not even to a partly updated maneuver. A firmware that reads the 11 valid bytes
and shrugs at the missing 13 will read past the end of the buffer on the day a
real packet is truncated by a short MTU.

### A6 · Malformed — unknown packet type

```
7F 04 DE AD BE EF
```

**No screen change**, no serial error storm. Unknown types are the
forward-compatibility feature the whole framing exists for.

It must, however, still **feed the stale watchdog**. Freshness is measured in
packet arrivals, and an unknown type proves the link is alive just as well as a
NAV packet does. Confirm on serial that the arrival was counted.

### A7 · Malformed — a one-byte write

```
01
```

**Must be ignored.** Two bytes are needed before `len` can even be read.

### A8 · Malformed — NAV with len = 0

```
01 00
```

**Must be ignored.** A NAV payload is at least 11 bytes.

### A9 · Extras worth pasting

| What | Hex |
|---|---|
| gps_weak, 500 m, CONTINUE, "Outer Ring Rd" | `01 18 01 F4 01 00 00 00 0A 00 1C 00 05 4F 75 74 65 72 20 52 69 6E 67 20 52 64` |
| Unknown maneuver → must render `?` | `01 17 00 F0 00 00 00 00 07 00 12 00 01 55 6E 6E 61 6D 65 64 20 72 6F 61 64` |
| Far band, 1.2 km | `01 18 01 B0 04 03 2C 01 0E 00 2A 00 01 4F 6C 64 20 4D 61 64 72 61 73 20 52 64` |
| Approach band, 350 m | `01 1B 03 5E 01 02 78 00 0B 00 20 00 01 54 43 20 50 61 6C 79 61 20 4D 61 69 6E 20 52 64` |
| Committed band, 80 m | `01 1F 02 50 00 01 90 01 09 00 18 00 01 4B 61 6D 6D 61 6E 61 68 61 6C 6C 69 20 4D 61 69 6E 20 52 64` |
| Arrived, DESTINATION, flags `0x09` | `01 13 14 00 00 00 00 00 00 00 00 00 09 41 72 72 69 76 69 6E 67` |
| Roundabout exit 3, reserved code `0x23` | `01 19 23 C8 00 00 00 00 09 00 16 00 01 48 65 6E 6E 75 72 20 4D 61 69 6E 20 52 64` |
| STATUS, phone battery 42% | `02 02 00 2A` |

`gps_weak` must be a **small corner warning** over an otherwise normal nav
screen, not a takeover. The unknown maneuver must render `?` — a confidently
wrong arrow is worse than no arrow. The reserved roundabout code may render a
roundabout glyph or `?`, but never a plain turn arrow.

`navsim.py --nrf` prints this list with decodes, if you would rather copy it
from a terminal than a table.

---

## Path B — navsim.py from the laptop

Setup is in `tools/README.md`. In short: install Python, `py -m pip install
bleak`, then `py navsim.py --scan` to confirm `JiffyTrails` is advertising.

Note the advertisement carries the 128-bit service UUID, which fills the 31-byte
advertising packet — the name comes from the scan response, so a scanner set to
passive scanning will show the device with no name. `--scan` uses active
scanning and will show it.

Run each test from `C:\dev\jiffytrails-navigator\tools`.

### Test 1 · Round trip

```powershell
py navsim.py --screen approach
```

**Pass:** the tool connects, reports the negotiated MTU, finds the service and
both characteristics, subscribes to notifications, and the panel shows the
350 m approach screen within one second. Every laptop `TX` line has a matching
ESP32 serial line agreeing field for field.

**Fail:** service not found (wrong firmware or wrong UUIDs); write rejected;
serial disagrees with the decoded line.

On Windows the central cannot request an MTU — WinRT negotiates it. The ESP32
must ask for 185 on connect. The tool prints what was agreed. A write can carry
`MTU − 3` bytes; the longest packet used here is 73 bytes, so anything from 76
up is sufficient. If the reported MTU is 23 (the default), long instructions
will be truncated by the stack and Test 3 will fail for a reason that is not the
display's fault.

### Test 2 · Every distance band, photographed

```powershell
py navsim.py --screen far
py navsim.py --screen approach
py navsim.py --screen committed
py navsim.py --screen now
```

Each holds indefinitely. Photograph the panel **at arm's length — mount height,
not reading distance**, sunglasses on if you ride with them.

**Pass:** each band is readable in under half a second. Anything you have to
look at twice is too small.

Also run `--screen longtext`, which sends the 60-character instruction observed
in the wild. **Pass:** the road name survives. Per `NAV_DATA.md`, truncating
from the end destroys the useful half — drop the maneuver prefix instead, since
the arrow already conveys it.

And `--screen unknown` and `--screen roundabout`, per A9 above.

### Test 3 · The ride ★

```powershell
py navsim.py --ride
```

Eight legs, about 6 km, roughly ten minutes at 1 Hz. This is the test that
matters, because it is the only one that feeds the display data shaped like real
data.

Watch for, in order of importance:

1. **Quantised distances.** The digits skip: 290 → 270 → 250 → 230. They are
   *supposed* to. If the display smooths or interpolates them, it is inventing
   data. The `dist=` field in the console is ground truth.
2. **The reroute on leg 4.** Screen says REROUTING and the arrow disappears,
   then comes back on the next normal packet.
3. **The gps_weak stretch on leg 6.** Small corner warning, nav screen otherwise
   unchanged.
4. **`next_maneuver` is always UNKNOWN/0**, because Google Maps has no such
   field. Whatever the display does with it must survive it being empty for the
   entire ride.
5. **Remaining distance drifts** by a few percent every packet, because
   `progressMax` does. The display must not treat a decrease-then-increase as an
   error.
6. **The ending.** The ride finishes with five `arrived` packets and then eight
   explicit `nav_active = 0` packets. The panel must drop to the idle screen and
   keep no trace of the last maneuver.

Then run it again hard:

```powershell
py navsim.py --ride --speed-mult 4
```

Same 1 Hz packet rate, four times the ground speed, so the digits skip in much
larger jumps. **Pass:** no flicker, no tearing, the distance field redraws
cleanly at every jump.

### Test 4 · The stale watchdog ★

```powershell
py navsim.py --stale
```

Ten seconds of normal traffic, then silence **while staying connected**, then
traffic again after 25 s.

**Pass:** about 10 s after the last packet the panel dims and shows STALE. When
packets resume, the nav screen returns within one packet — no reset, no button.

**Fail, three distinct ways:**

- The maneuver is still on screen after 10 s. The watchdog did not fire.
- The panel shows PHONE DISCONNECTED. The link is still up; the firmware is
  confusing a dead link with dead data. These are separate states in
  `screenFor()` and must stay separate — one means "look at your phone", the
  other means "the phone is here but not talking".
- The panel goes stale at 5 s. That is the wrong constant — see the
  BUILD_PLAN Stage 7 contradiction above. `STALE_MS` is 10000.

The watchdog must count **packet arrivals, not value changes**. `NAV_DATA.md`
measured 64 seconds in slow traffic with no field changing at all while Maps
kept posting at 1 Hz. To prove the firmware got this right, hold `--screen far`
for two minutes: the values never change, and the display must **never** go
stale.

### Test 5 · Flood

```powershell
py navsim.py --flood
```

20 Hz for 30 seconds — about twenty times the real rate — with values changing
on every packet, then back to 1 Hz.

**Note the ESP32's free heap before and after.**

**Pass:** no torn digits, no half-drawn arrow, no reset, no watchdog trip, and
free heap flat to within a few hundred bytes. Dropping packets under flood is
fine and expected; rendering a partial frame is not. Afterwards the panel
settles clean.

**Fail:** free heap trending steadily down — an allocation in the packet
handler. Or the panel left with artefacts from the last fast frame.

### Test 6 · Garbage ★

```powershell
py navsim.py --garbage
```

Every malformed packet in the tool's list, 1.5 s apart: empty writes, truncated
payloads, a length byte that lies in both directions, unknown types, a 200-byte
instruction against a 64-byte buffer, invalid UTF-8, an embedded NUL, maneuver
`0xFF`, `dist_m` at the u16 maximum, 256 bytes of noise. It starts from a
known-good screen and **ends with a valid packet**.

Each case prints an `EXPECT:` line saying whether it should be rejected or
accepted — read those rather than assuming every case leaves the screen alone.
Two are *supposed* to be accepted, under the advisory-`len` rule above.

**Note the ESP32's free heap before and after.**

**Pass:** every case behaves as its `EXPECT:` line says; the ESP32 does not
reboot (watch for a boot banner on serial); the BLE link stays up; free heap is
unchanged; and the **final valid packet renders correctly**.

That last clause is the real test. A parser that latches into a rejecting state
and ignores everything afterwards has failed exactly as badly as one that
crashes — and it fails silently, which is worse.

Two specific things to look for:
- Maneuver `0xFF` must render `?`.
- The 200-byte instruction must be truncated to fit `INSTRUCTION_MAX` **and
  still be NUL terminated**. This is the buffer-overflow case; a reboot here is
  a stack smash, not a rejection.

### Test 7 · Reconnect — walk 30 m away and back ★

This is the gate condition from `BUILD_PLAN.md`, and the one most likely to be
declared passed without actually being tested.

```powershell
py navsim.py --ride --reconnect
```

Then, carrying the laptop:

1. Wait until the ride is running and the panel is showing maneuvers.
2. Walk **30 m away** from the ESP32 — far enough that the link genuinely drops.
   The console prints `*** BLE DISCONNECTED ***` and the panel must change to
   PHONE DISCONNECTED. If it does not drop, go further; through a wall is
   better than down a corridor.
3. Stay out of range for at least 30 seconds, so this is a real disconnect and
   not a momentary glitch.
4. Walk back.

**Pass, all four conditions:**

- The panel showed **PHONE DISCONNECTED** while away — not STALE, and not a
  frozen maneuver.
- The link comes back **within 10 s** of returning to range. The tool times this
  and prints `RECONNECTED in N.N s` with a PASS or FAIL against the 10 s gate.
- **No button is pressed at either end.** No reset on the ESP32, no keypress on
  the laptop, no re-running the script. If you touched anything, the test did
  not pass.
- The ride resumes and the panel shows live maneuvers again.

**Fail:** the ESP32 stopped advertising after the disconnect. This is the usual
cause, and it is a one-line fix in the NimBLE disconnect callback — restart
advertising there, not only at boot.

Run it in both directions: also test the ESP32 losing power and coming back
while the tool keeps running.

**nRF Connect equivalent:** connect, walk away with the phone, walk back. nRF
Connect will not reconnect on its own, so this only tests that the ESP32 is
advertising again — tap CONNECT and confirm it works without touching the
ESP32. That is a weaker test than Path B, which is why the reconnect test is the
one argument for installing Python.

---

## The gate

Stage 5 passes when **all** of these are true:

| # | Condition | Test |
|---|---|---|
| 1 | A valid NAV packet round-trips and renders correctly | A1 / Test 1 |
| 2 | All four distance bands render and are readable at arm's length | Test 2 |
| 3 | Rerouting suppresses the arrow | A3 / Test 3 |
| 4 | `nav_active = 0` clears the maneuver completely | A4 / Test 3 |
| 5 | Stale fires at 10 s, and never fires on unchanging values | Test 4 |
| 6 | Stale and disconnected are distinct screens | Tests 4 and 7 |
| 7 | Malformed packets are rejected and a valid one still works after | A5–A8 / Test 6 |
| 8 | No reboot, no heap growth, under flood or garbage | Tests 5 and 6 |
| 9 | Reconnect within 10 s, unaided, no button at either end | Test 7 |

→ Stage 6.

Anything that fails, fix before writing the Android app. Every one of these
becomes ten times harder to diagnose once there is a phone in the loop, because
you can no longer tell which end is lying.

---

## Path A2 — vectors for the features added 26 Aug 2026

Alerts, arrival, clock and day/night landed after this plan was written. Byte
counts and ASCII verified, not hand-typed.

Send these on characteristic `6E400002-…`, BYTE ARRAY format, same as Path A.

### A10 · Incoming call

```
03 05 01 41 6D 6D 61
```

CALL, state 1 (ringing), name "Amma".

**Expect:** the bottom band **inverts to a solid black block** with white text —
tag "CALL", body "Amma". It persists while ringing.

Clear it with state 0:

```
03 01 00
```

### A11 · Notification

```
08 12 01 08 57 68 61 74 73 41 70 70 52 65 61 63 68 65 64 3F
```

NOTIFY, kind 1 (message), src "WhatsApp", text "Reached?".

**Expect:** band inverts, tag "WhatsApp", body "Reached?". **It must disappear
by itself after 6 seconds** — that is `NOTIFY_DWELL_MS`, and a notification that
persists has become a second thing to read on every glance.

### A12 · ★ The suppression rule — the important one

Send A11, then **within 6 seconds** send A2 (the 20 m packet).

**Expect: the band goes blank.** Not "the alert moves", not "the alert shrinks"
— blank. Under 100 m to a turn nothing may cover the maneuver, and the alert is
not queued for afterwards either.

This is the single most important behaviour in the alert feature. If the alert
survives A2, that is a bug and the turn is being obscured.

### A13 · Arrival

```
01 0F 14 00 00 00 00 00 00 00 00 00 09 48 6F 6D 65
```

NAV, maneuver DESTINATION, 0 m, flags `0x09` = nav_active + arrived,
instruction "Home".

**Expect:** destination flag glyph, "ARRIVED", and "Home". **It must hold for
about 30 seconds** (`ARRIVAL_DWELL_MS`) before falling back to idle — Maps drops
its notification about 4.7 s after arrival, so without the latch this screen
would flash past.

### A14 · Clock

```
02 04 00 4E 0E 23
```

STATUS, flags 0, battery 78%, 14:35.

**Expect:** nothing visible yet — then send `01 02 00 00` (a NAV with
nav_active = 0) to drop to idle, and the idle screen should show **14:35**
instead of READY.

Battery at 78% must **not** appear. It only shows at 20% or below — try
`02 04 00 0F 0E 23` (15%) and it should appear bottom-right.

### A15 · Day / night

```
06 03 00 00 01     night on
06 03 00 00 00     night off
```

**Expect on night:** the whole display inverts — near-black ground, and the text
should be **grey, not white**. If the text looks pure white, the grey-text change
did not take, and the point of night mode is lost.

The alert band should now be a **grey block with black text**, not a white
flash. Re-run A10 with night on to confirm.

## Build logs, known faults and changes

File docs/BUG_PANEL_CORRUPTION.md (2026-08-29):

# BUG: Panel corruption on the ARRIVED screen

**Observed:** one night ride, 2026-08-29. Photographed. Not reproduced.
**Status:** analysis complete, no source edited. Diagnostic document.

> **Epistemic warning, up front.** This is **one** observation of a physical
> fault, with no serial log, no scope trace and no reset-reason record. A single
> event constrains almost nothing quantitatively. Everything below is ranked by
> mechanism plausibility, not by evidence weight, and §7 separates what is
> **verified** from what is **inferred** from what is **unknown**. The most
> valuable output of this document is not the ranking — it is §8.0, the list of
> observations that would actually discriminate between the top hypotheses, and
> the zero-cost forensics sketch that can settle §2 in twenty minutes on the bench.

---

## 1. The observation

From the photograph, on the handlebar, at the end of a night ride:

| # | Symptom | |
|---|---|---|
| A | The word **ARRIVED** is drawn **mirrored horizontally**, and appears **vertically flipped** as well | reversed lettering |
| B | The **left ~40%** of the panel is a block of **diagonal hatching / noise**, visually distinct from the rest | |
| C | The **right portion is white**, with the mirrored text on it | |
| D | The state **persisted** long enough to be photographed | |

### 1.1 What each symptom is evidence *of*, before any hypothesis

- **(A) is evidence of a register, not of noise.** Stable, legible, geometrically
  coherent mirrored text is a *correctly executed write through a wrong address
  mapping*. Random bit errors do not produce readable mirrored glyphs. This
  points at MADCTL (0x36) and essentially nothing else. See §2.
- **(B) is evidence of stored pixels, not live interference.** It was stable
  enough to photograph, so it is content sitting in GRAM, not a display artefact.
  Something *wrote* that, or something *failed to overwrite* what was already
  there. See §4.
- **(C) tells us the `fillScreen` ran and mostly worked.** C_BG on the day
  palette is `TFT_WHITE` (`display.cpp:60`, `display.cpp:1241`). See §1.2 —
  this also tells us something about night mode.
- **(D) is, on this firmware, expected and not diagnostic of anything.** See §6.
  The ARRIVED screen paints once and then *never repaints*. Persistence is a
  property of the renderer, not of the fault.

### 1.2 A side finding: night mode was almost certainly OFF

`C_BG` is `TFT_WHITE` only in the day palette. In night mode
(`display.cpp:1234`) `C_BG = TFT_BLACK` and `C_FG = 0xDEFB`.

`nightMode` has exactly one writer — `displaySetNight(state.night)` from
`navigator.ino:94` — and `state.night` has exactly one writer, `handleConfig`
in `ble.cpp:269-272`, fed by an *optional tail byte* on the BLE CONFIG packet.
`NavState::night` defaults to `false` (`nav_types.h:115`).

So a **white** background on a **night** ride means one of:

1. **The phone never sent `night=1`** — the CONFIG packet was absent, or was the
   older short form without the night tail. Most likely; the Android side is
   still unbuilt (`navigator.ino:8` — "No Android app yet").
2. Night was set, and the panel additionally had **display inversion** turned on
   (INVON, 0x21) — which would flip black→white and the ~88% white text→dark.

Option 2 would be a *second* spontaneous register change, which raises the
prior on "a stray command byte was latched" considerably (§3.1). **This is
worth resolving and is free to resolve:** check whether the phone/navsim was
sending a CONFIG with night set on that ride. If night *was* configured, the
whole diagnosis changes and INVON joins MADCTL as a corrupted register.

**Action:** confirm from the ride's phone-side config whether `night=1` was sent.

---

## 2. Which register produces mirrored text: MADCTL (0x36)

### 2.1 What the firmware sets, and when

`display.cpp:41` — `static const uint8_t ROTATION = 1;` (landscape).

TFT_eSPI 2.5.43, `TFT_Drivers/ILI9341_Rotation.h`, case 1, non-M5STACK branch:

```c
writecommand(TFT_MADCTL);
writedata(TFT_MAD_MV | TFT_MAD_COLOR_ORDER);
```

With `TFT_MAD_MV = 0x20` and `TFT_MAD_COLOR_ORDER = TFT_MAD_BGR = 0x08`
(`TFT_Drivers/ILI9341_Defines.h:56-72`):

> **The expected runtime MADCTL value on this build is `0x28`.**

It is written in exactly two places, both of which call `setRotation(ROTATION)`:

- `displayBegin()` — `display.cpp:1069-1070`, once at boot.
- `displayTick()` recovery path — `display.cpp:1272-1273`, **unreachable**,
  because `panelReadable` is false on this wiring (`display.cpp:1252`).

**So MADCTL is written once per boot and never again.** For it to hold a wrong
value at ARRIVED time, the panel must have received a `0x36` command + parameter
it was never *deliberately* sent, **or** the boot-time write itself was
corrupted (which requires a reboot — see §3.3).

### 2.2 The bit definitions (datasheet, verbatim)

ILI9341 datasheet v1.11, **§8.2.29 Memory Access Control (36h)**, page 127
([ILI Technology / Adafruit mirror](https://cdn-shop.adafruit.com/datasheets/ILI9341.pdf),
also [Newhaven mirror](https://newhavendisplay.com/content/app_notes/ILI9341.pdf)):

| Bit | Mask | Name | Datasheet description |
|---|---|---|---|
| D7 | 0x80 | MY | Row Address Order |
| D6 | 0x40 | MX | Column Address Order |
| D5 | 0x20 | MV | Row / Column Exchange |
| D4 | 0x10 | ML | Vertical Refresh Order |
| D3 | 0x08 | BGR | RGB-BGR Order |
| D2 | 0x04 | MH | Horizontal Refresh Order |

Quoted exactly from the page:

> "This command defines read/write scanning direction of frame memory."
> "This command makes no change on the other driver status."
> MY / MX / MV: **"These 3 bits control MCU to memory write/read direction."**
> ML: "LCD vertical refresh direction control."
> MH: "LCD horizontal refreshing direction control."
> "Note: When BGR bit is changed, the new setting is active immediately without
> update the content in Frame Memory again."

**Reset default: `00h`** (the parameter row's HEX column on p.127).

### 2.3 ★ The single most important consequence, and it is easy to get wrong

**MY / MX / MV are *write-side* controls. They remap where incoming pixels
land. They do NOT move pixels already sitting in GRAM.**

The datasheet states this by contrast: it goes out of its way to say that the
**BGR** change *is* "active immediately without update the content in Frame
Memory again" — a note that is only worth writing because the neighbouring bits
are **not**. MY/MX/MV are described as controlling "MCU to memory write/read
direction", i.e. the address counter, and the panel's GRAM→pixel scan mapping
is fixed (ML/MH only alter refresh *order*, not placement).

This has three consequences that drive the whole rest of the analysis:

1. **A MADCTL change is not retroactive.** Whatever was on screen before the
   change stays exactly where it was. Only content drawn *afterwards* is
   mirrored. So the mirrored ARRIVED text was drawn **after** the corruption,
   and the white field it sits on was probably drawn **before** it.
2. **Re-asserting MADCTL does not fix a corrupted frame.** It fixes the *next*
   frame. This is the key limitation of the "just call `setRotation()`
   periodically" mitigation — see §5.1. It must be paired with a forced repaint.
3. **MADCTL also changes the panel's addressable extent** (§2.5), which is the
   bridge to symptom (B).

### 2.4 Which value produces "mirrored horizontally AND flipped vertically"

From `0x28` (MV | BGR), the candidates, using TFT_eSPI's own rotation table as
the reference for what each looks like:

| MADCTL | Bits vs 0x28 | TFT_eSPI rotation | Visual effect vs correct render | Geometry |
|---|---|---|---|---|
| `0x28` | — | 1 | **correct** | 320 × 240 landscape |
| `0x68` | +MX | 5 | mirrored horizontally only | 320 × 240 landscape |
| `0xA8` | +MY | 7 | flipped vertically only | 320 × 240 landscape |
| **`0xE8`** | **+MX +MY** | **3** | **180° rotation = H-mirror *and* V-flip** | **320 × 240 landscape** |
| `0x08` | −MV | — | transposed (90°), no mirror | **240 × 320 portrait** |
| `0xC8` | −MV +MX +MY | — | transposed **and** point-reflected | **240 × 320 portrait** |
| `0x00` | HW-reset default | — | transposed, RGB order (colours swapped) | **240 × 320 portrait** |

> **Symptom (A) — horizontally mirrored *and* vertically flipped, with the panel
> still filling as a 320-wide landscape screen — is `MADCTL = 0xE8`.**
> That is `TFT_MAD_MY | TFT_MAD_MX | TFT_MAD_MV | TFT_MAD_BGR`, i.e. exactly
> TFT_eSPI's **rotation 3**: the 180° partner of the rotation the firmware asks
> for. Two bits, D7 and D6, both flipped 0→1. Both are the **top two bits of the
> byte**, i.e. the **first two bits clocked out** on an MSB-first SPI write.

That last detail matters and is developed in §3.2.

**Caveat, and it is a real one.** A 180° rotation and a *transpose-plus-mirror*
(`0xC8`) both photograph as "reversed lettering that also looks upside down."
They are distinguishable — under `0xE8` the word still runs left-to-right along
the panel's long axis; under `0xC8` it runs along the short axis and the panel
geometry breaks. **Re-examining the photograph for which axis the word runs
along is the single cheapest discriminating observation available** (§8.0).

### 2.5 The bridge to symptom (B): MV changes the panel's addressable width

Datasheet **§8.2.20 CASET (2Ah)**, p.110, Note 1, verbatim:

> "When SC [15:0] or EC [15:0] is greater than 00EFh (When MADCTL's B5 = 0) or
> 013Fh (When MADCTL's B5 = 1), data of out of range will be ignored"

and the CASET default table, same page:

> "If MADCTL's B5 = 0: EC [15:0]=00EFh — If MADCTL's B5 = 1: EC [15:0]=013Fh"

**B5 is MV.** So:

- MV = 1 → columns 0…**319** valid. Landscape. TFT_eSPI's `CASET(0,319)` is legal.
- MV = 0 → columns 0…**239** valid. Portrait. TFT_eSPI still sends `CASET(0,319)`
  because `_width` is a host-side variable — and **the out-of-range data is
  ignored by the controller.**

So **any corruption that clears MV silently truncates every window the library
sets**, and the pushed pixel count no longer matches the window. That is a
direct, datasheet-supported mechanism for "part of the screen did not get
painted." Hold that thought for §4.

---

## 3. What makes MADCTL change spontaneously — ranked

MADCTL is not written at runtime (§2.1). So one of the following happened.

### 3.1 ★ H1 — A stray byte was latched as a command mid-transaction (D/C or CS integrity)

**Mechanism.** In 4-line SPI the panel decides "command vs data" solely from the
D/CX pin level at each byte boundary. `drawArrived()` pushes ~186 kB with **CS
held low the entire time** (TFT_eSPI brackets an operation with
`begin_tft_write`/`end_tft_write`; `CS_L`/`CS_H` in
`Processors/TFT_eSPI_ESP32.h:204-239`). If D/CX (GPIO 2) dips low for one byte
period, the panel latches whatever byte is on the bus **as a command**, and
subsequent bytes as its parameters. If that byte happens to be `0x36`, the very
next byte becomes the new MADCTL.

**Is `0x36` reachable in the pixel stream?** In a solid `fillScreen(WHITE)` the
stream is all `0xFF` — `0x36` never appears, and `0xFF` is not a defined ILI9341
command. But `drawArrived()` also draws a 72 px maneuver glyph and smooth-font
text (`SMOOTH_FONT` is enabled, `User_Setup.h:40`), whose anti-aliased blend
colours span the full byte range. `0x36` is reachable there. Likewise `0x21`
(INVON) — relevant if §1.2 option 2 holds.

**Corroborating datasheet fact** (§8.2.22 RAMWR, p.114, verbatim):

> "Sending any other command can stop frame Write."

So a single spurious command byte does **two** things at once: it changes a
register **and** aborts the in-progress pixel write, leaving a region unpainted.
**One glitch, both symptoms.** This is why H1 ranks first — it is the only
single-event hypothesis that reaches for both (A) and (B) without extra
assumptions.

**Physical plausibility.** D/CX is GPIO 2 on this build (`User_Setup.h:23`).
GPIO 2 is an ESP32 **strapping pin** and on most LOLIN32-class boards carries an
onboard LED and/or a pull-down — extra capacitance and a bias toward the
*dangerous* level (low = command mode). On an MB102 with ~150–200 mm dupont
wires, adjacent conductors couple ~1–2 pF/cm. A 3.3 V edge with ESP32's ~1–2 ns
slew into ~2 pF of mutual capacitance against D/CX's ~50 pF load injects on the
order of 100–150 mV per aggressor edge — normally well inside the noise margin,
but the margin is already eroded by a rail measured at **3.18 V** (HARDWARE.md
line 47) and by running the bus at 2.7× the datasheet clock (§3.6).

**Rank: 1 of 5.** Best explanatory coverage. Unverified.

### 3.2 H2 — SPI bit errors from breadboard SI at 27 MHz

**The numbers.**

| Quantity | Value |
|---|---|
| SPI clock | 27 MHz (`User_Setup.h:44`) |
| Bit period | **37.04 ns** |
| Nominal SCK high / low | 18.5 ns each |
| **Datasheet min `twc` (serial clock cycle, write)** | **100 ns → 10 MHz max** |
| Datasheet min `twrh` / `twrl` (SCK H/L pulse width) | 40 ns each |
| Datasheet max `tr` / `tf` | 15 ns |
| Data setup `tds` / hold `tdh` | 10 ns |
| D/CX setup `tas` / hold `tah` | 10 ns |
| CS setup `tcss` | 40 ns |

Source: datasheet **§18.3.4 Display Serial Interface Timing Characteristics
(4-line SPI system)**, p.243. *(The PDF's table columns extract with mangled
alignment; the `twc = 100 ns` figure matches the widely cited ILI9341 10 MHz
write-clock spec and I am confident in it. Treat the sub-figures as indicative.)*

> **★ This build runs the panel at 2.7× its specified maximum write clock, and
> its SCK pulse widths are 46% of the specified minimum.** A 40 MHz build would
> be 4×. This is completely normal practice with ILI9341 — the part is far more
> capable than its spec — but it means **there is no guard band at all**. Every
> other marginality (a 4% low rail, breadboard inductance, a hot enclosure,
> vibration on a dupont contact) eats directly into a margin the datasheet does
> not promise exists.

Also note: at 27 MHz the bit cell is 37 ns against a **15 ns** specified
rise/fall time — **edges occupy up to 40% of the bit cell**. At 20 MHz that
falls to 30%, at 10 MHz to 15%. This is the honest reason to reduce the clock
(§5.2), and it scales linearly with period, not dramatically.

**The rate argument — why this fits "worked for months, failed once".**
A full-screen fill is 320 × 240 × 16 = **1,228,800 bits**. `drawArrived()`
in total is roughly:

| Operation | Pixels | Bytes | Time @27 MHz |
|---|---|---|---|
| `fillScreen(C_BG)` | 76,800 | 153,600 | **45.5 ms** |
| `drawManeuver` 72×72 box | ≤5,184 | ≤10,368 | ≤3.1 ms |
| "ARRIVED", font 4, size 2 | ~11,000 | ~22,000 | ~6.5 ms |
| **total** | **~93,000** | **~186,000** | **~55 ms**, ~1.49 Mbit |

If the bit error rate were 1 × 10⁻⁶, you would get **1.2 errors per fill** —
constant, obvious, unmissable corruption. One event in months of use implies a
BER somewhere around **10⁻⁹ to 10⁻¹⁰**. That is the signature of a link that is
*fine* until a second stressor arrives, and it is exactly why this will not
reproduce on a bench at room temperature.

**Weakness of H2 alone.** Random bit errors in a `fillScreen(0xFFFF)` stream are
*invisible* — every bit is already 1, and a dropped or inserted clock in an
all-ones stream produces all ones. Bit errors do not by themselves rewrite
MADCTL; they need H1's D/CX mechanism to become a *command*. **H2 is best
understood as the enabling condition for H1, not as a competing explanation.**

**Rank: 2 of 5 — as an enabler.** Partly verified (the clock overspec is a hard
fact; the error rate is inferred).

### 3.3 H3 — Brown-out reboot of the ESP32, with a corrupted MADCTL on re-init

**Mechanism.** The 3.3 V rail dips (BLE TX burst, backlight, vibration on a
power jumper, a marginal USB/12 V source). The ESP32 brown-out detector fires
and resets. `setup()` re-runs, `displayBegin()` calls `tft.init()` +
`setRotation(1)`. If **that** MADCTL parameter byte is corrupted — and it is
being written moments after a supply event, the worst possible moment for signal
integrity — the panel is 180° for the rest of the session.

**Supporting detail.** Remember the wrong value is `0xE8` and the correct one is
`0x28`: the two changed bits are D7 and D6, **the first two bits clocked out of
an MSB-first byte**. A byte whose *leading* bits read high is precisely the
signature of a line still ringing/settling from the transition that preceded it
— CS falling, or D/CX going high after the command byte. This is a suspiciously
good fit and is worth taking seriously.

**Testable for free.** `esp_reset_reason()` at boot, printed to serial, plus a
boot counter in RTC-retained memory. See §8.1. **Nothing currently records
this**, so a mid-ride reboot is presently invisible after the fact.

**Weakness.** A reboot would drop to `UI_DISCONNECTED`, require BLE
re-connection, and require the phone to re-send an ARRIVED packet. Possible, but
it is a chain. And it still does not explain (B): after a reboot,
`displayBegin()` does a full `fillScreen`, and with MV still set in `0xE8` that
fill covers the whole panel.

**Rank: 3 of 5.** Unverified, but the *cheapest to rule in or out*.

### 3.4 H4 — Missing decoupling / supply dip without a reboot

HARDWARE.md records **3.18 V at the `3V` pin with the backlight lit** (line 47,
22 Aug 2026) — a 4% droop, described there as "the LDO working rather than
coasting." There is no mention anywhere in the repo of a decoupling capacitor
at the panel.

The dynamic picture is worse than the static one. The ESP32's BT/BLE transmitter
draws burst currents in the ~100–130 mA region on advertising and connection
events, with edges in the microsecond range. An MB102 breadboard rail presents
roughly 10–20 nH per inch of loop inductance with no bulk capacitance near the
load. dI/dt of 100 mA in 1 µs across ~100 nH is only ~10 mV, but the real
transients are far faster than 1 µs and the MB102's own power module is
notoriously soft. A supply that is already 4% low and dipping further at radio
cadence narrows every logic threshold on both ends of the bus simultaneously.

This is **a cause of H1 and H2**, not an independent path to a wrong MADCTL.
But it is the cheapest thing on the entire list to fix (§5.3), so it earns its
rank on remediation value rather than on explanatory power.

**Rank: 4 of 5 as a direct cause; ★ rank 1 as a thing to fix.**

### 3.5 H5 — Floating or glitched RESET — ✗ **effectively ruled out**

Datasheet **§15.4 Reset Timing**, p.230, verbatim:

| RESX Pulse | Action |
|---|---|
| Shorter than 5 µs | **Reset Rejected** |
| Longer than 10 µs | Reset |
| Between 5 and 10 µs | Reset starts |

> "Note 3: During the Resetting period, **the display will be blanked** ... And
> then return to Default condition for Hardware Reset."

Two independent reasons this is not what happened:

1. **A reset blanks the display.** The photographed screen showed content. That
   is the signature of the *previously observed* failure documented at
   `display.cpp:800-805` ("renders correctly, then goes blank white") — a
   **different** fault. This one is not that one.
2. **A reset sets MADCTL to `00h`**, which clears MV → portrait geometry and
   RGB colour order. Symptom (A) requires MV *set*.

Also: the panel would need SLPOUT + DISPON re-issued to show anything, and
nothing in the firmware does that outside `tft.init()`. And RESX has ≤5 µs spike
rejection, so casual noise cannot trigger it.

**Rank: 5 of 5 for this event.** Still worth fixing on general principles (§5.6)
— GPIO 16 is driven by `tft.init()` and is *not* floating during operation, but
it is undefined while the ESP32 boots or browns out.

### 3.6 Summary ranking

| # | Hypothesis | Explains (A) mirror | Explains (B) band | Explains (C) white | Cheap to test? |
|---|---|---|---|---|---|
| **H1** | Stray byte latched as a command (D/CX or CS) | ✔ | ✔ (RAMWR abort) | ✔ | scope, or §8.0 photo re-read |
| **H2** | SPI bit errors at 2.7× spec clock | enabler only | ✗ alone | ✔ | lower the clock and wait |
| **H3** | Brown-out reboot + corrupted re-init MADCTL | ✔ | ✗ | ✔ | ★ **free** — log reset reason |
| **H4** | Supply dip / no decoupling | enabler only | ✗ alone | ✔ | ★ **₹5** — fit the caps |
| **H5** | RESET glitch | ✗ (gives `00h`) | ✗ | ✗ (blanks) | ruled out |

**No single hypothesis explains all three symptoms without assistance.** H1 comes
closest and is the only one that reaches (B) natively. §4 examines whether (B)
is really a separate event.

---

## 4. Why the left ~40% is hatching — and what a one-byte shift really does

### 4.1 Establish the raster geometry first

This is the part that does the real work, so it is worth being exact.

`RAMWR` (datasheet §8.2.22, p.114, verbatim):

> "When this command is accepted, the column register and the page register are
> reset to the Start Column/Start Page positions. **The Start Column/Start Page
> positions are different in accordance with MADCTL setting.** Then D [17:0] is
> stored in frame memory and the column register and the page register
> incremented."

The **column register increments first**. With `MADCTL = 0x28` (MV set), the
column range is 0…319 (§2.5), which maps to the panel's **long axis** — the
**horizontal** axis as this device is mounted (landscape).

> **Therefore, in normal operation, `fillScreen` raster-scans in horizontal
> lines: 320 px per line, 240 lines.**

| | |
|---|---|
| One pixel | 16 bits ÷ 27 MHz = **592.6 ns** |
| One 320 px line | 5,120 bits = **189.6 µs** |
| Full 240-line frame | **45.5 ms** (matches HARDWARE.md line 106) |

### 4.2 ★ The geometric constraint that does most of the diagnosis

From §4.1, with MV set, **every** anomaly bounded in *time* during a fill —
a noise burst, a truncated write, an aborted RAMWR — produces a band of whole
**lines**, i.e. a **horizontal** band across the full width.

**Only MV = 0 makes the fast axis vertical**, because then the column register
spans the panel's 240-axis, which is vertical in this mounting. And MV = 0 is
also the case where TFT_eSPI's `CASET(0,319)` goes out of range and, per the
datasheet Note 1 quoted in §2.5, the out-of-range data **"will be ignored"**.

So the two symptoms make opposite demands:

| Symptom | Requires |
|---|---|
| (A) mirrored, **not transposed**, text on a 320-wide layout | **MV = 1** |
| (B) a **full-height vertical** band down one side | **MV = 0** |

> **These cannot both be true of a single MADCTL value.** One of three things
> must therefore hold:
>
> 1. **The band is actually horizontal (top or bottom), not vertical**, and the
>    "left 40%" reading is an artefact of judging orientation from a screen
>    whose content is already mirrored. **This is the most likely resolution and
>    the cheapest to check — just look at the photograph again.**
> 2. **MADCTL changed more than once** during the frame (fill under one value,
>    text under another). Possible under H1, since a stray command byte can
>    arrive at any point in the 55 ms.
> 3. **The word is transposed rather than mirrored**, i.e. MADCTL was `0xC8` or
>    `0x08` throughout, the layout ran down the panel's short axis, and "mirrored
>    horizontally and flipped vertically" is a reasonable but imprecise
>    description of a 90°-rotated, point-reflected render.

**§8.0 turns this into a ten-minute bench test that settles it outright.**

### 4.3 What a one-byte shift in a 16 bpp stream actually does

The question was asked specifically, and the answer rules a hypothesis *out*,
which is more useful than it sounds.

**RGB565 byte layout** (datasheet §8.2.22 parameter table, 16 bpp row):

```
high byte:  R4 R3 R2 R1 R0 G5 G4 G3
low  byte:  G2 G1 G0 B4 B3 B2 B1 B0
```

Insert or drop **one byte** at position *k*, and every pixel after *k* is
assembled as `(low byte of intended pixel N, high byte of intended pixel N+1)`.
The reconstructed pixel takes its red and upper-green from pixel N's **blue**
field, and its blue from pixel N+1's **red** field.

**Consequences, in order of usefulness:**

1. **A one-byte shift is completely invisible in a uniform fill.** In
   `fillScreen(TFT_WHITE)` every byte is `0xFF`; shifted or not, every
   reconstructed pixel is still `0xFFFF`. Same for `TFT_BLACK` and `0x0000`.
   **This kills "a dropped byte during `fillScreen` produced the hatching."**
   It cannot have.
2. **It does not accumulate across operations.** `TFT_eSPI::setWindow`
   (`TFT_eSPI.cpp:3360-3364`) forces `addr_row = addr_col = 0xFFFF`, so CASET,
   PASET and RAMWR are re-issued before **every** drawing call. RAMWR then
   resets the column and page registers (quote in §4.1). A shift is therefore
   confined to the single operation in which it occurred and self-heals at the
   next one — which is genuinely good news about this codebase.
3. **On real content it produces strong false colour, not grey noise.** At a
   black↔white boundary the shifted stream yields pixels like `0x00FF` (pure
   blue) and `0xFF00` (red + green, i.e. yellow). **This is a checkable
   prediction against the photograph:** on a UI that is deliberately monochrome
   (`C_BG`/`C_FG`/`C_MUTED` are white/black/grey throughout), *any* saturated
   blue, yellow or cyan in the corrupted region is a signature of a byte/bit
   shift. Grey and black-and-white hatching is not, and points elsewhere.
4. **A fixed shift gives vertical stripes; only an accumulating one gives
   diagonals.** A line is 320 px = 640 bytes — even — so a constant one-byte
   shift has identical phase on every line, producing **vertical** artefacts.
   Diagonals require the shift to *grow* line by line. There is a plausible
   source for exactly that: `pushBlock` for ESP32
   (`Processors/TFT_eSPI_ESP32.c:255-289`) sets `*_spi_mosi_dlen = 511`, i.e.
   **512-bit (64-byte, 32-pixel) bursts**, and 320 ÷ 32 = **10 bursts per line**,
   2,400 per full frame. Between bursts the CPU spins on
   `while (*_spi_cmd & SPI_USR);` — **SCK idles while CS is still asserted low**.
   Each of those 2,400 windows is an opportunity for a noise pulse on SCK to be
   counted as a real clock edge and insert a bit. One inserted bit per burst
   would advance the phase by 10 bits per line = 0.625 px per line — a hatch
   sloping about 1 px across per 1.6 px down. That is a diagonal.

### 4.4 Where that leaves symptom (B)

Run the elimination:

- **Not a desynchronised `fillScreen`** — §4.3 item 1: mathematically invisible.
- **Not desynchronised glyph/text** — the hatched region is ~40% of 76,800 px
  ≈ **30,700 px**. The entire glyph plus text content of `drawArrived()` is only
  ~16,000 px, and it is drawn on the *right* half (`drawManeuver` at
  `GLYPH_FAR_X + 8`, text at x = 108, `display.cpp:635-648`). There is not enough
  drawn content in that frame to fill the hatched area.
- **Therefore the hatched region is area the fill did not cover**, showing what
  was already in GRAM.

What could already be in GRAM?

- **The previous screen** — a NAV screen with a 75 px numeral, an arrow glyph and
  a footer. Read out under a different address mapping than it was written with,
  that becomes regular oblique combing. Plausible as "diagonal hatching".
- **Random data**, if the panel had momentarily lost *power*. Datasheet
  §8.2.22, RAMWR default table, p.114, verbatim:

  > Power On Sequence — **"Contents of memory is set randomly"**
  > SW Reset — "Contents of memory is not cleared"
  > HW Reset — "Contents of memory is not cleared"

  **Random RGB565 aliased against the panel's RGB sub-pixel stripe photographs
  precisely as fine diagonal hatching.** This is the single best match for the
  described appearance — and note it requires a genuine **power** interruption to
  the panel, since neither a hardware nor a software reset clears GRAM.

> **★ Finding.** If the hatching is fine-grained *random* noise rather than a
> recognisable smear of the previous nav screen, then **the panel lost power
> momentarily** — which is a supply fault (H3/H4), not an SPI fault, and moves
> decoupling and the power path to the top of the fix list. If instead the
> hatching resolves into distorted remnants of the previous screen, the panel
> kept power and the fill was truncated — which is H1.
>
> **These two look different at arm's length and identical in a phone photo
> taken at night. Zoom into the photograph.** This is the highest-information,
> zero-cost observation available.

### 4.5 Answering the question as posed

> *Does that suggest a partial-window write (CASET/PASET corruption) rather than
> MADCTL alone?*

**Yes — MADCTL alone is definitively insufficient.** With MV set, any MADCTL
value still addresses the full 320 × 240 and `fillScreen` still covers the whole
panel; there would be no unpainted band at all. A second effect is required, and
the two candidate mechanisms are:

- **RAMWR abort** — datasheet: "Sending any other command can stop frame Write."
  A single stray command byte (H1) both rewrites a register and truncates the
  fill. **One event, both symptoms.**
- **CASET clipping** — if MV was cleared, `CASET(0,319)` exceeds `00EFh` and
  "data of out of range will be ignored", clipping the window to 240 columns.
  The library then pushes 76,800 px into a 240 × 240 = 57,600 px window; the
  surplus 19,200 px wrap to the window start, and **pages 240…319 — exactly
  25% of the panel's long axis — are never written**. A 25% strip eyeballed
  from a photograph is not far from the reported "~40%".

> *Could a single dropped or inserted byte during a `fillScreen` desynchronise
> the pixel stream and produce exactly this?*

**No.** §4.3 item 1 — a uniform stream is shift-invariant. A byte slip during
`fillScreen` is, uniquely, the one place in this firmware where it has **zero**
visible effect. It would matter during the glyph and text pushes, where it would
produce saturated false colour (§4.3 item 3) — worth looking for in the photo,
but it cannot account for a 30,000-pixel block.

---

## 5. Mitigations that work without MISO, ranked by effectiveness × cheapness

### 5.0 The framing that changes the priorities

There are two separable problems:

- **P1 — the corruption happens** (rare, physical, hard to fix, hard to verify).
- **P2 — the corruption is permanent once it happens** (certain, in software,
  trivial to fix, verifiable in five minutes).

**P2 is the one that turned a sub-second glitch into a photograph.** Fixing P2
does not require knowing the cause at all, cannot make anything worse, and caps
the damage from *every* hypothesis in §3 simultaneously. It should be done first
even though it is not a "real" fix.

### 5.1 ★ #1 — Periodic MADCTL re-assert **paired with a forced repaint**

**The question as asked:** *a `setRotation()` call sends only a command + one
byte; it writes no pixels, so it should be visually free. Would this actually
recover the observed corruption?*

**Cost — confirmed free.** `setRotation(1)` on this driver emits exactly
`writecommand(0x36)` + `writedata(0x28)` (`ILI9341_Rotation.h`, case 1): **two
bytes, 16 bits, 593 ns at 27 MHz**, plus a few hundred ns of TFT_eSPI
transaction overhead. Against a 45.5 ms frame that is a **0.0013%** cost. The
datasheet is explicit that it is side-effect-free: *"This command makes no
change on the other driver status."* It is as close to literally free as a
mitigation gets.

**But on its own it would NOT have recovered the photographed screen.** §2.3:
MY/MX/MV are write-side only, so re-asserting MADCTL corrects the *next* write
and leaves the existing frame exactly as it is. And on ARRIVED, **there is no
next write** — `displayRender` returns at `display.cpp:1168` and nothing
repaints for the full 30 s `ARRIVAL_DWELL_MS`. The rider would have stared at
the identical corrupt frame with a perfectly correct MADCTL behind it.

> **Verdict: necessary but not sufficient. `setRotation()` + `displayInvalidate()`
> is the actual mitigation.** The invalidate is what makes it work; the
> `setRotation` is what stops the repaint from being drawn wrong too.

**How often is sensible.** Two complementary cadences:

| Where | Cadence | Cost | Rationale |
|---|---|---|---|
| **Before every full-screen chrome repaint** | event-driven | 593 ns | Guarantees every full repaint starts from known register state. Unconditionally free. Do this. |
| **Periodic re-assert + invalidate on static screens** | every **5 s** | 45.5 ms fill + ~10 ms content ≈ **1.1% duty** | Converts *permanent* corruption into *≤5 s* corruption on ARRIVED / IDLE / banner screens. |

**Do not** make the periodic path unconditional on nav screens — they already
self-heal (§6.2) and a forced full repaint there is a visible flash.

**The one real cost to weigh:** a periodic full repaint of ARRIVED does a
`fillScreen` that briefly erases the glyph and text, so it *is* a ~10 ms visible
flicker every 5 s. Two ways out, both cheap:

- Repaint **without** the fill — redraw the glyph box and re-`drawString` over
  itself. `setTextColor(C_FG, C_BG)` is already set (`display.cpp:637`), so text
  paints its own opaque background and overdrawing identical content is
  invisible. ~16,000 px ≈ **10 ms**, no flash.
- Or accept the flash but stretch the period to 10–15 s. On a screen that is up
  for 30 s that still guarantees at least two chances to self-correct.

**Recommendation: re-assert MADCTL before every chrome repaint (free,
unconditional), and add a fill-free 5 s refresh for `UI_ARRIVED` and `UI_IDLE`.**

**Worth extending slightly.** Re-asserting the full non-destructive register set
costs barely more than MADCTL alone and covers more failure modes:

| Command | Bytes | Guards against |
|---|---|---|
| `0x36` MADCTL = `0x28` | 2 | the observed mirroring |
| `0x3A` COLMOD = `0x55` | 2 | 16 bpp lost → every pixel misparsed |
| `0x20` INVOFF (or `0x21`) | 1 | spurious inversion (§1.2 option 2) |
| `0x11` SLPOUT / `0x29` DISPON | 2 | the *previously observed* blank-white fault (`display.cpp:800-805`) |

**Under 10 bytes, ~3 µs, no pixels.** Note SLPOUT carries a datasheet timing
obligation (§15.4 note 7: 120 ms before a further SLPOUT), so if included it must
be rate-limited — which the 5 s cadence already does.

### 5.2 #2 — Lower the SPI frequency

**What it costs, exactly.** 320 × 240 × 16 bit = 1,228,800 bits per frame:

| SPI clock | Full frame | vs 27 MHz | Distance sprite (208×80, 16,640 px) | Bit cell | Edge (15 ns spec) as % of cell |
|---|---|---|---|---|---|
| 40 MHz | 30.7 ms | −33% | 6.7 ms | 25.0 ns | 60% |
| **27 MHz (current)** | **45.5 ms** | — | **9.9 ms** | **37.0 ns** | **41%** |
| 20 MHz | 61.4 ms | **+35%** | 13.3 ms | 50.0 ns | 30% |
| 13.5 MHz | 91.0 ms | +100% | 19.7 ms | 74.1 ns | 20% |
| 10 MHz (**datasheet max**) | 122.9 ms | +170% | 26.6 ms | 100.0 ns | 15% |

**What that actually costs this project today.** Full repaints happen on screen
*changes*, which are rare. The recurring cost is the distance sprite, pushed at
most once per distance change — call it 1 Hz. Going 27 → 20 MHz moves that from
**9.9 ms to 13.3 ms**, i.e. from 1.0% to 1.3% of a second. **Invisible.** Screen
transitions go from 45 ms to 61 ms, which is at the edge of perceptible and only
happens on a screen change.

The real cost is **future**: `SPEC_MOVING_MAP.md` implies animated content, and
HARDWARE.md line 100 already argues for going *up* to 40 MHz once soldered.

> **Recommendation: drop to 20 MHz now, as insurance, while the build is on a
> breadboard.** It is a one-line change in the live `User_Setup.h` (note the
> sketchbook trap: `C:\dev\Arduino\libraries\TFT_eSPI\User_Setup.h`, HARDWARE.md
> line 150). Revisit after soldering, and re-test rather than assume — exactly as
> HARDWARE.md line 93 already says.

**Honest caveat: this is unfalsifiable in practice.** At an inferred BER of
~10⁻⁹ (§3.2), you would need months of riding to tell 20 MHz from 27 MHz. Lower
it because the margin argument is sound, not because you will be able to prove it
worked.

### 5.3 ★ #3 — Decoupling capacitors (the best rupees-per-risk on the list)

Nothing in the repo mentions a decoupling cap. HARDWARE.md line 47 records
**3.18 V at the `3V` pin with the backlight lit** — a 4% droop before any
dynamic load.

| Part | Where | Cost | Why |
|---|---|---|---|
| **100 nF ceramic (X7R)** | directly across the display module's VCC↔GND pins, leads as short as physically possible | ~₹2 | Supplies the high-frequency transient current the controller's I/O draws on every SCK edge. The MB102 rail cannot; it is metres of inductance away electrically. |
| **10 µF electrolytic or tantalum** | on the breadboard rail next to the display header | ~₹3 | Bulk reservoir for the ~60–100 mA backlight and BLE TX bursts. |
| **100 nF + 10 µF** | at the ESP32's 3V3 pin | ~₹5 | Same argument, driver end. |

**The dynamic case.** ESP32 BLE advertising and connection events draw burst
currents in the ~100–130 mA region. An MB102 rail presents roughly 10–20 nH per
inch of loop inductance with no bulk capacitance near the load, and the MB102's
own power module is not a precision part. Every millivolt of rail sag narrows
V<sub>IH</sub>/V<sub>IL</sub> at **both ends of the bus at once** — on a link
already running at 2.7× the specified clock with no guard band.

> **~₹10 and fifteen minutes. Do this before anything else physical.** It
> attacks H3 and H4 directly and improves the margin that H1 and H2 depend on.

### 5.4 #4 — Re-wire MISO — but the watchdog as written would not have caught this

**The wiring.** One jumper: LOLIN32 **GPIO 19** → display **SDO**. It is already
declared (`User_Setup.h:19`) and already in the HARDWARE.md pin table (line 33);
it was deliberately removed (`display.cpp:829`). The probe at
`display.cpp:1076-1079` auto-detects and arms, so **this really is a pure wiring
fix with zero firmware change required to re-enable the watchdog.**

> **★ But the existing watchdog is blind to this specific fault.** It reads
> **RDDPM (0x0A)** and checks `DISON | SLPOUT` (`display.cpp:817-819, 1258-1260`).
> **MADCTL corruption does not change RDDPM.** A panel that is on, awake, and
> rendering everything 180° passes the check perfectly. Re-wiring MISO on its
> own would have changed nothing about the photographed screen.

**The fix that makes MISO worth the wire:** also read **RDMADCTL (`0x0B`)** —
already defined as `ILI9341_RDMADCTL` in `TFT_Drivers/ILI9341_Defines.h:87` —
and compare it against the expected `0x28`. On mismatch: re-assert MADCTL and
`displayInvalidate()`. That is a genuine detector for the observed fault, and it
also gives you a **counter** — the thing this investigation is most missing.

**Caveats, and they matter:**

- ILI9341 register reads over SPI need the dummy-clock handling in
  `readcommand8`, and are notoriously unreliable on cheap modules — which is
  exactly why the auto-detect exists. The probe may still disarm.
- Reads are the reason `SPI_READ_FREQUENCY` is 20 MHz (`User_Setup.h:45`) and
  why HARDWARE.md line 97 calls 27 MHz "TFT_eSPI's documented ceiling for
  *reading* pixels". Reads are the *least* tolerant traffic on the bus.
- Every 2 s poll is one more bus transaction with CS toggling — a small increase
  in exposure, though negligible against 45 ms frames.
- Do not re-arm the old three-strike `tft.init()` recovery without also fixing
  the false-positive story documented at `display.cpp:832-835`. A MADCTL
  mismatch should trigger a **MADCTL re-write + invalidate**, not a full
  `tft.init()`; full re-init is a visible flash and is reserved for the
  blank-panel fault.

### 5.5 #5 — Series resistors on SCK and MOSI

**22–33 Ω in series, at the ESP32 end, as close to the pin as possible.**
Cost ~₹5.

**Why it works, numerically.** The ESP32 drives ~1–2 ns edges. Signal content
therefore extends to roughly 0.35/1.5 ns ≈ **230 MHz**. A quarter wavelength at
230 MHz in wire is on the order of **250 mm** — and the dupont jumpers on this
build are 150–200 mm. **The wires are electrically long for the edge rate even
though they are trivially short for the 27 MHz fundamental.** That is the
mechanism behind ringing, overshoot and crosstalk into D/CX — i.e. behind H1.

33 Ω into the panel input's ~50–100 pF gives an RC of **1.7–3.3 ns**, which
slows the edge enough to kill overshoot while consuming under 10% of the 37 ns
bit cell. This is the standard source-termination fix and it is nearly free.

> **★ Correct a possible misreading of HARDWARE.md while doing this.**
> HARDWARE.md line 40 says *"No series resistors"* — but read line 41: that note
> is rejecting the **vendor's 10 kΩ level-shifting advice for a 5 V Arduino**,
> which is a completely different thing. **10 kΩ for level shifting: still wrong.
> 33 Ω for source termination: right, and orthogonal.** As written, that line
> could steer a future session away from the correct fix. Worth amending.

### 5.6 #6 — Pull-ups on CS and RESET

| Signal | Pin | Fix | Cost | Why |
|---|---|---|---|---|
| **CS** | GPIO 15 | 10 kΩ to 3V3 | ~₹1 | GPIO 15 is an ESP32 strapping pin with an internal pull-**up** at reset, so it is biased correctly at boot — but during a **brown-out** the pin tri-states. **A floating-low CS while the ESP32 reboots and the bus carries garbage is one of the cleanest ways a panel ends up with a wrong MADCTL.** Directly guards H3. |
| **RESET** | GPIO 16 | 10 kΩ to 3V3 | ~₹1 | Driven by `tft.init()`, so not floating in normal operation — but undefined while the ESP32 boots or browns out. §3.5 rules a reset *out* for this event (a reset blanks the display), so this is hygiene, not a fix. Confirm it is actually wired first — HARDWARE.md line 29 flags GPIO 16 as the classic trap. |
| **D/CX** | GPIO 2 | leave alone; **route away from SCK** | free | GPIO 2 is a strapping pin that must be low at boot, so do not pull it up. The useful action is physical: keep the D/CX jumper non-adjacent to SCK on the breadboard, and ideally put a ground wire between them. This is the direct countermeasure to H1. |

### 5.7 #7 — Shorter leads / leave the breadboard

The real fix, already planned as Stage 11 (HARDWARE.md line 70). Every item
above is a way to survive until then. Halving the lead length roughly halves the
inductance and the crosstalk coupling, and it removes the MB102's spring
contacts — which are a genuine intermittent-connection risk on a vibrating
motorcycle in a way that has nothing to do with SPI at all.

### 5.8 Ranked summary

| Rank | Mitigation | Effectiveness | Cost | Prevents or contains? |
|---|---|---|---|---|
| **1** | Re-assert MADCTL **+ `displayInvalidate()`** on a 5 s cadence for static screens | ★★★★★ caps every hypothesis | ~10 lines, 1.1% duty | **contains** |
| **2** | 100 nF + 10 µF decoupling at the panel and the ESP32 | ★★★★ attacks H3/H4, helps H1/H2 | ~₹10, 15 min | **prevents** |
| **3** | Log `esp_reset_reason()` + boot counter + uptime | ★★★★ as *diagnosis* | free | neither — it tells you which fix worked |
| **4** | MISO wire **+ watch RDMADCTL 0x0B, not just RDDPM 0x0A** | ★★★★ true detection | 1 wire, ~15 lines | **contains + measures** |
| **5** | SPI 27 → 20 MHz | ★★★ margin, unprovable | 1 line, +35% frame time | **prevents** |
| **6** | 33 Ω series on SCK/MOSI; 10 kΩ pull-up on CS; route D/CX away from SCK | ★★★ attacks H1 | ~₹10, a rewire session | **prevents** |
| **7** | Solder to perfboard, short leads | ★★★★★ | Stage 11 | **prevents** |

---

## 6. Is the ARRIVED screen special? Yes — but not electrically

### 6.1 ★ It is the only screen that paints once and then never repaints

`display.cpp:1162-1169`:

```cpp
  if (fullScreenAlert) {
    if (changed && idleKey) drawBand(s, band, scr);
    lastIdleKey = idleKey;
    return;
  }
```

`fullScreenAlert` is true for `UI_IDLE` and `UI_ARRIVED` (`display.cpp:1126`).
`drawChrome` runs only when `changed` (`display.cpp:1137`), and `changed`
requires `!chromeValid || scr != lastScreen` — plus, for ARRIVED, only an alert
identity change (`display.cpp:1135`). Nothing else can set it.

`UI_IDLE` at least has an escape hatch: `display.cpp:1106-1110` adds a clock and
battery change key, precisely because — as the comment says — *"nothing else
would ever repaint it."* **`UI_ARRIVED` has no such key.** There is no clock, no
distance, no battery, no geometry. It draws once and sits there for the full
`ARRIVAL_DWELL_MS = 30000` (`nav_types.h:72`).

> **This, not any electrical property, is why the fault was seen here.** On a
> NAV screen, `pushDistance` repaints a 208 × 80 sprite on every distance change
> (`display.cpp:1190-1197`), and `drawNavGlyph` repaints on geometry updates
> (`display.cpp:1157-1160`). Corruption there is **overwritten within about a
> second** and reads as a flicker, not a fault.

**The uncomfortable corollary: this may not be the first occurrence.** It may
simply be the first one that lasted long enough to be noticed, let alone
photographed. Every prior occurrence on a nav screen would have been a
sub-second flicker on a bumpy road at night — indistinguishable from nothing.
**The event rate is therefore not known to be "once", and any estimate of MTBF
from this single sighting is worthless.**

### 6.2 Is `drawArrived` electrically harder than other screens?

Somewhat, but not decisively:

| Screen | `fillScreen`? | Approx. pixels in one paint | Approx. CS-low SPI time |
|---|---|---|---|
| `drawArrived` | yes | ~93,000 | **~55 ms** |
| `drawIdle` | yes | ~80,000 | ~48 ms |
| `drawBanner` (DISCONNECTED / STALE / REROUTING) | yes | ~80,000 | ~48 ms |
| NAV chrome repaint | yes | ~90,000 | ~54 ms |
| NAV distance sprite (the common case) | no | 16,640 | ~9.9 ms |

`drawArrived` is at the top, but only marginally — it is not an outlier. What it
does have is the **largest single uninterrupted burst** (`fillScreen` alone:
153,600 bytes, 2,400 consecutive 512-bit FIFO bursts, CS held low for 45.5 ms
with 2,400 SCK-idle windows in between, §4.3 item 4). But `drawIdle` and every
banner do essentially the same thing.

### 6.3 Circumstantial factors that *are* specific to arrival

These are speculative but cheap to check and worth listing:

1. **Longest uptime.** ARRIVED is by definition reached at the end of the ride —
   maximum accumulated thermal soak on the LDO and the ESP32, maximum time for
   a vibrating dupont contact to work loose. HARDWARE.md's whole enclosure
   section is about a thermal environment that is already known to be hostile.
2. **★ The power source at the moment of arrival.** Arriving means *stopping*.
   If the device is on the bike's 12 V accessory rail, engine-off or idle drops
   the supply. If it is on a USB power bank, many power banks **cut output or
   renegotiate** when load drops — and load *does* drop at arrival, because
   navigation traffic stops. **A supply transient correlated with the act of
   arriving is a real and under-considered possibility**, and it would make the
   ARRIVED screen genuinely special rather than coincidentally so.
   **What was it powered from on this ride? This is worth answering.**
3. **BLE traffic pattern changes at arrival.** Maps drops the ongoing
   notification within a few seconds of arrival (`display.cpp:630-631`), so
   packets stop, `nudgeIfQuiet()` starts polling every 2 s
   (`navigator.ino:38-52`), and the connection may go idle or drop — all of which
   change the radio's current draw profile at exactly the moment `drawArrived`
   is pushing its 45 ms fill.

> **Answer to the question as posed:** the ARRIVED screen is **not obviously more
> likely to be corrupted** than IDLE or any banner — its paint is only ~15%
> larger than theirs. It **is** overwhelmingly more likely to be *seen*
> corrupted, because it is the only screen with no repaint path at all. Item 2
> above is the one candidate for genuine electrical specialness, and it is
> answerable for free.

---

## 7. Verified / inferred / unknown

### 7.1 Verified — checked against the datasheet, the library source, or this repo

| Fact | Source |
|---|---|
| Runtime MADCTL on this build is `0x28` (MV \| BGR) | `ILI9341_Rotation.h` case 1; `ILI9341_Defines.h:56-72`; `display.cpp:41` |
| MADCTL is written **once per boot** and never again at runtime | `display.cpp:1069-1070`; recovery path at 1272-1273 is unreachable via 1252 |
| MY/MX/MV control **MCU-to-memory write/read direction** — not the stored image | datasheet §8.2.29 p.127, verbatim |
| MADCTL "makes no change on the other driver status" — safe to re-assert | datasheet §8.2.29 p.127, verbatim |
| MADCTL reset default is `00h` | datasheet §8.2.29 p.127 |
| `0xE8` = MY\|MX\|MV\|BGR = TFT_eSPI **rotation 3** = 180° of rotation 1 | `ILI9341_Rotation.h` case 3 |
| CASET clips at `00EFh` when MV=0 and `013Fh` when MV=1; **"data of out of range will be ignored"** | datasheet §8.2.20 p.110, Note 1, verbatim |
| RAMWR resets the column/page registers, and **"Sending any other command can stop frame Write"** | datasheet §8.2.22 p.114, verbatim |
| GRAM is **random on power-on** but **not cleared** by SW or HW reset | datasheet §8.2.22 p.114 default table, verbatim |
| A hardware reset **blanks the display** and sets MADCTL to `00h` | datasheet §15.4 p.230 Note 3 |
| RESX rejects pulses **< 5 µs**; resets on **> 10 µs** | datasheet §15.4 p.230 Note 2 |
| **Datasheet max SPI write clock is 10 MHz** (`twc` min 100 ns); this build runs **27 MHz = 2.7× spec** | datasheet §18.3.4 p.243; `User_Setup.h:44` |
| The panel watchdog is **disabled at runtime** on this build | `display.cpp:847`, `1252`; the boot probe at 1076-1079 |
| The watchdog checks **RDDPM `0x0A`** only — which **cannot detect MADCTL corruption** | `display.cpp:817-819`, `1258-1260` |
| **`UI_ARRIVED` has no repaint path**; it draws once and returns for 30 s | `display.cpp:1126`, `1137`, `1162-1169`; `nav_types.h:72` |
| TFT_eSPI re-sends CASET/PASET/RAMWR before **every** drawing op, so shifts do not accumulate across ops | `TFT_eSPI.cpp:3360-3364` |
| `pushBlock` on ESP32 uses **512-bit (32-pixel) FIFO bursts**, CS held low, SCK idle between them | `Processors/TFT_eSPI_ESP32.c:255-289`; `TFT_eSPI_ESP32.h:204-239` |
| Full frame at 27 MHz = **45.5 ms**; the panel rail measured **3.18 V** | arithmetic; HARDWARE.md lines 47, 106 |
| Night mode defaults **off** and is only set by an optional BLE CONFIG tail byte | `nav_types.h:115`; `ble.cpp:259-272`; `navigator.ino:94` |
| The panel has **previously** lost its configuration mid-run, recovering only on a power cycle | `display.cpp:797-809`; HARDWARE.md |

### 7.2 Inferred — reasoned, consistent with the evidence, not demonstrated

- **The observed mirroring is `MADCTL = 0xE8`.** Strong inference from symptom
  (A) plus the rotation table. **Not confirmed** — `0xC8` and `0x08` are not
  excluded by a verbal description of the photo (§4.2).
- **The hatched band is GRAM the fill did not cover**, not corrupted fill data.
  Follows from the shift-invariance of a uniform stream (§4.3) and from the
  hatched area being roughly twice the total drawn content of the frame.
- **At least two distinct corruptions occurred**, or the band's orientation has
  been misread. Follows from the MV=1 / MV=0 contradiction in §4.2.
- **The bit error rate is around 10⁻⁹–10⁻¹⁰**, from one event against ~1.5 Mbit
  per full paint. Order-of-magnitude only; the true event count is unknown
  (§6.1), so this could be off by orders of magnitude in the *pessimistic*
  direction.
- **A stray command byte (H1) is the most economical single cause**, because the
  datasheet's "any other command can stop frame Write" makes one glitch produce
  both a register change and a truncated fill.
- **Marginal supply is the enabling condition** for whichever SPI mechanism
  applies: 3.18 V measured, no decoupling anywhere in the design, BLE bursts.

### 7.3 Unknown — and this is the honest majority of it

- **What the photograph actually shows.** Band orientation (H/V/oblique), which
  bezel edge it touches, its stripe period, whether the region contains
  saturated colour, whether the letters are 180°-rotated or mirror-imaged, and
  whether the destination-name line rendered at all. **Every one of these is
  recoverable from the existing image at zero cost and each one discriminates.**
- **Whether the ESP32 rebooted.** Nothing logs it. This is the single largest
  hole and the cheapest to close.
- **Whether the panel lost power.** Distinguishable from the GRAM appearance
  (§4.4) and from a reboot log.
- **What the device was powered from** on that ride (§6.3 item 2).
- **Whether `night=1` had been configured** (§1.2).
- **The true event rate.** §6.1 — prior occurrences on nav screens would have
  been invisible.
- **Ambient conditions**: temperature, vibration level, whether the unit was
  jostled or the breadboard bumped at the moment of arrival.
- **Whether this reproduces at all.** It has not been reproduced.

> **What one observation buys you: almost nothing.** It establishes that the
> failure mode exists and is not the previously-documented blank-white fault. It
> does not establish frequency, trigger, or mechanism. **Do not spend money or a
> rewire session on the strength of this document alone — spend twenty minutes
> on §8.0 first, because two of the four items there are free and one of them
> can be done without leaving the desk.**

---

## 8. Ordered action list

### 8.0 ★ First: four observations, before changing anything

These cost nothing and they collapse most of the hypothesis space.

1. **Re-examine the photograph. Zoom in.** Answer:
   - Does the band touch the **left/right** bezel edge (vertical, full height) or
     the **top/bottom** (horizontal, full width)? → §4.2. Vertical ⇒ MV was 0
     during the fill; horizontal ⇒ a truncated write with MV=1.
   - Are the stripes **fine random noise** (⇒ the panel lost **power**, GRAM
     re-randomised, §4.4) or **recognisable smeared remnants of the nav screen**
     (⇒ the panel kept power, the fill was truncated)?
   - Is there any **saturated blue / yellow / cyan** anywhere? The UI is
     monochrome by design, so false colour ⇒ a byte/bit shift in a content push
     (§4.3 item 3).
   - Is the word **180°-rotated** (running along the long axis) or
     **90°-rotated** (running along the short axis)? → decides `0xE8` vs `0xC8`.
2. **★ Write the MADCTL forensics sketch** — the decisive test, and it is the
   best twenty minutes available. A standalone sketch that renders the ARRIVED
   layout, then writes each candidate MADCTL raw (`0x28, 0x68, 0xA8, 0xE8,
   0x08, 0xC8, 0x00`) and repaints, photographing each. **Compare against the
   ride photo and read the answer off directly.** This converts §2.4 from
   inference to fact. Costs nothing, risks nothing, and every later decision
   depends on it. *(Remember HARDWARE.md line 133: upload through the Arduino
   IDE, and do not open the COM port from a script.)*
3. **Recall what the device was powered from** on that ride, and whether the
   supply could have changed at the moment of arrival (§6.3 item 2).
4. **Check whether `night=1` was ever sent** by the phone/navsim on that ride
   (§1.2). If it was, INVON joins the suspect list and the diagnosis shifts.

### 8.1 Firmware — cheap, now, in this order

| # | Change | Where | Why |
|---|---|---|---|
| 1 | **Log `esp_reset_reason()` and a boot counter** (RTC-retained), plus uptime at every screen transition | `navigator.ino` `setup()` | Closes the largest evidence gap in §7.3. Free. **Do this first** — it decides between H3 and everything else on the next occurrence. |
| 2 | **Re-assert MADCTL immediately before every full chrome repaint** | `drawChrome()` entry, `display.cpp:680` | 593 ns, unconditional, guarantees each repaint starts from known state. |
| 3 | **Add a static-screen refresh**: if `scr` is `UI_ARRIVED` or `UI_IDLE` and nothing has repainted for 5 s, re-assert MADCTL and force a repaint | `displayRender`, near `display.cpp:1165` | ★ The one change that would have prevented the photographed outcome regardless of cause. Prefer the fill-free variant (§5.1) to avoid a 5 s flicker. |
| 4 | **Extend the re-assert to COLMOD `0x3A`=`0x55` and INVOFF `0x20`** | alongside #2 | Under 10 bytes total; covers two more silent-corruption modes. |
| 5 | **SPI 27 → 20 MHz** | live `User_Setup.h` (**`C:\dev\Arduino\libraries\TFT_eSPI\User_Setup.h`** — HARDWARE.md line 150) and the repo reference copy | +35% frame time, currently imperceptible. Revert after soldering, with a retest. |
| 6 | **Instrument, do not just fix**: count and log every time #3 fires and (once MISO exists) every RDMADCTL mismatch | `display.cpp` | Turns "seen once" into a measured rate. Without this, no later fix can be shown to have worked. |

**Verification for #3 without waiting for a real fault:** add a debug serial
command that deliberately writes `MADCTL = 0xE8` at runtime, and confirm the
screen self-corrects within 5 s. `demo.cpp` already has a serial command
surface to hang this off.

### 8.2 Wiring — before the case is built

In order. Items 1–2 are worth doing on the breadboard today; 3–5 belong to the
Stage 11 soldering session.

| # | Change | Cost | Rationale |
|---|---|---|---|
| 1 | **100 nF X7R across the display module's VCC/GND, shortest possible leads; 10 µF bulk on the rail beside it; 100 nF + 10 µF at the ESP32 3V3** | ~₹10 | §5.3. Highest value per rupee on the list. Do it now, on the breadboard. |
| 2 | **Re-route the D/CX jumper away from SCK**; if possible run a ground jumper between them | free | §5.6. Direct countermeasure to H1, the top-ranked hypothesis. |
| 3 | **MISO: GPIO 19 → SDO** — and change the watchdog to check **RDMADCTL `0x0B` against `0x28`**, not just RDDPM `0x0A` | 1 wire | §5.4. The wire alone re-arms a watchdog that **cannot see this fault**; the register change is what makes it worth doing. |
| 4 | **33 Ω series on SCK and MOSI**, at the ESP32 end | ~₹5 | §5.5. Source termination for ~230 MHz edge content on 150–200 mm wires. |
| 5 | **10 kΩ pull-up on CS (GPIO 15) to 3V3**; confirm RESET (GPIO 16) is genuinely wired and add 10 kΩ to 3V3 | ~₹2 | §5.6. Guards the brown-out window when the ESP32 tri-states its pins. |
| 6 | **Solder to perfboard, shortest practical leads** | Stage 11 | §5.7. The actual fix. Everything above is scaffolding until then. |

### 8.3 Documentation follow-ups

- **HARDWARE.md line 40, "No series resistors."** Amend to make clear it rejects
  the vendor's **10 kΩ level-shifting** advice for 5 V Arduinos, and does **not**
  rule out **33 Ω source-termination** resistors, which are appropriate here.
  As written it could steer a future session away from the right fix (§5.5).
- **HARDWARE.md line 93**, on raising the clock to 40 MHz after soldering: add
  the datasheet figure — **`twc` min 100 ns = 10 MHz specified maximum**. Both 27
  and 40 MHz are overclocks; 40 MHz would be 4× spec. That does not mean don't
  do it, but it should be a decision made with the number in view.
- **`display.cpp:811`** says *"MISO is wired to GPIO 19"* while
  `display.cpp:829` says it *"is not wired — it was removed deliberately."*
  The first comment is stale and contradicts the second. Fix it — a future
  session reading only the first will draw the wrong conclusion.
- **Record this bug's outcome here** when the next occurrence (or non-occurrence
  over N rides) is observed. This file's value is as a running record, not a
  one-shot analysis.

---

## 9. References

**ILI9341 datasheet** (ILI Technology, v1.11) — sections cited:

- §8.2.20 **CASET (2Ah)**, p.110 — out-of-range column clipping, MV-dependent limits
- §8.2.22 **RAMWR (2Ch)**, p.114 — address counter reset, "any other command can stop frame Write", GRAM default contents
- §8.2.29 **MADCTL (36h)**, p.127 — MY/MX/MV/ML/BGR/MH definitions, reset default
- §15.4 **Reset Timing**, p.230 — tRW 10 µs, spike rejection, display blanks during reset
- §18.3.4 **Display Serial Interface Timing (4-line SPI)**, p.243 — twc min 100 ns

Mirrors: <https://cdn-shop.adafruit.com/datasheets/ILI9341.pdf> ·
<https://newhavendisplay.com/content/app_notes/ILI9341.pdf>

**TFT_eSPI** v2.5.43 (Bodmer) — <https://github.com/Bodmer/TFT_eSPI>

- `TFT_Drivers/ILI9341_Rotation.h` — the MADCTL value per rotation
- `TFT_Drivers/ILI9341_Defines.h` — `TFT_MAD_*` masks, `ILI9341_RDMADCTL 0x0B`
- `TFT_eSPI.cpp:3360` `setWindow` — per-operation CASET/PASET/RAMWR re-issue
- `Processors/TFT_eSPI_ESP32.c:255` `pushBlock` — 512-bit FIFO bursts
- `Processors/TFT_eSPI_ESP32.h:204` — `CS_L`/`CS_H` macros
- Issue 1172, the `ILI9341_2_DRIVER` alternative init this panel needs —
  <https://github.com/Bodmer/TFT_eSPI/issues/1172>
- Library guidance on clock rates —
  <https://doc-tft-espi.readthedocs.io/hardware/ili9341/>

**This repo:**

- `docs/HARDWARE.md` — pin map, 3.18 V measurement, 27 MHz rationale, frame timings, sketchbook trap
- `firmware/navigator/display.cpp` — `drawArrived` 632, `drawChrome` 680, panel watchdog 795-847, `displayBegin` 1068, `displayRender` 1088, `displaySetNight` 1200, `displayTick` 1250
- `firmware/navigator/User_Setup.h` — pins, `SPI_FREQUENCY 27000000`
- `firmware/navigator/nav_types.h:72` — `ARRIVAL_DWELL_MS`
- `firmware/navigator/navigator.ino:86` — the main loop

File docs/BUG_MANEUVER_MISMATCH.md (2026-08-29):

# BUG: handlebar showed CONTINUE while Maps' banner showed a right turn

Status: **investigation complete** (diagnostic only — no code changed).
Fixes are specified at the end and deliberately not applied.
Opened 29 Aug 2026. Route: Kochi, Jawahar Rd northbound toward Moulana Azad Rd.

## The observation

Rider reports the handlebar display showed "continue / go straight" while Google
Maps' own in-app banner showed a right-turn arrow, "450 m", "Moulana Azad Rd".
He took the correct turn only because he knew the road. He recalls turning
*left*; the screenshot says the next maneuver is a *right* onto Moulana Azad Rd.
The screenshot is the harder evidence.

Three things may disagree:
1. Maps' in-app banner
2. The notification our app parses
3. The physical turn

## Contents

- [0. What the wire byte must have been](#0-what-the-wire-byte-must-have-been)
- [1. Can the notification lag the banner?](#1-can-the-notification-lag-the-in-app-banner)
- [2. Can classify() return CONTINUE for a turn icon?](#2-can-maneuversclassify-return-continue-for-a-turn-icon)
- [3. Can the parser HOLD a stale maneuver?](#3-can-the-parser-hold-a-stale-maneuver)
- [4. Distance updating without maneuver](#4-is-there-a-path-where-distance-updates-but-maneuver-does-not)
- [5. The 15 s removal debounce and step boundaries](#5-does-the-15-s-removal-debounce-interact-badly-with-a-step-change)
- [6. Logging: what exists, what to add](#6-logging-what-exists-and-the-one-line-to-add)
- [7. Ranked conclusions](#7-ranked-conclusions)
- [Proposed fixes — not applied](#proposed-fixes--specified-deliberately-not-applied)

## Method and confidence labels

Every claim below is one of:

- **VERIFIED** — I read the code path, file and line cited.
- **INFERRED** — follows from verified code plus measured data in NAV_DATA.md,
  but the specific combination was not itself observed.
- **UNKNOWN** — no evidence either way in this repo. Named as such rather than
  guessed at.

Files read in full: `MapsParser.kt`, `Maneuvers.kt`, `NavListenerService.kt`,
`NavPacket.kt`; `LinkService.kt` and `BleLink.kt` for the nav path;
`firmware/navigator/ble.cpp`, `display.cpp`, `maneuvers.cpp`, `navigator.ino`
for what the wire byte becomes on the panel.

---

## 0. What the wire byte must have been

Before anything else, one deduction narrows the search sharply.

The rider reports a **straight-ahead arrow**, not a question mark.

- `Mv.UNKNOWN` is `0x00` and the firmware draws it as a **"?"**, not an arrow —
  `firmware/navigator/maneuvers.cpp:166-170` ("Never guess an arrow - say so
  instead"), and the `?` is drawn in font 4 precisely because it must be legible.
- `firmware/navigator/ble.cpp:152-176` (`handleNav`) copies the maneuver byte
  into `NavState` verbatim. There is no hold, no substitution, no "keep the last
  known" path. **VERIFIED.**
- `firmware/navigator/display.cpp:676-677` draws `s.maneuver` through
  `drawManeuver()` unless `geomValid()` — and the moving-map geometry is only
  ever populated by `demo.cpp` (`geomBegin`/`geomWay`/`geomPt` appear in
  `demo.cpp`, `geom.cpp`, `geom.h` and nowhere else), which is serial-triggered
  (`navigator.ino:91-92`) and cannot arm on a ride. **VERIFIED.**

**Conclusion: the byte on the wire was genuinely `0x01 Mv.CONTINUE`.** Every
explanation that ends in UNKNOWN — a null icon, a render failure, an unmatched
hash, the ambiguity guard firing — is therefore ruled out, because all of them
produce `0x00` and a "?" on the panel. This eliminates a large part of the
hypothesis space in one step.

---

## 1. Can the notification lag the in-app banner?

### What is measured

NAV_DATA.md contains **one** simultaneous comparison of Maps' own UI against the
notification, and it is decisive enough to be the centre of this whole
investigation. `docs/NAV_DATA.md:479-528`, captured from
`dumpsys notification --noredact` **"at a moment when Maps was rendering
'Then →' in its own UI"**, on a live route **on Moulana Azad Rd** — the same
road as the incident:

```
android.title                                   = "Head toward Moulana Azad Rd"
android.ongoingActivityNoti.primaryInfo         = "0 m"
android.ongoingActivityNoti.secondaryInfo       = "towards Moulana Azad Rd"
android.ongoingActivityNoti.nowbarSecondaryInfo = "towards Moulana Azad Rd"
android.ongoingActivityNoti.chipIcon            = BITMAP 135x135

PROBE-ICONS chip=CONTINUE second=CONTINUE nowbar=CONTINUE (all same)
```

So: **Maps drew a turn in its own UI while all three notification bitmaps
classified CONTINUE.** That is measured, not inferred.

### What that dump would have put on the handlebar

Trace the same extras through our parser:

| Field | Path | Result |
|---|---|---|
| maneuver | `MapsParser.kt:383` → `Maneuvers.classify` → `BY_HASH["c2a2c91"]` (`Maneuvers.kt:144`) | `Mv.CONTINUE` — straight arrow |
| distance | `MapsParser.kt:385-388`, `parseDistance` `MapsParser.kt:416-424`, `RE_DIST_M` `MapsParser.kt:103` | `"450 m"` → `450` |
| instruction | `chooseInstruction` `MapsParser.kt:468-471`: `nowbarSec` `"towards Moulana Azad Rd"` → `RE_TOWARDS` (`MapsParser.kt:77`) strips the connector → `"Moulana Azad Rd"`, 15 chars ≤ `GLANCE_CHARS` 20 → **returned immediately** | `"Moulana Azad Rd"` |

Panel: **[straight arrow] · 450 · "Moulana Azad Rd"**.
Banner: **↱ · 450 m · Moulana Azad Rd**.

**Identical in every field except the arrow.** That is the rider's report, and it
is reproducible from a dump already committed to this repository. **VERIFIED**
that this state exists and that our code renders it exactly this way;
**INFERRED** that it is what the rider actually saw.

### So: is it a lag?

Almost certainly **not**, and this matters for how it gets fixed.

- A lag would be bounded by Maps' ~1 Hz post rate (NAV_DATA.md:130) plus our own
  ~1.9 s worst case (section 4). At Kochi city speeds that is tens of metres, not
  **450**. A 450 m disagreement is roughly 35-50 s of riding. Nothing in the
  notification pipeline can hold a value that long while the distance keeps
  counting — the distance and the maneuver come out of the *same bundle*
  (`MapsParser.kt:213-220`), so a stale maneuver would arrive with a stale
  distance too. **VERIFIED** from the code structure.
- The measured dump gives a mechanism that needs no lag at all: at that instant
  the notification was describing a **"Head toward …" (depart) step**, whose
  chipIcon is the straight/depart glyph, while Maps' banner was already
  depicting the **maneuver that terminates that step** — the right turn onto
  Moulana Azad Rd.

**The root cause is semantic, not temporal: the banner depicts the maneuver at
the END of the current step; `chipIcon` (at least during a depart step) depicts
the travel action of the step itself.** NAV_DATA.md's own hash table names this
collision explicitly — `c2a2c91` is labelled **"CONTINUE / depart"**
(`NAV_DATA.md:89`), and `Maneuvers.kt:144` copies that comment forward. One hash,
two meanings, and we map both to a confident straight arrow.

### The part that is genuinely unknown

Whether this generalises beyond the depart step — i.e. whether `chipIcon` shows
the continue glyph for the whole of *any* long straight step while the banner
shows the terminating turn — is **UNKNOWN**. Evidence pulls both ways:
`TURN LEFT` and `TURN RIGHT` hashes were each seen on 5 rides
(`NAV_DATA.md:90-91`), so `chipIcon` certainly does show turns at some point in
the approach. Nothing in the docs records *at what distance* it switches.

That single unknown is what section 6's log line is designed to close, and it is
closeable in one ride.

**Verdict on question 1: "the notification lags its own banner" is ruled out as
the explanation. The weaker and better-supported claim — "the notification and
the banner do not always depict the same maneuver, and the depart step is a
measured instance" — stands, and is largely not our bug. Our bug is rendering it
as a confident straight arrow rather than as something the rider can read as
'not a junction call'.**

---

## 2. Can `Maneuvers.classify()` return CONTINUE for a turn icon?

Walking all three tiers of `Maneuvers.kt:196-227`.

### Tier 1 — resource entry name (`Maneuvers.kt:199-210`)

**Dead today. VERIFIED.** `resName` (`Maneuvers.kt:357-365`) returns null unless
`icon.type == TYPE_RESOURCE` (2), and NAV_DATA.md:509 records
`chipIcon = BITMAP 135x135`, i.e. type 1. Tier 1 cannot have produced this.

One latent hazard worth recording even so: `BY_NAME` (`Maneuvers.kt:86-123`) is
an **unanchored substring** scan taken first-hit, and the CONTINUE keywords sit
*above* the turn keywords —

```
"depart" to Mv.CONTINUE,      // Maneuvers.kt:118
"straight" to Mv.CONTINUE,    // :119
"continue" to Mv.CONTINUE,    // :120
"left" to Mv.TURN_LEFT,       // :121
"right" to Mv.TURN_RIGHT,     // :122
```

so a hypothetical Maps resource named `ic_continue_right` or
`ic_straight_then_right` classifies as **CONTINUE**. The header comment
(`Maneuvers.kt:82-85`) states the ordering rule as "most specific first" and it
is correctly applied for `merge_left` vs `left`, but "continue"/"straight" are
*generic* tokens sitting above the turn tokens rather than below them. **Not the
cause here** (tier 1 never runs), but it is a real latent path to a wrong
CONTINUE the day Maps ships resource icons. Ranked #7 below.

### Tier 2 — exact pixel hash (`Maneuvers.kt:212-219`)

`BY_HASH["c2a2c91"] → Mv.CONTINUE` (`Maneuvers.kt:144`). For a turn glyph to land
here it would have to *collide* with the continue glyph's hash.

The hash is `hash * 31 + (alpha shr 5)` seeded at 17 over 1024 pixels
(`Maneuvers.kt:330-341`), accumulating into a 32-bit Int. NAV_DATA.md:83 reports
"zero collisions across five rides" over ten glyphs. A collision between two of
a ten-element set in a 32-bit space is negligible. **Ruled out** as a practical
explanation, though note this is a statistical argument, not a proof.

The far more likely tier-2 behaviour is the one described in section 1: **no
collision at all — Maps genuinely sent `c2a2c91`, and `c2a2c91` genuinely means
"CONTINUE *or* depart".** The ambiguity is in the table, not in the matcher.

### Tier 3 — fuzzy bitmap match (`Maneuvers.kt:221-223`, `fuzzy` at :274-296)

Two real structural findings here, one reassuring and one not.

**The learning invariant holds. VERIFIED.** `learn()` is called from exactly two
places: `Maneuvers.kt:207` (tier 1 hit) and `Maneuvers.kt:217` (tier 2 hit). The
fuzzy branch at `Maneuvers.kt:221-223` returns without learning. So a fuzzy match
can never seed the reference set, and the "one near-miss drags the set onto the
wrong glyph" failure the comment at `Maneuvers.kt:298-301` warns about **cannot
happen**. `SEEDED` (`Maneuvers.kt:177-182`) is empty, so `refs` contains only
tier-1/tier-2-confirmed signatures.

`learn()` is further guarded at `Maneuvers.kt:307`: it refuses to add a signature
within `MAX_DIFF_BITS` (32) of *any* existing ref, of any code. So the reference
set is guaranteed pairwise ≥32 bits apart. Conservative and correct.

**`AMBIGUOUS_WITHIN` is not protective in the case that matters. VERIFIED.**
`fuzzy` (`Maneuvers.kt:284-294`):

```kotlin
var rivalDiff = Int.MAX_VALUE          // closest ref with a *different* code
for (s in refs) {
    if (s.code == win.code) continue
    val d = diff(rows, s.rows)
    if (d < rivalDiff) rivalDiff = d
}
if (rivalDiff - bestDiff < AMBIGUOUS_WITHIN) { ...refuse... }
```

`rivalDiff` initialises to `Int.MAX_VALUE`. If `refs` currently holds signatures
of **only one distinct code**, the loop never assigns, `rivalDiff - bestDiff`
overflows to an enormous positive number, and the guard passes unconditionally.
The *only* remaining gate is `bestDiff < MAX_DIFF_BITS` at `Maneuvers.kt:282`.

This is reachable. `refs` is cleared on every listener reconnect
(`MapsParser.reset()` → `Maneuvers.reset()`, `MapsParser.kt:302-305`, called from
`NavListenerService.kt:77`), and CONTINUE is by far the most frequent glyph on a
route, so **"refs contains exactly one signature, and it is CONTINUE" is the
normal state for the first minutes of every ride.** In that window the ambiguity
guard is inert by construction.

Note also that `AMBIGUOUS_WITHIN` is a *relative margin*, not an absolute quality
test: a winner at 31 bits with a rival at 40 bits is accepted, even though 31
bits is a poor match.

**But it still probably did not cause this. INFERRED.** For the hole to bite, a
right-turn glyph would have to render within **32 of 1024 bits** (3.1%) of the
continue glyph. Both glyphs carry roughly 150-200 set pixels at 32×32
(`SPEC_MANEUVER_ICONS.md` puts shaft width at 16% and head base at 52% of the
box), and a straight arrow versus a right-turn arrow differ across the entire
upper-right quadrant — order 100-200 bits, not 31. So the fuzzy path is a real
defect in the guard but an implausible cause of *this* report. Ranked #4.

**Verdict on question 2: `classify()` returning CONTINUE for a turn glyph is
possible in principle via the tier-3 hole, but the far simpler reading is that
it was handed the genuine CONTINUE/depart glyph and classified it correctly.
The mis-mapping is in `BY_HASH`'s one-hash-two-meanings entry, not in the
matcher.**

---

## 3. Can the parser HOLD a stale maneuver?

**No. VERIFIED, and this is the cleanest result in the investigation.**

Every carried-forward field in `MapsParser`, exhaustively:

| Field | Declared | Held where | Can it stale the maneuver? |
|---|---|---|---|
| `heldDistM` | `MapsParser.kt:179` | `:385-388` — `parsedDist ?: heldDistM` | No. Distance only. |
| `arrivalMinuteOfDay` | `:160` | `:566-571` | No. And it holds the *clock target*, recomputing the countdown each packet, so it cannot silently age (`:557-563`). |
| `heldRemaining100m` | `:164` | `:394` (overwritten every navigating packet), read only by `reroutingUpdate` `:349` | No. |
| `heldEtaMin` | `:165` | `:398`, same shape | No. |
| `lastProgressMax` | `:180` | `:428-429` | No — route-replacement detection only. |
| `lastManeuver` | `:182` | `:248-252` | **No — used only to gate a log line.** Never read back into an update. |
| `lastArrived` | `:155` | `:247`, read by `poll()` `:284` | No. |

The maneuver itself: `navigatingUpdate` computes `match` at `MapsParser.kt:383`
and assigns `maneuver = match.code` at `MapsParser.kt:400`. There is no `?:`, no
fallback, no previous value in that expression. **When the icon is missing or
unclassifiable, `Mv.UNKNOWN` is sent, not the previous value.** `classify`
returns `Match(Mv.UNKNOWN, "no-icon")` for a null icon (`Maneuvers.kt:197`),
`"no-drawable"` for a render failure (`Maneuvers.kt:212`), and `UNMATCHED`
(`Maneuvers.kt:77`, `:226`) for an unmatched bitmap.

The other three state branches also send fixed maneuvers, never held ones:
`startingUpdate` → `UNKNOWN` (`:331-336`), `reroutingUpdate` → `UNKNOWN`
(`:345-353`, with an explicit comment that the previous arrow no longer describes
the road), `arrivingUpdate` → `DESTINATION` (`:361-369`).

Combined with section 0 — UNKNOWN renders as "?" — **the "held maneuver with a
fresh distance" failure the brief calls the dangerous combination is not
reachable in this codebase.** If it had happened, the rider would have seen a
question mark, which is exactly the design intent.

The *inverse* hold is real and is by design: `heldDistM` freezes the **distance**
while the maneuver keeps updating (`MapsParser.kt:166-179` documents why — a
naive zero put "0 m" on the panel 40 m from a junction). That is the safe
direction: a frozen number beside a live arrow, not a live number beside a frozen
arrow.

---

## 4. Is there a path where distance updates but maneuver does not?

Yes — and structurally it is unavoidable, because the two fields have entirely
independent sources: the maneuver is a **bitmap** (`chipIcon`,
`MapsParser.kt:220`), the distance is a **string** (`primaryInfo`,
`MapsParser.kt:216`). They fail independently.

**Direction A — distance updates, maneuver constant.** This is the *normal*
appearance of a long step, and it is exactly what section 1 describes: the
distance counts 450 → 400 → 350 while `chipIcon` stays on the depart/continue
glyph. Nothing anywhere in the stack flags it, because nothing can tell it apart
from a genuine "continue straight for 450 m".

This is the heart of why the failure was invisible:

- `MapsParser.kt:248-252` logs **only when the maneuver changes**, so a whole
  450 m approach on a wrong-but-constant CONTINUE produces exactly **one** log
  line, timestamped at the start.
- `BleLink.flushNav` (`BleLink.kt:814-832`) de-duplicates on the whole frame, so
  every distance tick still writes and the device's arrival-counting watchdog
  (`BleLink.kt:169-176`) stays fed.
- The firmware redraws on the new distance and keeps drawing the same arrow.

**A stale maneuver with a counting-down distance looks perfectly healthy at every
layer**, which is what the brief anticipated — the only correction is that here
the maneuver is not *stale*, it is *faithfully reproduced and semantically
wrong*.

**Direction B — maneuver updates, distance frozen.** `heldDistM`
(`MapsParser.kt:385-388`) when `primaryInfo` carries a road name or the maneuver
text instead of a distance (rule 2, `NAV_DATA.md:150-157`). Deliberate, safe,
documented.

**Minor finding — up to ~1.9 s of added latency on a maneuver change.**
`BleLink.flushNav:819` drops a submission that arrives within
`MIN_NAV_INTERVAL_MS` = 900 ms (`BleLink.kt:167`) of the last write; the frame is
retained in `pendingNav` and goes out on the next 1 Hz tick
(`BleLink.kt:385-391`, `TICK_MS` = 1000). So worst case a genuine step change is
delayed ~1.9 s. Correct behaviour for a radio budget, worth knowing, and **three
orders of magnitude too small to explain 450 m**.

---

## 5. Does the 15 s removal debounce interact badly with a step change?

**No. A step boundary cannot be swallowed. VERIFIED.**

The debounce is strictly additive — it gates *end-of-route only*, and never gates
a posted notification:

- `MapsParser.onPosted` (`:195-254`) parses and returns an update on **every**
  Maps navigation notification. The debounce appears in it only at `:203-207`,
  where a re-post *cancels* a pending end-of-route and logs how much time was
  left. It does not `return` early, does not suppress, does not merge.
- `MapsParser.onRemoved` (`:261-272`) arms `pendingEndAt` and explicitly emits
  nothing.
- `MapsParser.poll` (`:281-290`) is the only consumer of the timer and only ever
  produces `NavUpdate(navActive = false)`.
- `NavListenerService` mirrors this exactly: `onNotificationPosted` →
  `handleIfMaps` → `parser.onPosted(...)?.let { push(it) }`
  (`NavListenerService.kt:82-85, 104-107`); `onNotificationRemoved` for the Maps
  package returns immediately after arming (`:87-93`).

So a remove/re-post straddling a step change delivers the new step on the
re-post, in the normal way. The only loss during a remove/re-post gap is that no
new packet arrives — and NAV_DATA.md:203-225 is explicit that this gap is
sub-second in practice.

Two adjacent observations, neither causal here:

- `parser.reset()` on `onListenerDisconnected` (`NavListenerService.kt:77`)
  clears `Maneuvers.refs`. That is the mechanism that makes the section-2 tier-3
  hole reachable — after a reconnect the reference set is empty and refills with
  CONTINUE first.
- `MapsParser.resetRoute()` (`:311-324`) clears `heldDistM` and `lastManeuver`
  but deliberately preserves learned signatures (`:307-310` comment: "the glyph
  set belongs to the installed Maps build, not to the route"). Correct.

---

## 6. Logging: what exists, and the one line to add

### What already exists

| Log | Location | Fires when | Would it have settled this? |
|---|---|---|---|
| `maneuver -> NAME  N m  "instr" eta= rem=` | `MapsParser.kt:248-252` | **only when the maneuver code changes** | No. One line for the whole 450 m approach, and it does not say *why* CONTINUE was chosen. |
| `PROBE shortCriticalText=… nowbarSecondary=… flags=…` | `MapsParser.kt:654-658` | only when the **text** signature changes (`:633-635`) | Partly — it would show `title` and `nowbarSecondary`. But it omits the icon hash entirely. |
| `PROBE-ICONS chip=… second=… nowbar=…` | `MapsParser.kt:660-662` | same text-signature gate | No. Gated on *text* change, so during a long step it is silent, and it logs maneuver names without hashes or tiers. |
| `icon ambiguous: … refusing to guess` | `Maneuvers.kt:291-293` | fuzzy near-tie | Only for a case that ends in UNKNOWN, i.e. not this one. |
| `UNRECOGNISED maneuver icon hash=… <ASCII art>` | `Maneuvers.kt:372-386` | once per distinct unmatched hash | Only for a case that ends in UNKNOWN. |

**The most galling gap: `Match.via` already carries the answer and is never
logged anywhere.** `Maneuvers.kt:73` defines `data class Match(val code: Int,
val via: String)`, and `via` is populated with exactly the discriminating string
— `"res=<name>"`, `"hash=c2a2c91"`, `"fuzzy=<label>/12b"`, `"no-icon"`,
`"no-match"`. It is computed on every classification, threaded through
`navigatingUpdate` (`MapsParser.kt:383`), read only for `match.known`
(`MapsParser.kt:404`), and thrown away. **The tier that produced the answer is
already known and discarded.**

Note also that a **successful fuzzy match logs nothing at all** — no warning, no
`via` — so if the tier-3 hole in section 2 ever does bite, there is currently no
trace of it.

### The single extra log line

Add to `MapsParser.navigatingUpdate`, immediately after
`val match = Maneuvers.classify(ctx, icon, title)` (`MapsParser.kt:383`), with
one new field `private var lastIconSig: String? = null` beside `lastManeuver`
(`MapsParser.kt:182`), cleared in `resetRoute()` (`MapsParser.kt:311-324`):

```kotlin
val iconSig = "${match.code}|${match.via}|$title"
if (iconSig != lastIconSig) {
    lastIconSig = iconSig
    Log.i(TAG, "ICON ${Mv.name(match.code)} via=${match.via} d=${parseDistance(primary)}m " +
            "title=\"$title\" primary=\"$primary\" secondary=\"$secondary\"")
}
```

Why this one line is sufficient, and why each piece earns its place:

- **`via`** names the tier and, for tier 2, *contains the raw hash*. It separates
  the three surviving hypotheses outright: `via=hash=c2a2c91` confirms Maps sent
  the genuine continue/depart glyph (#1); `via=hash=93f8340f` arriving late
  confirms a real lag (#2); `via=fuzzy=…` confirms the tier-3 hole (#4).
- **`title`** is the decisive datum and is currently only logged on a text
  change. `"Head toward Moulana Azad Rd"` versus `"Turn right onto Moulana Azad
  Rd"` settles section 1's remaining unknown — whether the notification was on
  the depart step or on the turn step — in a single glance.
- **The distance** turns the log into a distance-indexed trace, which is what
  answers the one thing NAV_DATA.md never recorded: **at what distance does
  `chipIcon` switch from the continue glyph to the turn glyph?**
- **Gating on the signature, not on the maneuver code**, is the fix for the
  existing blind spot. `MapsParser.kt:248` fires on `update.maneuver !=
  lastManeuver` and is therefore silent for exactly the 450 m in which the bug
  lives; including `via` and `title` in the key makes it fire on every genuine
  *step* change while still staying quiet at ~1 Hz on a long straight.

One ride down Jawahar Rd produces a line per step and closes the question.

**Cheaper variant, if only a diff to an existing line is acceptable:** append
`via=${match.via}` and `title="$title"` to `MapsParser.kt:250` and widen its
trigger at `:248` to include the title. Same information, one fewer field, but it
loses the distance-indexed trace that answers the switch-over question.

---

## 7. Ranked conclusions

| # | Explanation | Confidence | Ours? |
|---|---|---|---|
| 1 | **`chipIcon` depicted the depart/"Head toward" step while Maps' banner depicted the right turn that terminates it.** One hash, `c2a2c91`, means both CONTINUE and depart (`NAV_DATA.md:89`, `Maneuvers.kt:144`); we render both as a confident straight arrow. Reproducible from the dump at `NAV_DATA.md:479-528`, captured on the same road, showing `title="Head toward Moulana Azad Rd"` + `PROBE-ICONS chip=CONTINUE` while Maps drew "Then →". Traced through `chooseInstruction` (`MapsParser.kt:468-471`) the panel would read **[straight] 450 "Moulana Azad Rd"** against a banner of **↱ 450 m Moulana Azad Rd** — every field matching except the arrow. | **High** for the mechanism; **inferred** that it is what the rider saw | Not a parse bug. **Our bug is presenting it as a confident junction call.** |
| 2 | Rider glanced at the panel and took the screenshot at different moments; his "left" recollection is imprecise, so his "straight" may be too. | Medium, and compatible with #1 | Not ours |
| 3 | Maps' notification genuinely lags its own banner across a step boundary. | **Low as the cause; UNKNOWN as a phenomenon** — no measurement exists either way. Bounded by ~1 Hz posting plus ≤1.9 s of our own rate limit (`BleLink.kt:167,819`), i.e. tens of metres. Cannot produce 450 m. | Not ours; mitigation only |
| 4 | Tier-3 fuzzy matched the turn glyph onto a learned CONTINUE signature. The guard hole is **real and verified** (`Maneuvers.kt:284-294`: `rivalDiff` stays `Int.MAX_VALUE` when `refs` holds one distinct code, so `AMBIGUOUS_WITHIN` is inert — the normal state early in every ride, since `refs` is cleared on reconnect at `NavListenerService.kt:77`). But it needs a right-turn glyph within 32/1024 bits of the continue glyph, ~5× closer than two different arrows plausibly render. | Low as the cause; the **defect is confirmed** and should be fixed on its own merit | **Ours** |
| 5 | Latent: `BY_NAME`'s unanchored substring scan puts `"straight"`/`"continue"`/`"depart"` above `"left"`/`"right"` (`Maneuvers.kt:118-122`), so a resource named `ic_continue_right` would classify CONTINUE. | Not the cause — tier 1 is dead while `chipIcon` is `type=1` (`NAV_DATA.md:509`, `Maneuvers.kt:358`) | **Ours**, latent |
| — | Stale/held maneuver in the parser | **RULED OUT.** Maneuver is never held (`MapsParser.kt:400`); every failure path returns UNKNOWN, and UNKNOWN draws "?" not an arrow (`maneuvers.cpp:166-170`). The rider saw an arrow. | — |
| — | 15 s removal debounce swallowing a step boundary | **RULED OUT.** `onPosted` parses and emits unconditionally; the debounce gates only `poll()`'s end-of-route (`MapsParser.kt:195-254, 261-290`). | — |
| — | Firmware holding or substituting a maneuver | **RULED OUT.** `handleNav` applies the byte verbatim (`ble.cpp:152-176`); moving-map geometry is demo-only (`navigator.ino:91-92`). | — |

**Plain statement, as asked for:** the most likely explanation is *not* that Maps'
notification lags its own banner. It is that **the notification and the banner
depict different things** — the banner shows the maneuver at the end of the
current step, `chipIcon` (measurably, during a depart step) shows the step's own
travel action — and our table collapses the two meanings of `c2a2c91` into one
confident straight arrow. That is mostly "not our bug", but the mitigation is
squarely ours, because a confident wrong arrow at a junction is the one failure
this project's whole design refuses to ship.

---

## Proposed fixes — specified, deliberately NOT applied

### F1 — stop rendering "depart" as "continue" (addresses #1)

`c2a2c91` means two things. Split them using `title`, which is safe here in a way
the `Maneuvers.kt:190-193` rule anticipates: text would decide *depart vs
continue*, never *left vs right*, so it cannot point the rider the wrong way.

1. Add `Mv.DEPART` to `NavPacket.kt` (next free code after `FERRY = 0x15`, i.e.
   `0x16`), plus its `Mv.name` arm.
2. In `MapsParser.navigatingUpdate`, after `MapsParser.kt:383`: if
   `match.code == Mv.CONTINUE` and `title` matches
   `^\s*(head|start|depart|proceed)\b` (case-insensitive), substitute
   `Mv.DEPART`.
3. Firmware: a distinct `G_DEPART` glyph — the spec's own reasoning at
   `SPEC_MANEUVER_ICONS.md:759-764` (the destination pennant is deliberately not
   the maneuver head, so it cannot read as a right turn) applies directly: a
   depart mark must not read as "the road ahead is straight". A shaft with an
   origin dot at its foot, no junction implied.
4. Update `BLE_PROTOCOL.md` and `firmware/navigator/nav_types.h` together.

This does not recover the turn — nothing can, `NAV_DATA.md:517-536` closes that —
but it stops the panel *asserting* straight-on when Maps is asserting a turn.

### F2 — make `AMBIGUOUS_WITHIN` actually protective (addresses #4)

In `Maneuvers.fuzzy` (`Maneuvers.kt:284-294`), the margin test must not pass by
default when there is no rival. Add an absolute quality floor alongside it:

```kotlin
// A margin test with no rival is not a test. Require the winner to be a
// genuinely good match before trusting a set that has nothing to compare it to.
private const val LONE_REF_MAX_BITS = 12    // vs MAX_DIFF_BITS = 32

if (rivalDiff == Int.MAX_VALUE && bestDiff > LONE_REF_MAX_BITS) {
    Log.w(TAG, "icon fuzzy=${Mv.name(win.code)} at $bestDiff bits with no rival " +
            "to check against - refusing to guess")
    return null
}
if (rivalDiff - bestDiff < AMBIGUOUS_WITHIN) { /* existing guard */ }
```

Also guard the subtraction itself against the `Int.MAX_VALUE` sentinel rather
than relying on overflow arithmetic to produce a large positive.

### F3 — log a successful fuzzy match (addresses the section-6 blind spot)

`fuzzy` returns `Match(win.code, "fuzzy=${win.label}/${bestDiff}b")`
(`Maneuvers.kt:295`) and nothing records it. The `ICON` line in section 6 covers
this for free once `via` is logged; if the ICON line is not adopted, add a
one-shot `Log.i` in `fuzzy` keyed on `win.label`.

### F4 — reorder `BY_NAME` (addresses #5, latent)

Move `"depart"`, `"straight"`, `"continue"` (`Maneuvers.kt:118-120`) **below**
`"left"` and `"right"` (`:121-122`), or anchor the generic entries. The
"most specific first" rule the header states (`:82-85`) is not currently
satisfied for these three.

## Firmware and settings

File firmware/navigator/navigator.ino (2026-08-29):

/*
  navigator.ino — JiffyTrails handlebar navigator.

  Handlebar display for a Triumph Speed 400. The phone does the routing and
  parses Google Maps' ongoing notification; this device shows the maneuver so
  the phone can stay in a pocket.

  Stage 5: BLE link and protocol. No Android app yet — drive it with
  tools/navsim.py or nRF Connect. See docs/STAGE5_TEST_PLAN.md.

  Structure and responsibilities:
    nav_types.h    the contract. NavState is the only shared truth
    ble.cpp        NimBLE peripheral, framing, defensive parse
    watchdog.cpp   freshness, counted by arrivals not changes
    display.cpp    renders NavState, decides nothing
    maneuvers.cpp  vector glyphs

  Hardware and the TFT_eSPI config trap are documented in docs/HARDWARE.md.
  Read the sketchbook section there before editing any User_Setup.h.
*/

#include "nav_types.h"
#include "ble.h"
#include "display.h"
#include "watchdog.h"
#include "demo.h"
#include "backlight.h"
// WiFi and ArduinoOTA are included HERE, not only in ota.cpp, because the
// Arduino builder resolves library dependencies from the sketch file. An
// include that appears solely in a .cpp is not discovered, and the build fails
// with "ArduinoOTA.h: No such file or directory" while the library sits in the
// core the whole time.
#include <WiFi.h>
#include <ArduinoOTA.h>
#include "ota.h"

static const char* DEVICE_NAME = "JiffyTrails";

// The one instance. Everything else takes it by reference.
static NavState state;

// If the phone goes quiet, prompt rather than sit waiting. Maps can legitimately
// leave a notification unchanged for a long stretch, so the phone may have
// nothing new to volunteer — but it should still be asked before the watchdog
// declares the data stale. Idea taken from alexanderlavrushko's BLE HUD, which
// sends an empty indication for exactly this reason (see docs/PRIOR_ART.md).
static const uint32_t NUDGE_AFTER_MS = 4000;
static const uint32_t NUDGE_EVERY_MS = 2000;
static uint32_t lastNudgeMs = 0;

static void nudgeIfQuiet() {
  if (!state.linkUp || state.packetCount == 0) return;

  const uint32_t now = millis();
  if (now - state.lastPacketMs < NUDGE_AFTER_MS) return;
  if (now - lastNudgeMs < NUDGE_EVERY_MS) return;

  const uint8_t poll = 0x00;   // zero-length prod, no packet type claimed
  bleNotify(&poll, 1);
  lastNudgeMs = now;
}

void setup() {
  Serial.begin(115200);
  delay(200);
  Serial.println(F("\nJiffyTrails navigator — stage 5, BLE link"));

  // Why we last started. A corrupted panel on the road could be a brown-out
  // reboot rather than a bus glitch, and those want completely different fixes
  // - a capacitor versus a shorter lead. One line closes the biggest gap in
  // the evidence for docs/BUG_PANEL_CORRUPTION.md.
  Serial.printf("boot: reset reason %d\n", (int)esp_reset_reason());

  displayBegin();
  backlightBegin();   // panel is alive, so it is safe to light it

  displayBootBegin();
  displayBootStage(1);            // panel is up - the ring can honestly say so

  bleBegin(&state, DEVICE_NAME);
  Serial.printf("advertising as \"%s\"\n", DEVICE_NAME);
  displayBootStage(2);            // radio is up

  // Armed, not joined. otaTick brings the radio up only when there is no
  // route - see ota.h for why the phone hotspot rather than a home network.
  otaBegin();

  /*
    Now wait for a phone, but not forever. The ring stalling at two thirds is
    the honest report of "advertising, nobody has answered" - but a rider who
    left their phone at home must not be left looking at a splash, so this
    gives up after BOOT_LINK_WAIT_MS and hands over to the normal screen, which
    says PHONE DISCONNECTED and means it.

    bleTick() and watchdogTick() run here so linkUp is real rather than assumed.
  */
  const uint32_t waitUntil = millis() + 2500;
  while (millis() < waitUntil && !state.linkUp) {
    bleTick();
    watchdogTick(state);
    delay(20);
  }
  displayBootFinish(state.linkUp);
}

void loop() {
  bleTick();              // re-advertises after a disconnect

  // A demo owns NavState while it runs. The watchdog must not also run: it
  // would see no packets arriving and paint STALE over the demo.
  // Gated on a LIVE route, not merely on a NAV_ACTIVE flag. If the link drops
  // mid-route without a final nav_active=0, the flag sticks - and OTA would be
  // locked out exactly when the device is parked, which is the only time it is
  // allowed up and the only way back in once the case is sealed.
  otaTick(state.linkUp && !state.stale && state.navActive());
  if (otaBusy()) return;          // the update owns the screen

  backlightTick();        // ambient light -> backlight PWM
  demoSerial(state);
  if (demoActive()) demoTick(state);
  else              watchdogTick(state);   // link state and freshness
  displaySetNight(state.night);
  backlightSetNight(state.night);
  displayTick();          // re-inits the panel if it has lost its config
  nudgeIfQuiet();
  displayRender(state);   // renders whatever state now says, and nothing else
}

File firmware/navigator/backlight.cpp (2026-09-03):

#include "backlight.h"
#include <Arduino.h>
#include <math.h>

/*
  ★ WHY THE LDR IS COMPILED OUT BY DEFAULT

  The rider asked the right question: is the sensor worth it, given the panel
  is not very bright to begin with? Working through it says no - not for this
  build - and the numbers are already in docs/HARDWARE.md.

  IN DAYLIGHT, DIMMING IS NEVER WANTED. The measured contrast in sun is
  1.17:1 against the 5:1 that readable text needs (HARDWARE.md, "This panel,
  this city" - lines 237-249 today; cite the heading, because the line numbers
  in this citation had already rotted once). The
  panel is already losing to glare by a factor of four. There is no ambient
  level between dawn and dusk where the right answer is anything but maximum.
  An auto-dimmer spends its whole day arriving at the same conclusion.

  AT NIGHT, THE PROBLEM IS REAL, BUT NIGHT MODE ALREADY SOLVES MOST OF IT.
  displaySetNight() inverts to white-on-black, so the great majority of pixels
  go dark and emitted light falls with them. What is left is a backlight still
  running at full duty behind them, and that is worth pulling down - which is
  what this file now does.

  AND THE SENSOR IS NOT FREE. It needs a hole in the top face of a waterproof
  case, on the surface rain actually lands on, potted with epoxy. That is a
  deliberate leak path through the one part of the enclosure whose entire job
  is not leaking, bought for a refinement on a problem the night flag already
  covers.

  So v1 drives brightness from s.night, which the phone derives from
  SolarClock's real sunrise and sunset (LinkService.kt:448) - a source no
  tunnel, streetlight or jacket sleeve can fool.

  The LDR path below is complete and tested-by-construction. Set
  BACKLIGHT_USE_LDR to 1 and fit the parts if night mode alone proves not to be
  enough on a real ride. Nothing else has to change.
*/
#define BACKLIGHT_USE_LDR 0

// ---------------------------------------------------------------- hardware

/*
  Straight to the module LED pin. NO external transistor.

  The module already carries one: the LED header pin feeds a 1k base resistor
  into an S8050 NPN switching the backlight cathodes to ground (LCDWIKI MSP2807
  schematic). It is a logic input, not a supply rail, and it costs this pin
  (3.3 - 0.7) / 1000 = 2.6 mA against a 40 mA maximum.

  Confirm before soldering, because this family of boards is not consistent:
  put 1k in series with the LED pin. Stays bright = transistor present, wire it
  straight. Goes dark = the pin really is the LED supply and it needs a 2N7000
  low-side switch after all. See docs/HARDWARE.md.
*/
static const uint8_t PIN_BL  = 17;
#if BACKLIGHT_USE_LDR
static const uint8_t PIN_LDR = 36;   // ★ ADC1 only - see backlight.h
#endif

/*
  20 kHz, comfortably above hearing. Backlight PWM is commonly run at 1-5 kHz
  and on this project that would be a mistake twice over: some panel boards
  sing audibly at those rates, and a low carrier beats against a phone camera's
  rolling shutter, so every photograph of the display comes out banded. This
  display is debugged largely from photographs of it, so a carrier that ruins
  photographs would cost real time.

  10-bit at 20 kHz is well inside the LEDC's range - the ceiling is
  log2(80 MHz / 20 kHz) = 12 bits.
*/
static const uint32_t PWM_HZ   = 20000;
static const uint8_t  PWM_BITS = 10;
static const uint16_t PWM_MAX  = (1 << PWM_BITS) - 1;
static const uint8_t  PWM_CH   = 0;      // only used by the core 2.x API

// ---------------------------------------------------------------- response

static const uint8_t DAY_PCT   = 100;
/*
  35% rather than something lower. The temptation is to go dimmer, but the
  screen still has to be read at a glance at speed, and night riding in India
  includes plenty of unlit road where oncoming headlights keep the eye far from
  fully dark-adapted. Dark enough not to dazzle, bright enough to still be a
  glance rather than a stare.
*/
static const uint8_t NIGHT_PCT = 35;
static const uint8_t MIN_PCT   = 20;    // never off - see below

/*
  A one-second fade rather than a step. The day/night transition fires once,
  from a clock, often while moving - and a panel that changes brightness
  instantly in peripheral vision reads as a fault or a flicker, which is
  exactly the reflex this project has spent three bugs trying to eliminate.
*/
static const uint32_t FADE_MS  = 1000;
static const uint32_t TICK_MS  = 20;

/*
  Perceived brightness is not proportional to duty.

  ★ NOTE THE DIRECTION - the comment here used to have it backwards, and
  somebody would eventually have "fixed" it the wrong way. A forward gamma of
  2.2 COMPRESSES the low end rather than spreading it: 0.35^2.2 = 0.099, so 35
  would map to under a tenth of full scale. It is the MIN_PCT floor underneath
  that rescues the result to 28% duty, which is what makes night mode read as a
  bit over a third rather than nearly off. The number was right; the stated
  reason was inverted.

  Measured curve, pct -> % of full duty:
      0 -> 20.0   10 -> 20.5   20 -> 22.3   35 -> 28.0
     50 -> 37.4   75 -> 62.5  100 -> 100.0
*/
static const float GAMMA = 2.2f;

// ---------------------------------------------------------------- state

static float    curPct     = (float)DAY_PCT;
static uint8_t  targetPct  = DAY_PCT;
static uint8_t  override_  = 0;              // 0 = automatic
static uint32_t lastTick   = 0;

// ---------------------------------------------------------------- pwm

/*
  The LEDC API was renamed between ESP32 Arduino core 2.x and 3.x. Both are in
  circulation, so the version is tested rather than assumed - the 2.x calls do
  not exist in 3.x and the build fails outright rather than misbehaving.
*/
static bool pwmOk = false;

static void pwmBegin() {
#if defined(ESP_ARDUINO_VERSION_MAJOR) && ESP_ARDUINO_VERSION_MAJOR >= 3
  pwmOk = ledcAttach(PIN_BL, PWM_HZ, PWM_BITS);
#else
  pwmOk = (ledcSetup(PWM_CH, PWM_HZ, PWM_BITS) != 0);
  if (pwmOk) ledcAttachPin(PIN_BL, PWM_CH);
#endif
  /*
    ★ FAIL BRIGHT. Both LEDC calls return a status and both used to be
    discarded. If the timer cannot be allocated, GPIO 17 is left a floating
    input, the module's S8050 base sees nothing, and the panel is simply dark -
    silently, with no log line, in a module whose stated doctrine everywhere
    else is that the one input never to trust with darkening the display is one
    that has failed.
  */
  if (!pwmOk) {
    Serial.println(F("backlight: ledcAttach FAILED - pinning full bright"));
    pinMode(PIN_BL, OUTPUT);
    digitalWrite(PIN_BL, HIGH);
  }
}

static void pwmWrite(uint16_t duty) {
  if (!pwmOk) return;            // already pinned HIGH by pwmBegin
#if defined(ESP_ARDUINO_VERSION_MAJOR) && ESP_ARDUINO_VERSION_MAJOR >= 3
  ledcWrite(PIN_BL, duty);
#else
  ledcWrite(PWM_CH, duty);
#endif
}
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

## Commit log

2026-08-22 hw: display bring-up complete — ILI9341_2_DRIVER @ 27 MHz
    The white screen was three problems stacked, only two of which were ever
    actually tested.
    The root cause was that every User_Setup.h edit went to a file the compiler
    never read. Sketchbook is C:\dev\Arduino (directories.user in
    ~/.arduinoIDE/arduino-cli.yaml), but a stale TFT_eSPI also sits under
    OneDrive's Documents folder — which on this machine is localized to Japanese
    and named ドキュメント. %USERPROFILE%\Documents has no Arduino folder at all,
    so anything reasoning about "Documents\Arduino\libraries" landed on the dead
    copy. Correct fixes had already been made and had simply never compiled.
    Once edits reached the live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
2026-08-22 docs: correct stale hardware claims; add sunlight_test sketch
    The build plan and project state still described the pre-bring-up world and
    contradicted the working build in three places that would mislead anyone
    following them:
    - BUILD_PLAN Stage 4 wiring said RESET on GPIO 4. It is 16; 4 is not broken
    out on the LOLIN32. Config line said ILI9341_DRIVER at 40 MHz, both wrong.
    - BUILD_PLAN Stage 3 said board "ESP32 Dev Module" and to install a CP2102
    driver. Board is WEMOS LOLIN32 and the USB chip is CH340.
    - Status block still read "in transit / next: Android Studio".
    Adds firmware/sunlight_test/sunlight_test.ino for Stage 4 Test B. The library
    graphics test is not a fair readability pr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
    [sunlight_test.ino]
2026-08-22 feat: ui_mock — the nav interface driven by a scripted ride
    Renders the real interface with no BLE and no phone, so the design can be
    finalised before any protocol code exists. A canned Bengaluru route plays
    through at 1 Hz using the actual Google Maps distance quantisation from
    NAV_DATA.md, including the detail that values round to the band rather than
    stepping through it — a smooth countdown would flatter the design unfairly.
    Covers all four distance bands, the inverted sub-30 m state, the idle screen,
    and REROUTING / STALE / PHONE DISCONNECTED. Serial keys jump to any state so a
    design review does not have to wait for the script. Distance field is a
    200x80 sprite; the rest of each ba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
    [ui_mock.ino]
2026-08-22 fix(ui_mock): distance sprite was painting over the maneuver arrow
    Caught on hardware, not in review. At the sub-100 m band the arrow ran to
    x=162 while the opaque 200x80 distance sprite landed at x=96, so every tick
    repainted the right two thirds of the arrow white. What survived was the stem
    and elbow as a bare corner, plus the arrowhead tip poking above the sprite as
    a detached triangle - which reads as a rendering fault, not a right turn.
    Splits the screen into explicit columns instead of leaving the two elements to
    collide: SPR_X marks the sprite edge and ARROW_MAX_X the limit every glyph has
    to stay inside. Arrows moved left and trimmed to fit, sprite narrowed to 184
    and moved right s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
    [ui_mock.ino]
2026-08-22 fix(ui_mock): compute the layout instead of estimating it
    Two separate clipping faults, both from guessing pixel geometry rather than
    reading the library's width tables.
    The distance was clipped because font 8 digits are 55 px wide, so "700" is
    165 px. The text was right-aligned at x=146 inside a 184 px sprite, putting
    its left edge at -19 and silently cutting the leading digit. pushDistance now
    measures the unit with textWidth and right-aligns the whole block against the
    sprite edge, growing leftwards, so it cannot overflow either side.
    The arrow was clipped because drawManeuver took a centre point and grew the
    turn head to one side. A right turn extended to cx + 5s/3 while a left turn
    ex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
    [ui_mock.ino]
2026-08-22 docs: record the UI as hardware-validated, and the upload-path trap
    ui_mock now renders correctly on the panel with no clipping, so PROJECT_STATE
    records the nav interface as built and validated rather than merely written.
    Also documents the hour lost to arduino-cli: sketches flashed from the command
    line reported a verified hash and ran, printing to serial, while the panel
    stayed white. The same sketch through the IDE worked immediately with nothing
    physical changed, and board options are identical between the two paths. Most
    likely a script opening the serial port toggles DTR/RTS and drives the
    auto-reset circuit, leaving the board in reset or download mode. Not proven, so
    it is written d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
2026-08-23 docs: put numbers on the sunlight gate - the bare panel is expected to fail
    Researched ahead of running Stage 4 Test B, because the gate deserved better
    than an opinion.
    Glare is additive light over the whole panel: L = E x R / pi. Bengaluru clear
    noon is ~100,000 lux and a generic ILI9341 has a glossy air-gapped front at
    about 4.5% reflectance, so roughly 1430 nits of grey haze land on a panel
    rated 250-500. Ambient contrast comes out near 1.2:1 against the 5:1 that text
    needs. Not marginal - a grey rectangle.
    The useful consequence is that cutting ambient beats raising backlight, since E
    multiplies the glare term while the backlight only adds to the signal. A 5x
    reduction from a hood out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
2026-08-23 docs: prior art survey, and a state-detection bug it caught
    Adds docs/PRIOR_ART.md. Nothing found does this exact combination - Maps
    notification to BLE to ESP32 with TFT_eSPI - and nothing with real star count
    is both alive and licensed for reuse. But the individual pieces all exist, and
    two non-obvious findings were worth the search on their own.
    The first is a live bug in our own state detection, so NAV_DATA.md is corrected
    too: Maps removes and immediately re-posts its notification repeatedly during
    active navigation. Our rule said "notification removed means ended", which
    would have flapped the display between navigating and idle mid-ride - the exact
    never-show-a-wrong-state failure th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
2026-08-23 docs: the maker scene - crowded at the demo, empty at the product
    Completes the prior art survey with the Instagram/Reddit/YouTube layer.
    ProntoFPV turns out to be a person, not a product - an Indian drone and tech
    creator whose ProNav V2 reel did 1.87M plays and 385 comments, with no price,
    no shop link, no schematic and no repo published, and none of the "how do I buy
    this" comments answered. At least four independent makers reached this exact
    architecture, notification scraping to BLE to a small ESP32 TFT; two are open
    source.
    So the idea is not novel and the implementation is solved several times over.
    What no one on the list has done is ship: not one sells, and several openly say
    the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
2026-08-26 docs: lane guidance rejected - 0.52% OSM coverage in Bengaluru
    Adds docs/FEATURES.md to hold feature decisions, so rejected ideas keep their
    reasoning and are not re-proposed and re-researched.
    First entry is lane guidance. Measured rather than argued: an Overpass count
    over the Bengaluru bbox returns 43 ways tagged turn:lanes against 8,249
    primary/secondary/trunk/motorway ways. Half a percent.
    That one number kills every route to the feature at once, because Mapbox
    Directions, OsmAnd, Valhalla and raw OSM all read the same turn:lanes tags -
    they are not better data, only the same data with the hard parts pre-solved. At
    this coverage the display would show lane guidance so rarely it would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
2026-08-26 docs: map layout - raster is impossible here, vector is better anyway
    Raster tiles on this board fail for three independent reasons, any one fatal.
    There is no framebuffer: 320x240 RGB565 needs 153,600 contiguous bytes and
    TFT_eSPI's own author states a 16bpp sprite on ESP32 caps around 200x200, with
    100-180 KB free once NimBLE is resident. There is no rotation: heading-up needs
    the 400 px circumscribing square resident, 320,000 bytes, twice the free heap.
    And there is no tile source, since no SD is wired and wiring one shares SPI with
    the display at ~5 FPS before anything is drawn.
    The prior art agrees without exception. Every raster project on a full-size
    screen has PSRAM; every PSRAM-les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
2026-08-26 docs: power decided - cable only, no battery; and PETG is wrong
    Battery is rejected, and not on runtime grounds. An earlier guess that the
    backlight would limit this to an hour was wrong: measured draw is ~200 mA, so
    2000 mAh would give ~8 hours. The reasons are elsewhere.
    The charger cannot do what it appears to. The LOLIN32 uses a TP4054 with no
    power-path IC, and its 5 V pin is just VBUS, which puts the regulator input on
    the BAT node. That topology cannot distinguish charge current from load current,
    so with 200 mA against a C/10 threshold near 50 mA it never terminates and
    float-holds the cell at 4.2 V. There is also no over-discharge, over-current or
    cell temperature protection anywhe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
2026-08-26 feat: stage 5 - BLE peripheral, display module, and a test harness
    Firmware now compiles as a whole at 50% flash and 11% RAM.
    Structured around a fixed contract in nav_types.h so the work could be split
    without collisions: NavState is the only shared truth, BLE writes it, the
    watchdog annotates it, the display renders it and decides nothing. screenFor()
    is the single place precedence lives, and it puts link state and freshness
    above content so no failure path can leave a stale maneuver on screen.
    The watchdog counts packet arrivals rather than value changes, because
    NAV_DATA.md measured 64 seconds in slow traffic with no field changing while
    Maps kept posting at ~1 Hz. It also restarts its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
    [navigator.ino]
2026-08-26 fix: single writer for linkUp; document the spec gaps stage 5 exposed
    ble.cpp was setting NavState.linkUp in its connect and disconnect callbacks
    while watchdogTick derived the same field from bleConnected() every loop. They
    always agreed, so nothing misbehaved - but the callback consumed the
    disconnected-to-connected edge, which silently made the watchdog's "restart the
    freshness clock on reconnect" branch dead code that looked live. The watchdog is
    now the only writer.
    Documents three protocol rows that cannot be implemented as written, found by
    building against them rather than reading them:
    - 0x02 STATUS carries a flags byte with no documented bits anywhere in the doc
    set. The firmwa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
2026-08-26 feat: arrival screen, clock, and day/night polarity
    Three additions, one of which closes a gap that had been open since the
    protocol was written.
    ARRIVAL. NAV_ARRIVED was defined in the protocol and rendered nowhere - the
    display audit found the flag referenced zero times. Arriving simply dropped to
    idle, so the one moment the device should acknowledge was the one it skipped.
    Now a destination flag plus the destination name, latched by the watchdog for
    30 s because Maps drops its notification about 4.7 s after arrival, which
    clears nav_active and would otherwise flash the screen past.
    CLOCK. Idle previously said "READY", which is charmless and says nothing. It
    now shows the time, which is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
    [navigator.ino]
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2026-08-27 feat: panel watchdog - recover a display that has lost its config
    Observed twice on the bench and once overnight: the display renders correctly,
    then goes blank white, and stays white through a reflash - but comes back after
    unplugging and replugging power. That is the ILI9341 reverting to its power-on
    state, display off and sleep in, while the ESP32 carries on writing pixels to a
    controller that has stopped listening. A dip on the 3.3 V rail will do it, and
    so will a glitch on the reset line.
    The rail is already measured at 3.18 V with the backlight lit and no radio
    running; NimBLE adds ~130 mA in transmit bursts on top of that, which is a
    plausible trigger and fits the timing - it failed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
    [navigator.ino]
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2026-08-27 fix: stop the panel watchdog re-initialising a healthy display every 6 s
    Reported from the bike: the display flashes every six or seven seconds. The
    arithmetic names the culprit exactly -- PANEL_CHECK_MS 2000 times
    PANEL_FAIL_LIMIT 3 is six seconds.
    The watchdog asks the panel over MISO whether it is still configured. MISO is
    not wired on this build; it was removed deliberately and the panel is perfectly
    happy without it, because the display is write-only in normal use. A floating
    MISO reads back garbage, garbage never matches DISON|SLPOUT, and three strikes
    later the watchdog re-initialised a panel that had nothing wrong with it. The
    flash the rider sees IS the recovery.
    So the watchdog n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
    [navigator.ino]
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2026-08-27 replace ui_mock with a demo mode inside the real firmware
    Asked whether the UI mock was updated for the new screens. It was not, and it
    was worse than stale: ui_mock.ino was last touched on 22 Aug and had become a
    second implementation of every screen -- its own drawManeuver with nine
    maneuvers, its own enum where left was MV_LEFT rather than MV_TURN_LEFT, its
    own chrome and idle screen, and a traffic bar display.cpp had already removed.
    Updating it would have meant maintaining two copies of every screen, and it
    would have drifted again within the week. A mock showing a UI the device no
    longer has is worse than no mock, because it is a mock you might believe.
    So the demo moved inside the r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
    [demo.cpp, navigator.ino, ui_mock.ino]
2026-08-27 fix(demo): clear the arrival latch so a demo cannot be pinned to ARRIVED
    showArrival outranks everything below it in screenFor(), and the watchdog that
    normally clears it does not run while a demo owns NavState. So starting a demo
    in the thirty seconds after a real arrival would have held the display on the
    ARRIVED screen and appeared to ignore every keypress.
    Found by walking the precedence in screenFor() before writing the test steps,
    not by running it -- which is the same class of bug as the unreachable idle
    band, and the reason that precedence lives in exactly one function.
    [demo.cpp]
2026-08-27 fix three display bugs found on the panel; bring back ui_mock as a second sketch
    All three came from photographs of the real display, which continues to be the
    only reviewer that finds this class of bug.
    1. THE ALERT LEFT A STRIP BEHIND. A call band on the far screen paints
    156..240; when it was replaced by the footer, the footer cleared only
    190..240 and the top 34 px of the alert stayed up -- a white strip with the
    caller's name in it, sitting under the road name for the rest of the ride.
    alertTop is now derived from the SCREEN rather than from the band, so
    whatever region an alert could occupy is the region every band clears.
    2. THE PARKED ALERT CUT THE CLOCK IN HALF. Idl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
    [demo.cpp]
2026-08-28 fix: 1000 m rendered as "000 m" -- the leading digit was clipped
    layoutDistance switched to kilometres on m > 1000, so exactly 1000 took the
    metres branch. Font 8 digits are 55 px and the field has 172 px once the unit
    is placed: three digits is 165 and fits, four is 220 and overruns by 48, so the
    leading digit was cut off on the left.
    Reachable in ordinary use, not an edge case. Above 500 m the phone quantises to
    100 m steps, so the sequence really is 1200, 1100, 1000, 900 -- and a long
    "continue" instruction, which is exactly the case Maps announces as "continue
    for 3 km", sits in that range for minutes at a time.
    Now >=, so 1000 renders "1.0 km".
    The demo's first leg goes 900 -> 1200 m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
    [demo.cpp]
2026-08-28 feat: junction geometry -- draw the road, not just an arrow
    An arrow says "bear right". It cannot say "take the flyover, not the service
    road under it", and in Bengaluru those leave the junction on nearly the same
    bearing -- NAV_DATA.md records that Maps publishes no flyover distinction at
    all. This draws the actual shape.
    geom.cpp holds a view of the roads around the rider in the frame the phone will
    send: x right, y forward, decimetres, already rotated heading-up. Rotating on
    the phone is deliberate -- the phone knows the heading, and a heading the device
    guessed would be a confidently wrong drawing.
    HOW A FLYOVER READS. Ways are drawn lowest layer first, each as a
    background-coloured ha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
    [demo.cpp]
2026-08-28 fix: junction view flickered -- geometry was dragging a full-screen repaint
    Reported on the panel: pressing 'j' flickers. Two causes, one in the display
    and one in the demo, and the display one is the important half because it would
    have bitten a real 1 Hz feed just as hard.
    DISPLAY. geomKey() was folded into the chrome change test, so every new
    geometry window repainted the ENTIRE screen -- fillScreen, road name, footer,
    everything -- at whatever rate geometry arrived. Geometry owns exactly one box
    and should never have been able to repaint anything else.
    The glyph box is now its own function, drawNavGlyph, called both by drawChrome
    and by a targeted redraw when geomKey changes. Only that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
    [demo.cpp]
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2026-08-28 fix: the junction demo drew a pitchfork, not a junction
    From the panel, on the fork: it reads as an icon rather than a map. Correct,
    and the fault was the synthetic data, not the renderer.
    Every way stopped in mid-air inside the window and the road you were on started
    at your own wheels. Three short stubs radiating from a point IS a pitchfork.
    Real roads enter and leave the window, and the one you are on comes from behind
    you. All three junctions rebuilt so they do:
    - the route runs from -350 dm, through the rider, off the top edge
    - cross streets span the full width and are clipped at both sides
    - branches run past the window rather than ending at a vertex
    - the flyover gains a mi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
    [demo.cpp]
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2026-08-28 fix: parked and riding alerts flickered -- the demo restamped the arrival time
    Reported from the panel. Third instance of the same mistake, so it is worth
    naming rather than fixing quietly: a value that changes every frame used as a
    redraw key.
    notifyAtMs is an ARRIVAL TIME. The alerts demo set it to millis() on every
    tick, so every frame looked like a freshly arrived message. Both redraw keys
    are built from it -- idleKey in displayRender for the parked full-screen alert,
    and bandKey on the nav path for the riding strip -- so the screen repainted at
    loop rate in both cases.
    It is stepAtMs now, which is stable within a step. ALERT_MS is 3500 against a
    6000 ms dwell, so the alert stays up fo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
    [demo.cpp]
2026-08-28 fix seven findings from an adversarial review of the display and demo
    An independent read of the firmware found seven real defects plus one piece of
    dead code. Verified each against the source before touching it; all seven were
    real. Ranked by what a rider would actually see.
    1. NIGHT MODE WAS DESTROYED BY ANY DEMO, PERMANENTLY. baseline() forced
    s.night = false every tick, and night is the ONE faked field with no way
    back: the clock and battery are refreshed by PKT_STATUS at ~1 Hz and
    self-heal within a second of 'x', but night has a single writer, and CONFIG
    arrives on connect and on a polarity change only. So pressing 'g' at night
    flooded the panel white, and pressing 'x'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
    [demo.cpp]
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2026-08-29 fix: static screens could not heal, and the watchdog watched the wrong register
    The third road-test fault: a mirrored, 180-degree ARRIVED screen with a band of
    stale pixels beside it. Investigated properly in docs/BUG_PANEL_CORRUPTION.md.
    ★ THE FINDING IS IN SOFTWARE, NOT HARDWARE. UI_ARRIVED is the only screen with
    no repaint path at all - drawn once, then untouched for the whole 30 s dwell.
    UI_IDLE was given a clock/battery change key for exactly this reason; ARRIVED
    got nothing. Every other screen repaints something about once a second, so
    corruption there is scrubbed before it can be read.
    So arrival is not where corruption is likelier. It is the only place it can
    SURVIVE long enough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
    [navigator.ino]
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2026-08-29 hardware: a printable, parametric enclosure
    HARDWARE.md already specified this enclosure in detail - ASA not PETG, the
    2x1.5 gasket groove, the 25-35 mm hood, the ePTFE vent, blind bosses, the
    quarter-turn mount - and hardware/mount-design.html explains the mount. What
    was missing was anything anyone could actually print.
    case.scad is that. Open in OpenSCAD, F6, export STL. Every dimension worth
    changing is in one block at the top.
    Two things are deliberately made hard to skip:
    ★ MEASURE THE BOARDS. The defaults are typical for a 2.8" ILI9341 carrier
    and a LOLIN32, not measured from his. The case is the one part of this
    project that cannot be fixed in software afterwards.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
    [case.scad]
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2026-08-29 hardware: real measured dimensions, and drop the mount nobody could verify
    An agent traced the display to an LCDWIKI MSP2806 - the vendor publishes no
    dimensions at all and their "datasheet" is nine pages of demo code, but the pin
    list and the touch/no-touch SKU split identify it, and LCDWIKI ships a
    dimensioned drawing. Findings in docs/COMPONENT_DIMENSIONS.md.
    Two of my assumptions were wrong and each would have ruined a print:
    disp_pcb_t 1.6 -> 4.40 I used the bare PCB thickness where the MODULE is
    glass + tape + PCB. The lid would have closed onto
    the panel glass.
    active_off 0.0 -> 4.90 The glass is NOT centred. The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
    [case.scad]
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2026-08-29 Back-opening case, single-part mount, and the staleness fix
    Six independent reviews took the enclosure and firmware apart. This is the
    result. Nothing here is committed to main - the print is a one-shot and the
    display measurements are not all closed yet.
    FIRMWARE - the serious one
    Two reviewers, working separately on opposite ends of the link, found the two
    halves of the same failure: the phone restates a dead maneuver forever, and
    the device treats any packet as proof of freshness. watchdogNotePacket fired
    on every packet type, so a STATUS every 30 s cleared s.stale while the nav
    content rotted. If Maps died mid-ride the panel would hold the last turn,
    confidently, at full size, for the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
    [case.scad, case_frontopen_OLD.scad, concept_chain.scad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]
2026-09-03 hardware: quarter-turn bayonet mount, verified against measured geometry
    Replaces the dovetail mount with a quarter-turn bayonet, and rebuilds the
    case around it. Everything here was checked by measuring rendered solids
    rather than by trusting the source's own assertions, because several of
    those assertions turned out to be testing the wrong thing.
    The socket interface is now correct. The rider inspected the physical BM4
    mount: its square PROTRUDES 2 mm and the brass insert sits at the bottom
    of a cavity, so our adapter takes the cavity. Measured 14.5 across flats,
    2.42 corner radius, roof at exactly z 2.20 against the socket's 2.00, so
    the flat faces seat and the square only keys rotation.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
    [bezel.step, bezel.stl, body.step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]
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

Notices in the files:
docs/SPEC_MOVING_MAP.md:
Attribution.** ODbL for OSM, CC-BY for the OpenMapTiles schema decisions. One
